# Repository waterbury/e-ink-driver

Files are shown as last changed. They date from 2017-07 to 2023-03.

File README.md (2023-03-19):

### Open-source hardware design
----------

#### Introduction

E-ink driver board based on designs by @kennethlimcp and others..

swedishhat has a bunch of these: http://wiki.ai-thinker.com/esp32-s

#### Useful writeups 

- [Bringing up a new board from scratch](/Resources/bring-up.md)
- [Checking a new PCB and populating it](/Resources/pcb-checks.md)
- [EAGLE start off and mistakes](/Resources/eagle-notes.md)

#### Resources

- [Hardware product development process](http://conceptspring.com/hardware-product-development-process/)

- [Spark Proto2Prod website](http://www.proto2prod.com/)

- [EAGLE Help](http://web.mit.edu/xavid/arch/i386_rhel4/help/index.htm)

- [Sparkfun EAGLE Settings](https://github.com/sparkfun/SparkFun_Eagle_Settings)

- [3D Board viewer](http://3dbrdviewer.cytec.bg/)

- [KiCad Software](http://www.kicad-pcb.org/)

- [Systematic PCB verification](https://engineering.purdue.edu/ece477/Resources/SystematicPCBVerification.pdf)

- [7 fatal pcb mistakes to avoid by Make](http://makezine.com/2016/08/15/7-fatal-mistakes-avoid-printed-circuit-board-pcb-design/)

- [Board Level Electromagnetic Compatibility](http://www.nxp.com/files/microcontrollers/doc/app_note/AN2321.pdf)

- [The Dropout’s Guide to PCB Trace Antenna Design](http://colinkarpfinger.com/blog/2010/the-dropouts-guide-to-antenna-design/)

- [Antenna Design and RF Layout Guidelines](http://www.cypress.com/file/136236/download)

- [Converting Seeed OPL EagleCAD library to KiCad](https://www.seeed.cc/Converting%20Seeed%20OPL%20EagleCAD%20library%20to%20KiCad-p-1990.html)

- [Wireless Protocols for IoT Devices](http://glowlabs.co/wireless-protocols/)

- [Capacitor temperature and voltage variation](https://www.maximintegrated.com/en/app-notes/index.mvp/id/5527)

- [Minimizing Buck-Boost Converter High-Frequency Switching Noise](http://www.ti.com/lit/an/slva219a/slva219a.pdf)

- [CAN-bus Common High Speed Physical Layer Problems](https://vector.com/portal/medien/cmc/application_notes/AN-ANI-1-115_HS_Physical_Layer_Problems.pdf)

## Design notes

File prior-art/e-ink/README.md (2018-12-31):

Wifi E-ink display
----------

### Introduction

The main motivation for this device comes from the regular use of 16x2 or nokia old-style LCD display. They are nice but too small for a sizeable project that requires a simple but viewable display from a distance.

This also challenges me to try out FPC connector that i have never handled before and at the same time design an entire system comprising from power to display signal driver.

The current revision of **V0.0.3** does not work as the I2C GPIO expander is unable to toggle the control pins at `us` resolution so a re-design has to be done. **V0.1.0** is a WIP to improve **V0.0.2** but is only a WIP and is not a working board as well.

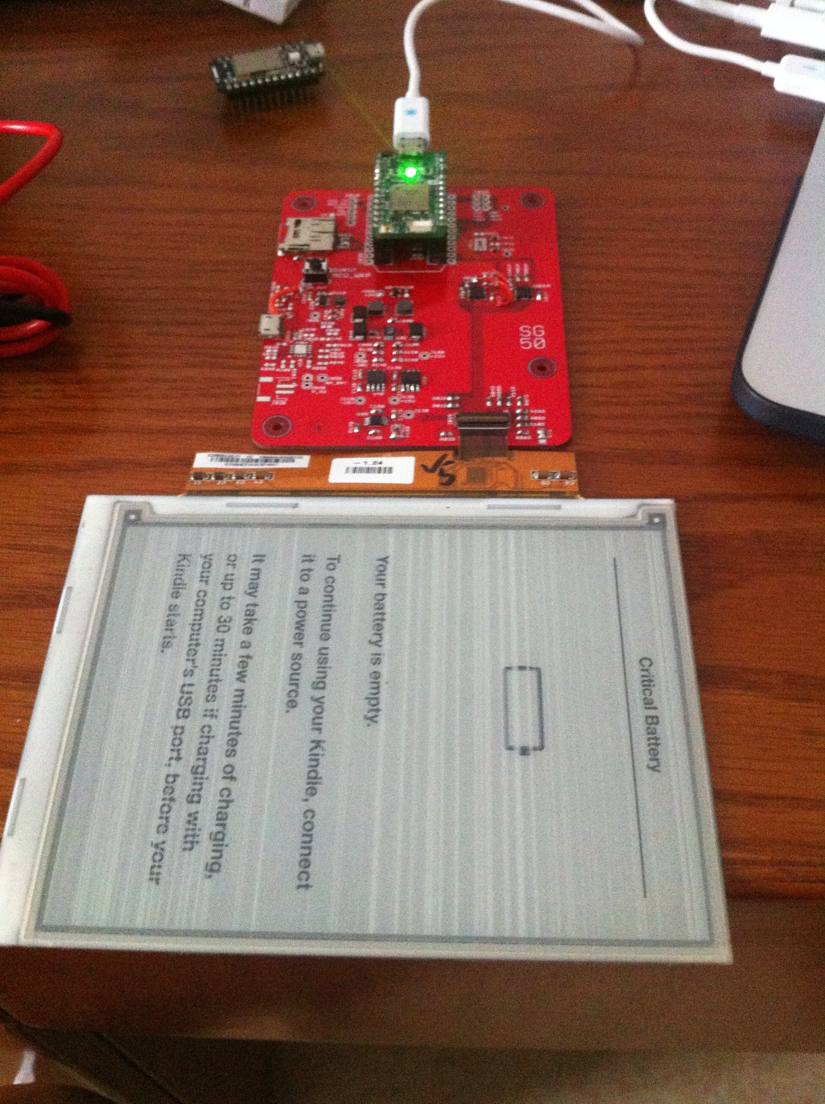
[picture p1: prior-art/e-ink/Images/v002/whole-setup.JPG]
eink-board


#### Power system

- USB +5V or single cell Li-ion
- Battery charging and simultaneous system supply
- 3V3 buck converter for primary rail

##### Input options
- microB USB
- jumper wire (+ and -)

##### E-ink supply notes

A LT1945 DC/DC converter is powered by VBAT from the 1-cell li-ion battery to provide the +22V and -20V required for the Gate supply. The next power stage comprises of a simple LDO (LM78(79)/L15) to generate +15V and -15V for the Source supply. There's a LTSPICE file available in this repository that shows the performance of the LT1945 through simulation. This design comes from the datasheet and the components have been properly sized to have beefy ratings.

There are newer ICs in the market that handles the entire power generation required to drive an e-ink display and they should be utilized in the new revision if they can be bought easily in the market. Otherwise, replacing the LDOs might be a considering to achieve better low power consumption in sleep mode.

VDD and VSS supply for the e-ink is powered using a GPIO as the current draw (according to the notes) is only 1mA and this allows up to turn off the display for power saving.

The SMPS power input is controlled using a simple P-channel MOSFET load switch technique to cut off supply when it is not required.

##### Battery power management design

After much sourcing and finding a part available in the Chinese market, I found the BQ24075 suitable for the job that provides a good mix of features. This IC allows a maximum input voltage of 28V and comes with over-voltage protection! No external inductor is required (compared to BQ24260). There's also 2 status signal that allows the MCU to know if there's an external power source connected and whether the battery is currently charging. This allows us to change the "power mode" of the device with faster go-to-sleep timing when there is not power source attached.

This addition low-cost circuit footprint is added for variety. A MCP7381T is used to charge a single cell Li-ion and the VBAT is directly fed to the system. This, however, does not allow the system to be powered up if a battery is not present.

#### Driver design notes

The e-ink display requires a fair bit of control pins and part of the reason is not fully understanding which pins are in use and necessary for driving. Therefore, to ensure a higher success rate during rev. 0.0.2, consideration is made to hook up all the exposed pins. Pins that are pulled high and low are also wired up with 0 ohm resistors for flexibility to test their purpose or change the pull voltage.

One design considered is to use 2 x 8 GPIO expander; one for the 8 bit data and another for the seldom toggled controls pins. There are 16 port GPIO expander in the market but having the data pins and control pins independent of each other during writes prevents accidental toggling of the incorrect pin that may result in a damaged display.

Another design is to use a separate MCU that connects directly to all the pins available but most of the Arduino options have low FLASH and RAM. The next notch up would result coding in C (MCU running some RTOS) which is too much to handle at this point in time.

The GPIO expander design is implemented for the initial rev to bring up the board with a Spark Core/Photon that is a beefier Arduino variant that allows us to avoid the low level path for now. Using an external MCU would definitely be a better path to take in future revisions. INT pins are not wired up as all the pins are used as OUTPUT.

#### Peripherals

These are implemented in rev 0.0.2:

- Accelerometer to determine screen orientation
- Temperature sensor, duh
- microSD card

future considerations:

- Gyrosensor (why?)
- BLE module (good for proximity control)
- light sensor for ambience detection

#### Casing

A laser cut casing would be great to house a useful demonstration set and avoid risk of damaging it from the hands of others!

#### Future expansion

- Use e-ink display driver IC
- Add in IR touch sensing technology used in latest Kindle
- Backlight will be awesome much

#### Lessons learnt

- Creating new footprints confidently (39-pin FPC connector, QFN-20)
- ULP script "bom.ulp" available to generate the BOM for a project. Makes it easier to manage the ever changing list of components
- ULP script "Unrouted" from Sparkfun will be useful instead of manually browsing through unrouted layer (but not that helpful..)
- need to turn on `STOP` for vias to be exposed without soldermasking
- Forgotten about teardrop ULP
- increase isolate for polygons to 0.012". Sparkfun says that would result in better yield instead of possible short
- it seems like we need to turn on the layers of concern during DRC or it will be missed out. Some silkscreen labels were "violating" some pads/vias and went unnoticed

**v0.0.2**

- need to add thermal vias for battery management IC
- updated battery related ICs label with additional "0" prefix (U01B, U02B, U03B, U04B, U05B)
- `SMPS_CTRL` pin for the LT1945 can only work without populating R12B as the GPIO port on the expander cannot be configured as an open drain to support the pull-up resistor. Have to set in code to use internal pull-up instead. Will need to consider adding an SOT-23 NPN transistor to control the on/off.
- BQ24072/3/4 might better with lower OUT voltage for next stage +3V3 step down
- Use 2K Ohm for R08B to set ILIM for BQ24075
- missed out "insert here" label for J02S
- SJ1 solder jumper can be smaller
- keepout for U03M needs to be included in the design consideration and GERBER generation
- changed OSHW logo to customized for it to be an exposed shiny silver logo :)
- made "SG 50" font a vector, 20% ratio
- incorrect J02M label, was flipped

- spaced out components to be more hand-solderable
- extend the USB pads to be more hand-solderable
- added slide switch
- RST for MCP23008-E needs to be externally biased
- R0xx should be wired to +3V3 instead of EINK_VDD
- some issue with +20v where voltage is present even when disabled

#### Resources

Understanding the wiring for e-ink display would not be possible with the information shared by two pro open-source gentlemen.

- [essential scrap](http://www.essentialscrap.com/eink/index.html)
- [SpriteMods](http://spritesmods.com/?art=einkdisplay)
- [Ti Dev board](http://www.ti.com/tool/TIDM-LPBP-EPAPER)
- [SSD1606 driver](http://www.lcd-module.de/fileadmin/eng/pdf/zubehoer/ssd1606_1_1.pdf)
- [OnSemi driver](http://www.onsemi.com/pub_link/Collateral/ENA2223-D.PDF)
- [Eink reseach paper](http://aoe.scnu.edu.cn/uploadfile/2014/0508/20140508112156532.pdf)
- [STM32L0 discovery board](http://www.st.com/st-web-ui/static/active/en/resource/technical/document/user_manual/DM00118944.pdf)
- [Pebble Time teardown](https://www.ifixit.com/Teardown/Pebble+Time+Teardown/42382)
- [Pebble Watch teardown](https://www.ifixit.com/Teardown/Pebble+Teardown/13319)
- [RePaper code](https://github.com/repaper/gratis)
- [Freescale i.MX50](http://cache.freescale.com/files/32bit/doc/data_sheet/IMX50CEC.pdf)
- [GDE021A1 display project](http://www.jsykora.info/2014/06/epd-display-working/)
- [Amazon Kindle source code](http://www.amazon.com/gp/help/customer/display.html?nodeId=200203720)
- [E-ink display](http://www.buy-lcd.com/index.php?route=product/category&path=2897)
- http://www.eevblog.com/forum/microcontrollers/interfacing-epd-(e-ink)-display-from-kindle-anyone-tried
- [EPSON controller module](http://www.mouser.com/catalog/specsheets/x93ac002_f01__(S4E5B001B00A00_Product_Brief_Rev_1.0)[1].pdf)
- [Epaper shield](http://epapershield.com/index.htm)

- [PVI docs](http://wenku.baidu.com/view/c54385ea6294dd88d0d26b94.html)
- [Epson ppt](http://wenku.baidu.com/view/e451453567ec102de2bd8908.html)

#### Appnote

- MOSFETS in load switch applications(AND9093D)
- Reverse current/battery protection circuit (SLVA139)
- Resistor decade table (dectable)
- [USB disconnect circuit](https://developer.mbed.org/media/uploads/chris/mbed-005.1.pdf)
- [I2C resistor calculation](http://www.ti.com/lit/an/slva689/slva689.pdf)

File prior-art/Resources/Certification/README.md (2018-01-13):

### Certification standards

#### PCB

Printed circuit boards are usually certified with Underwriters Laboratories (UL) standards.

A database is available to check a manufacturer for UL certification at: http://database.ul.com/cgi-bin/XYV/template/LISEXT/1FRAME/index.htm

The UL category code to search for:
- Printed Wiring Boards (ZPMV2)
- Flexible Printed Wiring Boards (ZPXK2)
- Laminates (QMTS2)
- Printed Wiring Boards (QMJU2)

Parameters:
- Flame class
- Maximum operating temperature (MOT)
- Direct Support Requirements (DSR)
- Comparative Tracking Index (CTI)
- Multiple Solder Limits

Tests:
- UL94 - [Standard for Tests for Flammability of Plastic Materials for Parts in Devices and Appliances
Purchase UL 94
](https://standardscatalog.ul.com/standards/en/standard_94_6)

Material:
- [UL PCB Recognition](https://www.ncabgroup.com/wp-content/uploads/2015/03/UL-Emma-Hudson-NCAB-Seminar-2015-03.pdf)

#### Specification
- [MIL-PRF-38535 United States military specification](https://en.wikipedia.org/wiki/MIL-PRF-38535)

#### Manufacturing

- [IPC-A-610 Acceptability of Electronics Assemblies Training and Certification Program](http://www.ipc.org/ContentPage.aspx?pageid=IPC-A-610)
- Solder Paste Inspection, Automated Optical Inspection and X-ray examination are all carried out during manufacture followed by PCB testing and finally burn in testing 

#### Quality
- [ISO 9001:2015](https://www.iso.org/iso-9001-quality-management.html)

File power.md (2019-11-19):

# Power for LG LB060S01-RD02 E-Ink Display

| Rail |  Min  | Nominal |  Max  |
|:----:|:-----:|:---:|:-----:|
| GVEE |  -22V | -20V |  -15V |
| GVDD |  +15V | +22V |  +23V |
| VPOS | +9V | +15V |  +17V |
| VDD  | +2.8V | +3.3V | +3.6V |
| VNEG |  -17V | -15V | -9V |
| VCOM | -2.5V | | -0.5V |

Power on sequence
1. VDD
2. VNEG, GVEE
3. VPOS
4. Input Signals, GVDD

Power off sequence
1. Input Signals
2. GVEE, VGDD, VPOS, VNEG
3. VDD

I _THINK_ the datasheet is trying to say that the timing gap between rails is >= 5ms and <= 100ms

Basically, I think we should either 
(a) assume the shit magically starts up in order
(b) don't apply _any_ power to the display unless a sufficiently long period of time has passed

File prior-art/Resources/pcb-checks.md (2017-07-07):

### Verifying and populating a new PCB

#### Things to prepare
- Schematic printout
- Parts layout/orientation printout
- Multimeter
- Clamping vise (nice to have)
- ye' old tweezer
- Solder spool(0.3mm is ideal for dealing with SMD parts)
- Solder wick-(ed) (this is going to be invaluable)
- Solder paste (if you are reflowing)
- Scrapper (to spread peanut butter..opps Solder paste)

#### Systematic verification steps

**Checking the bare PCB**
- Test for short between power lines. eg. 5V and GND
- Supply power and check that power pins are receiving the correct voltage

**Preparing to populate!**
- Lay out your parts neatly and have an idea of which part gets placed first and which goes next
- Have a spacious work area as entropy will spontaneously increase and things get disorganized
- Place your print-out somewhere within sight for easy referencing

**Populating the PCB (by hand)**
- Start off by populating the smallest and toughest package. eg. QFN before through hole
- **Remember** that **solder flux** is your best friend! Apply sparingly to the pad to be soldered before continuing
- Look out for the polarity and "pin 1" position before soldering down each part
- Solder one "leg" to hold the part in place, double-check that the orientation is correct before continuing. This will save you a ton of heartache/desoldering
- Perfection is great but a burnt component is not. As long as the component is properly in place, (i know it's hard to resist having a perfectly oriented part) move on to the next one!
- If you are not confident that the parts are properly soldered, whip out your trusty multimeter and test for connector from each leg to the respective end-point

***Special notes***
- Solder one part, check for goodness before moving on
- As you solder, visually inspect the board and make sure the part is not "tombed"
- For IC, be sure to apply some pressure to solder them firmly on the pad (not floating)

**Populating the PCB (for reflow)**
- If you are doing this process, you probably have a stencil ready to spread the Solder paste
- Grab some spare pcbs or material and stick them down on the work area to serve as a jig so that the PCB stays in place while you spread solder paste. Imagine something like a "L" shape where the pcb can be pushed against
- Align your stencil and scrap the solder paste through! Place enough solder paste and do a smooth one-time apply.
- It is not recommended to go back and forth too many times so... do it once, do it good! Practice makes perfect for this step
- Once that is done, carefully populate each component before sending the PCB for baking/reflow

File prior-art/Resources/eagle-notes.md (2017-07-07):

EAGLE tips and advice
---

### Grouping things up

If you are a beginner, switching over to the Board view with a whole bunch of components clustered together might be overwhelming. The recent project i worked on has close to 100 components and that required me to do something about it before even beginning to do routing work.

What it did was to refer to the schematic and move things that are supposed to be together...together.

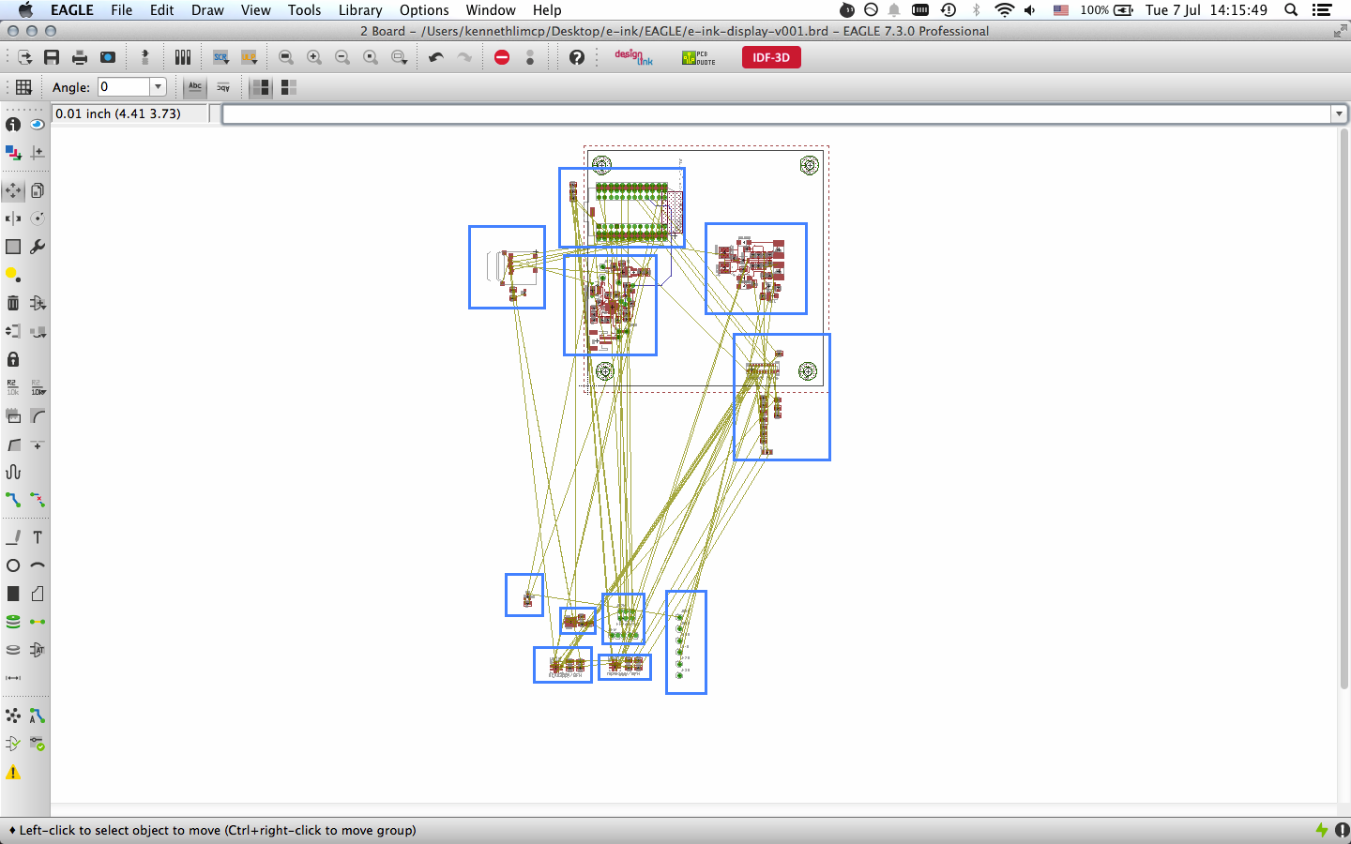
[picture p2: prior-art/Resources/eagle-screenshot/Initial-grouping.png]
group-sections


This is helpful when bypass/decoupling capacitors go to the correction section and placed at where they are designed to be.

### Running a DRC after initial routing

This is a pretty useful tool and a MUST use. Here's some examples of the errors detected by the tool recently.

**insufficient clearance between a via and trace**

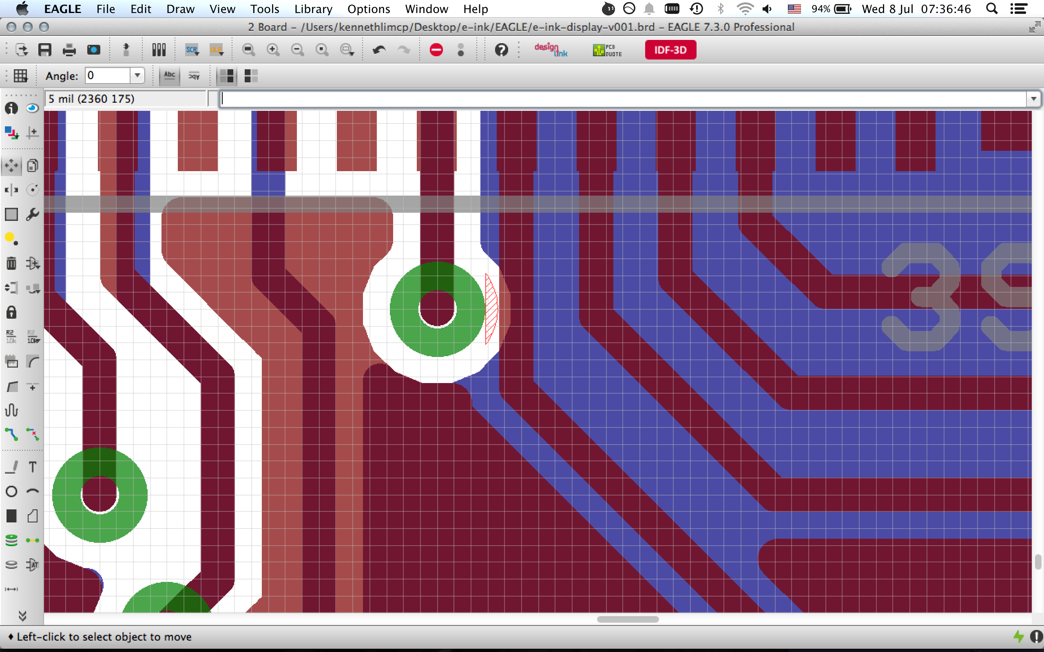
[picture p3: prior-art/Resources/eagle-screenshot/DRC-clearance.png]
DRC-clearance


**trace touching pads along the way**

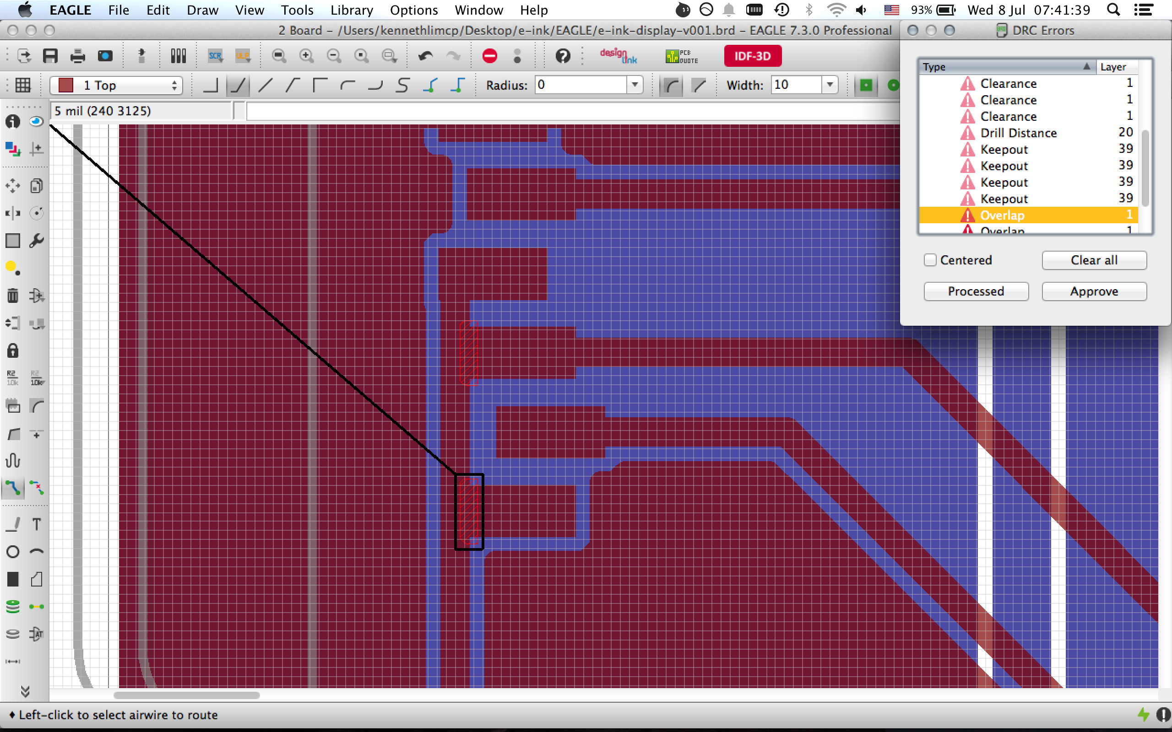
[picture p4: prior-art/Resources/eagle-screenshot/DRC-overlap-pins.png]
DRC-overlap-pins


**trace cutting acrossing another trace**

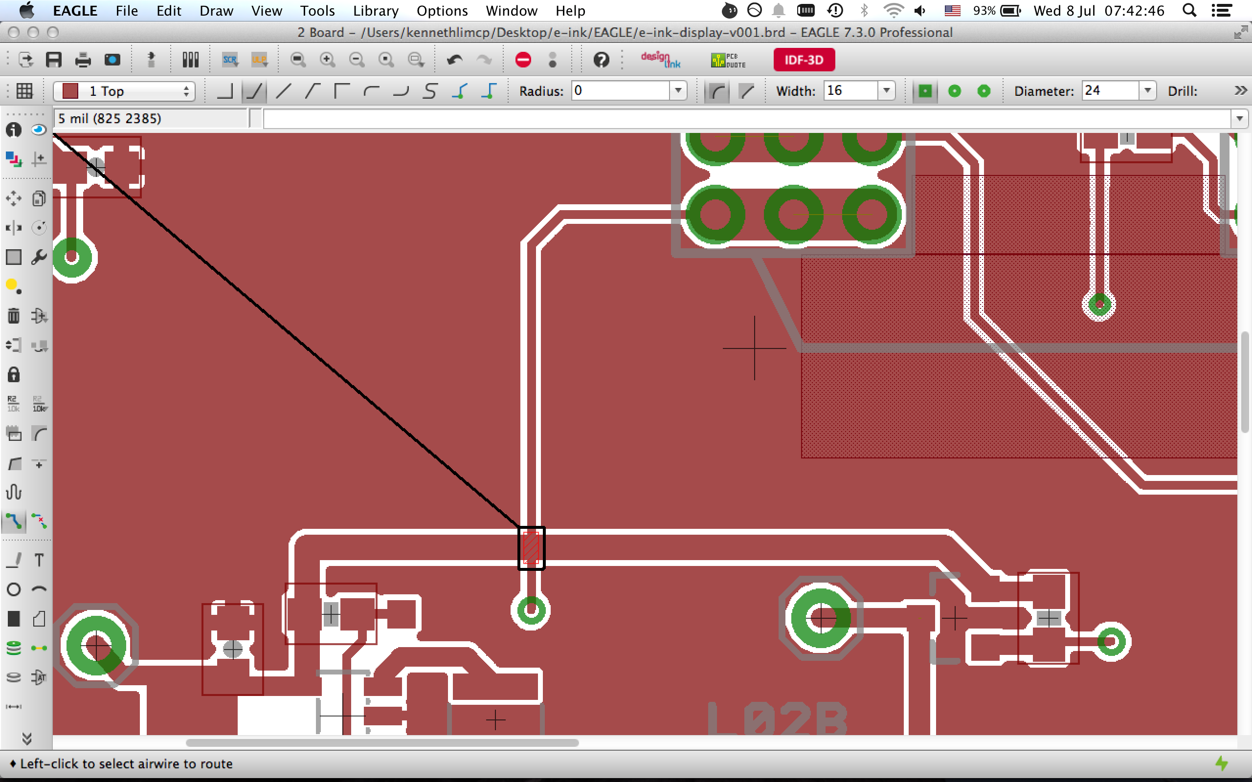
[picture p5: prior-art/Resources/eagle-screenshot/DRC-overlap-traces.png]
DRC-overlap-traces


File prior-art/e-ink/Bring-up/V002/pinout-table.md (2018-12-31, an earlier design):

Battery Management
---

####Input

- VUSB
- Header pins (with diode protection)

####Control pins
- CE (enable/disable charger)
- BM_SYSOFF (con/discon battery to system output)

####Output
- BM_OUT (battery positive voltage)
- PGOOD (external power attached)
- CHG (battery charging)
- ISET (charging current-->voltage)

3V3 Buck regulator
---

####Input
- BM_OUT
- Enable pin

####Output
- +3V3

DC/DC converter
---

####Input
- BM_OUT

####Control pins
- NEG_EN
- POS_EN
- SMPS_CTRL

####Output
- -20V
- +22V

+15V linear regulator
---

####Input
- +22V
####Output
- +15V

-15V linear regulator
---
####Input
- -20V

####Output
- -15V

LM358 Opamp
---

####Input
- +15V
- -15V

####Output
- VCOM negative voltage

e-ink display
---

####Input
- +15V
- -15V
- +22V
- -20V

####Control pins (15)
- D0-D7
- GMODE2
- U1SPV
- U1CKV
- CL
- LE
- OE
- SPH
- E_INK_VDD

####Output
- VCOM negative voltage

GPIO expander (e-ink data line)
---
####Input (ascending)
- D0-D7

####Control pins (15)
- SCL
- SDA
- INT (not using as all will be OUTPUT pins)
- RST

GPIO expander (control line)
---
####Input (ascending)
- CL
- LE
- OE
- SPH
-
-
- NEG_EN (DC/DC)
- POS_EN (DC/DC)

####Control pins (15)
- SCL
- SDA
- INT (not using as all will be OUTPUT pins)
- RST

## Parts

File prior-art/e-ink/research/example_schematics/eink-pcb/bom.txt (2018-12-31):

Order numbers are for Digikey

L1, L2: 22uH					587-2103-1-ND
IC1: LT1945						LT1945IMS#PBF-ND
IC2: MC79L15					MC79L15ABDGOS-ND
IC3: L78L15						497-7278-1-ND
IC4: TPS78230					296-24372-1-ND
IC5: LM358						LM358DGOS-ND
IC6: MCP73831					MCP73831T-2ATI/OTCT-ND
IC7, IC8: 74LV4094				568-2976-5-ND
D1-D3: SS24						SS24T3GOSCT-ND
D4: 0603 LED					
C2, C4, C5, C6, C7, C8: 2U2 >25V!	490-10486-1-ND
C3, C11, C12: 4u7 6.3V			1276-1045-1-ND
C1, C9, C10, C13, C14: 100nF	1276-1857-1-ND (per 1000 bestellen?)
C15, C16: 100uF					1276-1782-1-ND

All resistors 0603
R9: 470 ohm
R15: 1K
R10: 2K
R14: 4K7
R11, R12, R13: 10K
R2, R3: 33K
R5, R6: 39K
R8: 200K
R1: 470K
R4: 560K
R7: 47K
VR1: 100K trimmer PVZ3A473C01R00			490-2016-1-ND

CON1: FH26-39S-0.3SHW	HFQ339CT-ND
CON2: USB header (Hirose)
Q1, Q2:  IRLML6402TRPBF (SOT-23 P-chan mosFET)

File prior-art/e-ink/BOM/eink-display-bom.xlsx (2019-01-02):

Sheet: v002
PROJECT NAME |  | Wifi E-ink Display
BOM VERSION |  | v0.0.2
 | Critical to the PCB Design. Cannot be substituted without changes to PCB
 | Consigned by owner
 | Important to the design. Approved Vendor and P/N can be substituted with equivalent pinout and specifications
 | Non-critical Component. Vendor and P/N should be determined by cost and local availability
Qty | Device | Minimum Specification | Package/Case | Part Designator | MFG. | MFG. PN
1 | FAB PCB | Double Sided, 1.6mm, 1OZ, Electroless Nickel Immersion Gold, Green Solder Mask, White Silkscreen
1 | Battery management | 28V Vmax, system pass-through | QFN-16 | U01B | TI | BQ24075RGTR | 0.8 | 0.8
1 | Buck Converter, SMPS | 3.3V, 600mA | SOIC-8 | U2B | RICHTEK | RT8008-33GB
1 | DC/DC Dual output Converter | Postive and negative output | SOT-223 | U3B | LT | LT1945IMS#PBF | 0.6 | 0.6
1 | REGULATOR | 100mA,-15V, Vin min < 20V | SOIC-8 | U4B | TI | LM79L15ACM/NOPB | 0.6 | 0.6
1 | REGULATOR | 100mA,+15V, Vmax < -22V | SOIC-8 | U5B | TI | LM78L15ACMX/NOPB
1 | OPAMP |  | MSOP-8 | U6B | TI | LM358DGKR
2 | GPIO EXPANDER | I2C, 8 PORT | QFN-20 | U01M,U02M | MICROCHIP | MCP23008-E/ML
1 | PHOTON | BM-09 MODULE | - | U01M | PARTICLE
1 | ACCELEROMETER | 3-axis , 13bit, +-16g | 3 mm × 5 mm × 1 mm LGA | U01S | AD | ADXL345BCCZ
3 | SCHOTTKY DIODE, POWER | Vf 0.5V, 40V, 2A | DO-214AA | D03B,D04B,D05B | ONSEMI | SS24T3G | 0.4 | 1.2
4 | LED | RED | 603 | D01B, D01S, D02B, D06B
2 | INDUCTOR | 22uH, 0.37 DCR, 800mA | 4 x 4 mm | L02B,L03B | MURATA | LQH44PN220MP0L | 0.29 | 0.58
1 | INDUCTOR | 2.2uH, 1.5A | 3 x 3 mm | L01B | TAIYO YUDEN | NR3015T2R2M
1 | CERAMIC CAPACITOR | 4.7pF, Ceramic, 50V, 10%, C0G 0603 | 603 | C10B | MURATA | GRM1885C1H4R7CA01D | 0.01 | 0.01
4 | CERAMIC CAPACITOR | 4.7uF, Ceramic, 50V, 10%, C0G 0603 | 603 | C02B,C03B,C04B,C09B | MURATA | GRM1885C1H4R7CA01D | 0.01 | 0.04
12 | CERAMIC CAPACITOR | 0.1uf, Ceramic, 50V, 10%, X7R | 603 | C01M, C01S, C02M, C03S, C04S, C06B, C07B, C12B, C14B, C15B, C16B, C17B | YAGEO | CC0603KRX7R9BB104 | 0.01 | 0.12
1 | CERAMIC CAPACITOR | 100pf, Ceramic, 50V, 10%, X7R | 603 | C08B | YAGEO | CC0603KRX7R9BB101 | 0.01 | 0.01
3 | CERAMIC CAPACITOR | 1uf, Ceramic, 50V, 10%, 57R | 603 | C01B, C11B, C13B | MURATA | GRM188R61H105KAALD | 0.01 | 0.03
1 | CERAMIC CAPACITOR | 10uf, Ceramic, 50V, 10%, 57R | 603 | C02S | MURATA | GRM188R61H105KAALD | 0.01 | 0.02
1 | CERAMIC CAPACITOR | 22uf, Ceramic, 50V, 10%, 57R | 603 | C05B | MURATA | GRM188R61H105KAALD | 0.01 | 0.01
18 | RESISTOR | 0 Ohm, 1%, 125mW, 50V | 603 | R01D, R01M, R02D, R02M, R03B, R03D, R03M, R04D, R04M, R05D, R05M, R06D, R06M, R07D, R08D, R09D, R10D, R11D |  |  | 0.01 | 0.01
4 | RESISTOR | 1K, 1%, 125mW, 50V | 603 | R01B, R02B,R09B,R01S |  |  | 0.01 | 0.02
1 | RESISTOR | 2K, 1%, 125mW, 50V | 603 | R08B
2 | RESISTOR | 4.7K, 1%, 125mW, 50V | 603 | R08M,R09M
1 | RESISTOR | 470K, 1%, 125mW, 50V | 603 | R13B |  |  | 0.01 | 0.01
1 | RESISTOR | 560K, +-1%, 100mW, 75V | 603 | R15B
2 | RESISTOR | 33K, +-1%, 100mW, 75V | 603 | R14B,R16B
1 | RESISTOR | 200K, +-1%, 100mW, 75V | 603 | R17B |  |  |  | 4.06
2 | RESISTOR | 10K, +-1%, 100mW, 75V | 603 | R10B,R12B,
1 | RESISTOR | 100K, +-1%, 100mW, 75V | 603 | R11B
1 | RESISTOR (Variable) | 100K, +-25%, 100mW,± 250ppm/°C | - | R18B | BOURNS | TC33X-2-104E
1 | CONNECTOR - FPC | 0.3mm pitch, 39 contacts | SMD | J02S | HIROSE | FH26-39S-0.3SHW(05) | 1.6 | 1.6
1 | CONNECTOR - JST | 2PIN, 2MM PITCH, SMD | - | J03B
1 | CONNECTOR - microUSB | 5pin, SMD | - | J07B
10 | HEADER |  | 1x01, 0.1" pitch | J01B, J02B, J05B, J06B, J08B, J09B, J10B, J11B, J12B, J13B
1 | HEADER |  | 1x02, 0.1" pitch | J04B
1 | HEADER |  | 1x05, 0.1" pitch | J01M
1 | HEADER |  | 2x3, 0.1" pitch | J02M
2 | HEADER - FEMALE |  | 1x12, 0.1" pitch | U03M
1 | P-CHANNEL MOSFET | Rds 0.065, VDSS = -20V, -3.7A | SOT-23 | Q01B | IR | IRLML6402TRPbF
1 | SOCKET | micoSD, SMD | - | J01S
1 | E-INK DISPLAY | 6", 39 PIN | 6" | - | PRIMEVIEW | ED060SC4
1 | TACT SWITCH | 4 PIN | - | SW01M
1 | BATTERY HOLDER | PTH, CR2302, 20mm height |  | J03M
 |  |  |  | Parts count: | 99

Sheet: CHANGELOG
Subject: | BOM ECO
Project Name: | WIFI E-INK DISPLAY
BOM Rev.: | V0.0.3
PCB Rev.: | V0.0.1
Date | 2015-07-15
Prepared by: | Lim Chen Pin Kenneth
Project Name
Item | BOM Revision |  | Project Name | Change Details | Date | Responsible
 | Old | New
1 | 0 | 0.0.1 | WIFI E-INK DISPLAY | Initial Entry for all components (new spin up) | 2015-03-15 | KLCP
2 | 0.0.1 | 0.0.2 | WIFI E-INK DISPLAY | changed R6,R7 to C10, C11 for reguators | 2015-07-02 | KLCP
3 | 0.0.2 | 0.0.3 | WIFI E-INK DISPLAY | updated labels and components | 2015-07-06 | KLCP
4
5
6
7
8
9
10
11
12
13
14
15
16
17
18
19
20
21
22
23
24
25
26
27
28
29
30
31
32
33
34
35
36
37
38
39
40
41
42
43
44
45
46
47
48
49
50
51
52
53
54
55
56
57
58
59
60
61
62
63
64
65
66
67
68
69
70
71
72
73
74
75
76

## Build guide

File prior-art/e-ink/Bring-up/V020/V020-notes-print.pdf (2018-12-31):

### Bring-up notes

**Major components populating**

- [ ] microUSB (this was nasty in V002)
- [ ] FPC connector
- [ ] BM IC
- [ ] LT1945
- [ ] LM358

**Test sequence**

- [ ] 3V3 SMPS regulator
- [ ] jumper +5V to BM_SUPPLY
- [ ] measure the 3V# test-point
- [ ] BMIC
- [ ] battery should charge as designed upon USB insertion
- [ ] See if SUPPLY led lights up with USB presence
- [ ] CHG should light up with Batt attached
- [ ] DC/DC converter
- already proven working but nevertheless we check it
- Power up and make sure no voltage at J06B
- wire TP1 to ground to turn on Q01B
- Check that only J07B has -20V and J08B is 0V
- wire TP2 to ground and check J08B for +22V
- [ ] Linear regulators
- Nothing much here. Populate and measure
- J09B, -15V
- J10B, +15V
- [ ] VCOM Opamp
- populate and measure J11B while turning trimmer at R18B
- [ ] MCU
- [ ] Populate U01M, the STM32
- [ ] Crystals Y01M, Y02M next
- [ ] Decoupling caps, C05M to C10M
- [ ] RGB led, D02M and R01M to R03M
- [ ] Blue led, D01M and R05M
- [ ] Buttons!
- [ ] USB disconnect circuit
- we will come back to test the alt circuitry next time
- JTAG header
- [ ] MCU testing
- [ ] wire up STlinkV2 to JTAG header
- [ ] power up the board via USB as well
- [ ] attempt to flash bootloader code and pray that everything works well!
- [ ] Eink components
- [ ] just all the remaining resistors and decoupling caps to go on
- [ ] Last bit
- [ ] Accelerometer
- [ ] SD socket
- [ ] battery holder
- [ ] FTDI header
- Official tests
- [ ] make sure all the GPIOs are correctly configured
- [ ] MODE button test
- [ ] DC/DC power control tests
- [ ] Battery indicator input reading
- [ ] time to insert the Eink!

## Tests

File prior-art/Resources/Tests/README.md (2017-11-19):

#### Board level

- Solder Paste Inspection
- Automated Optical Inspection 
- X-ray examination

#### Product level

- Shock and vibration
- EMC / EMI
- UL
- Ex (ATEX Equipment Directive 2014/34/EU)
- DNV
- Burn-in
- Thermal Cycling (JESD22-A104 , IPC 9701)

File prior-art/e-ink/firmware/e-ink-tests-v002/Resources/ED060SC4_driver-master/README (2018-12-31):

1. Introduction

This is a driver for ED060SC4 800x600 e-ink display panel manufactured by
Prime View. Note that this driver uses a direct connection to the panel from
the processor; it does not use a separate controller chip between the processor
and the panel.

To use the driver, you need to be able to control the following signals from
your processor:

Gate driver: SPV, CKV, GMODE.
Source driver: CL, LE, OE, SPH, D0-D7.
Power supply: +-15V, +22V, -20V, digital Vdd

The file "example_schematics.png" shows how to connect the signals to e.g. a
STM32L151 microcontroller. It also includes an example circuit for providing
the panel supply voltages.

Note that the larger panels (such as the 800x600) consist of multiple segments
with separate gate driver signals. These can be daisy chained as shown in the
example schematic.

Please see here for more information on the panel:
http://essentialscrap.com/eink/

2. Frame buffer emulation

Because there is not enough memory to store a full frame buffer on the
processor, this driver emulates a frame buffer by storing the display data in
blocks. It will buffer up to EINK_NUMBUFFERS blocks and then write them to the
screen. The following #defines control the buffering. Larger numbers will
result in faster drawing, but also use more RAM on the processor:

#define EINK_BLOCKWIDTH 20    // Width of a single block in buffer
#define EINK_BLOCKHEIGHT 20   // Height of a single block in buffers
#define EINK_NUMBUFFERS 40    // Number of blocks to buffer

After drawing your images, you should flush the buffers using the following
command:

    #include <ed060sc4.h>
    gdispControl(GDISP_CONTROL_FLUSH, 0);

The buffers are also flushed whenever you turn the display off using:

    gdispSetPowerMode(powerOff);

3. Display clearing and writing waveforms

This driver does not know the official Prime View waveforms for driving the
display, mostly because those are trade secrets and not publicly available.
Instead, it uses reverse engineered waveforms that are mostly functional.

The following #defines control the waveforms:

#define EINK_BLINKCLEAR TRUE      // Clear to opposite color first
#define EINK_CLEARCOUNT 10        // Number of sweeps to clear the display
#define EINK_WRITECOUNT 4         // Number of sweeps when writing to display

Increasing the clearcount and writecount can improve contrast, but will also
slow down the drawing and use more power.

4. Clock speeds

Because the driver bit bangs the display, the clock frequency of the processor
is quite significant. This is controlled by EINK_CLOCKDELAY variable. Set it
so that the delay is atleast 50 nanoseconds.

5. Support for other kinds of panels

Most of the Prime View panels should work using this driver, but only ED060SC4
has been tested so far. Some points of consideration:

- Some displays may use 4 bits per pixel. The driver currently assumes 2 bits
  per pixel.
- Larger displays may require some other way of daisy chaining than shown in
  the example schematics.

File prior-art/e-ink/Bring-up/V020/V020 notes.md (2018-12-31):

### Key changes from V0.0.2
- Using a STM32F103RBT6 with direct GPIO connection
- breakout most pins
- MODE and Reset button
- JTAG, UART headers
- SPI test points
- separated ground plane for battery charging, DC/DC module and MCU

### To prepare
- [ ] Schematic print-out
- [ ] Parts
- [ ] Placement diagram
- [ ] this notes

### Bring-up notes

**Major components populating**

- [ ] microUSB (this was nasty in V002)
- [ ] FPC connector
- [ ] BM IC
- [ ] LT1945
- [ ] LM358

**Test sequence**

- [ ] 3V3 SMPS regulator
  - [ ] jumper +5V to BM_SUPPLY
  - [ ] measure the 3V# test-point

- [ ] BMIC
  - [ ] battery should charge as designed upon USB insertion
  - [ ] See if SUPPLY led lights up with USB presence
  - [ ] CHG should light up with Batt attached

- [ ] DC/DC converter
  - already proven working but nevertheless we check it
  - Power up and make sure no voltage at J06B
  - wire TP1 to ground to turn on Q01B
  - Check that only J07B has -20V and J08B is 0V
  - wire TP2 to ground and check J08B for +22V

- [ ] Linear regulators
  - Nothing much here. Populate and measure
  - J09B, -15V
  - J10B, +15V

- [ ] VCOM Opamp
  - populate and measure J11B while turning trimmer at R18B

- [ ] MCU
  - [ ]  Populate U01M, the STM32
  - [ ]  Crystals Y01M, Y02M next
  - [ ]  Decoupling caps, C05M to C10M
  - [ ]  RGB led, D02M and R01M to R03M
  - [ ]  Blue led, D01M and R05M
  - [ ]  Buttons!
  - [ ] USB disconnect circuit
  - we will come back to test the alt circuitry next time
  - JTAG header

- [ ]  MCU testing
  - [ ] wire up STlinkV2 to JTAG header
  - [ ] power up the board via USB as well
  - [ ] attempt to flash bootloader code and pray that everything works well!

- [ ] Eink components
  - [ ] just all the remaining resistors and decoupling caps to go on

- [ ] Last bit
  - [ ] Accelerometer
  - [ ] SD socket
  - [ ] battery holder
  - [ ] FTDI header

- Official tests
  - [ ] make sure all the GPIOs are correctly configured
  - [ ] MODE button test
  - [ ] DC/DC power control tests
  - [ ] Battery indicator input reading
  - [ ] time to insert the Eink!

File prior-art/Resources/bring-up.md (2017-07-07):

Steps taken
---

### Plan out the high level features

eg.

- Wifi enabled
- Wireless charging
- Battery management
- orientation detection

### Select all the key ICs

- ensure that parts are source-able
- study known designs (eg. adafruit, sparkfun, bunniestudios) and evaluate the best IC for that project
- select the best MCU for the job

### Prepare the project files

- Follow the current directory tree and create a new forked version
- start off with a `0.0.1` schematic design
- use a `FRAME-A4L` from Sparkfun for the layout
- create the global attributes (CNAME, CREVISION, DESIGNER)
- give that page a description of what it contains

### Start off laying out the power module
- This will be the best place to kick off!
- Create them and label the NET with the appropriate voltage values

### Key points

- Decoupling caps everywhere. Every time an IC is placed, a bypass/decoupling Cap should follow next.
- Think of pins where flexibility is required and use a 0604 0 Ohm resistor.
- Come out with a `pin-out table` if there are too many pins to be inter-connected.
- Save each datasheet (MANU-SHORTFORM_PART-NO) as you work so that you don't forget
- Write the `README.md` as you go or even at the beginning of the project so that key features are decided before starting work. This helps me decide which IC containing the required features is used.
- Write out a checklist on paper and tick them when you are done. Yeah i know digital is cool but pen and paper is rock solid.

### Some dimensions

- For silkscreen, mm, 1.27, 20%, Vector font works great
- Via, inches, round, Drill 0.01968504, Diameter 0.05
- Via, mm, round, Drill 0.5mm, Diameter 1.27mm
- For polygon, set **isolate** to `0.012inch/12mil"`
- For routing, mil, 12

### Labels

- IC                (Uxx/B/M/C/R), where the suffix tells which module it relates to eg B is for battery
- Resistor          (Rxx/B/M/C/R)
- Capacitor         (Cxx/B/M/C/R)
- Inductor          (Lxx/B/M/C/R)
- Diode/LED         (Dxx/B/M/C/R)
- FET/Transistor    (Qxx/B/M/C/R)
- Header/Connectors (Jxx/B/M/C/R)
- Switch            (SWxx/B/M/C/R)

### Checks after initial routing completion

- turn off layers and look for "unrouted" wires and see what's going on
- Run a DRC check
- smash all the labels and change to 1.016, 20%, vector, mm as a minimum
- Add other labels like "+" for battery, jumper labels etc.
- finalize mounting hole position by entering co-ordinates manually for accuracy
- Add in license and OSHW logo, designer name, designed in Singapore, date, revision

```text
Copyrights: CC-BY-SA 3.0
Designed in Singapore 07/15
Project name rev x.x.x
Apache License 2.0
@kennethlimcp
````

- print-out and check for silkscreen visibility
- final DRC rule cos it does not hurt
- make a copy of the `.sch` and `.brd` and run the `teardrop` ULP. That will make the vias/pads stronger with increased trace surface area
- zip up all the GERBERS!

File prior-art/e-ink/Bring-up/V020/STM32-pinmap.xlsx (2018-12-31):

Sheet: F103RBT6
Label | STM32 No | Remarks | 5 V? | ADC | TIMER | UART | SPI | JTAG | I2C | Core HW | Eink desp | Eink No
BOOT0 | 60 | BOOT0 |  |  |  |  |  |  |  |  | VNEG -15v | 1 | DIRECT
NRST | 7 |  |  |  |  |  |  |  |  |  | VPOS +15V | 2 | DIRECT
PA00 | 14 | WKUP |  | ADC12_IN0 | TIM2_CH1_ETR | USART2_CTS |  |  |  | A0 | VSS | 3 | DIRECT
PA01 | 15 |  |  | ADC12_IN1 | TIM2_CH2 | USART2_RTS |  |  |  | A1 | VDD | 4 | DIRECT
PA02 | 16 |  |  | ADC12_IN2 | TIM2_CH3 | USART2_TX |  |  |  | TX | CL | 5 | DIRECT
PA03 | 17 |  |  | ADC12_IN3 | TIM2_CH4 | USART2_RX |  |  |  | RX | LE | 6 | DIRECT
PA04 | 20 |  |  | ADC12_IN4 |  | USART2_CK | SPI1_NSS |  |  | A2 | OE | 7 | DIRECT
PA05 | 21 |  |  | ADC12_IN5 |  |  | SPI1_SCK |  |  | A3 | SHR | 8 | NC/DIRECT
PA06 | 22 |  |  | ADC12_IN6 | TIM3_CH1 |  | SPI1_MISO |  |  | A4 | CE1 | 9 | NC/GND
PA07 | 23 |  |  | ADC12_IN7 | TIM3_CH2 |  | SPI1_MOSI |  |  | A5 | CE2 | 10 | NC/3V3
PA08 | 41 | MCO | YES |  | TIM1_CH1 | USART1_CK |  |  |  | LED2 | SPH | 11 | DIRECT
PA09 | 42 |  | YES |  | TIM1_CH2 | USART1_TX |  |  |  | LED3 | D0 | 12 | DIRECT
PA10 | 43 |  | YES |  | TIM1_CH3 | USART1_RX |  |  |  | LED4 | D1 | 13 | DIRECT
PA11 | 44 | CANRX | YES |  | TIM1_CH4 | USART1_CTS |  |  |  | USBDM | D2 | 14 | DIRECT
PA12 | 45 | CANTX | YES |  | TIM1_ETR | USART1_RTS |  |  |  | USBDP | D3 | 15 | DIRECT
PA13 | 46 | JTMS | YES |  |  |  |  |  | D7 |  | D4 | 16 | DIRECT
PA14 | 49 | JTCK | YES |  |  |  |  |  | D6 |  | D5 | 17 | DIRECT
PA15 | 50 | JTDI | YES |  |  |  |  |  | D5 |  | D6 | 18 | DIRECT
PB00 | 26 |  |  | ADC12_IN8 | TIM3_CH3 |  |  |  |  | A6 | D7 | 19 | DIRECT
PB01 | 27 |  |  | ADC12_IN9 | TIM3_CH4 |  |  |  |  | A7 | NC | 20 | NC
PB02 | 28 | BOOT1 | YES |  |  |  |  |  |  | BTN | NC | 21 | NC
PB03 | 55 | JTDO | YES |  |  |  |  |  |  | D4 | VCOM | 22 | DIRECT
PB04 | 56 | JNTRST | YES |  |  |  |  |  |  | D3 | GVDD | 23 | DIRECT
PB05 | 57 |  |  |  |  |  |  |  | I2C1_SMBAl | D2 | GVEE | 24 | DIRECT
PB06 | 58 |  | YES |  | TIM4_CH1 |  |  |  | I2C1_SCL | D1 | NC | 25 | NC
PB07 | 59 |  | YES |  | TIM4_CH2 |  |  |  | I2C1_SDA | D0 | NC | 26 | NC/VEPD_G_-17V
PB10 | 29 |  | YES |  |  | USART3_TX |  |  | I2C2_SCL | USB_DISC | GMODE2 | 27 | DIRECT
PB11 | 30 |  | YES |  |  | USART3_RX |  |  | I2C2_SDA | WIFI_INT | GMODE1 | 28 | GMODE2
PB12 | 33 |  | YES |  | TIM1_BKIN | USART3_CK | SPI2_NSS |  | I2C2_SMBAl | WIFI_CS | RL | 29 | NC/DIRECT
PB13 | 34 |  | YES |  | TIM1_CH1N | USART3_CTS | SPI2_SCK |  |  | SPI_SCK | U1CE2 | 30 | 3V3
PB14 | 35 |  | YES |  | TIM1_CH2N | USART3_RTS | SPI2_MISO |  |  | SPI_MISO | U1CE1 | 31 | GND
PB15 | 36 |  | YES |  | TIM1_CH3N |  | SPI2_MOSI |  |  | SPI_MOSI | U1SPV | 32 | U2SPV
PB08 | 61 |  | YES |  | TIM4_CH3 |  |  |  |  | WIFI_EN | U1CKV | 33 | U2CKV
PB09 | 62 |  | YES |  | TIM4_CH4 |  |  |  |  | MEM_CS | VBORDER | 34 | GND/VOLTAGE
PC00 | 8 |  |  | ADC12_IN10 |  |  |  |  |  |  | U2CE2 | 35 | 3V3
PC01 | 9 |  |  | ADC12_IN11 |  |  |  |  |  |  | U2CE1 | 36 | 3V3
PC02 | 10 |  |  | ADC12_IN12 |  |  |  |  |  |  | U2SPV | 37 | U1SPV
PC03 | 11 |  |  | ADC12_IN13 |  |  |  |  |  |  | U2CKV | 38 | U1CKV
PC04 | 24 |  |  | ADC12_IN14 |  |  |  |  |  |  | NC | 39 | NC
PC05 | 25 |  |  | ADC12_IN15
PC06 | 37 |  | YES
PC07 | 38 |  | YES |  |  |  |  |  |  |  | SMPS_EN |  | Open-drain
PC08 | 39 |  | YES |  |  |  |  |  |  |  | POS_EN |  | Active high
PC09 | 40 |  | YES |  |  |  |  |  |  |  | NEG_EN |  | Active high
PC10 | 51 |  | YES
PC11 | 52 |  | YES
PC12 | 53 |  | YES
PC13 | 2 | Tamper-RTC
PC14 | 3 | OSC32_IN
PC15 | 4 | OSC32_OUT
PD00 | 5 | OSC_IN | YES
PD01 | 6 | OSC_OUT | YES
PD02 | 54 |  | YES |  | TIM3_ETR
VBAT | 1
VDD_1 | 32
VDD_2 | 48
VDD_3 | 64
VDD_4 | 19
VDDA | 13
VSS_1 | 31
VSS_2 | 47
VSS_3 | 63
VSS_4 | 18
VSSA | 12

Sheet: Pin Map
Label | STM32 No |  | DIRECTION
BOOT0 | 60 | NIL
NRST | 7
PA00 | 14 | D0 | O
PA01 | 15 | D1 | O
PA02 | 16 | D2 | O
PA03 | 17 | D3 | O
PA04 | 20 | D4 | O
PA05 | 21 | D5 | O
PA06 | 22 | D6 | O
PA07 | 23 | D7 | O
PA08 | 41 | RGB_BLUE | O
PA09 | 42 | RGB_RED | O | EINK
PA10 | 43 | RGB_GREEN | O | JTAG
PA11 | 44 | MCU_USBM | - | SPI/I2C/USB
PA12 | 45 | MCU_USBP | - | NC
PA13 | 46 | JTMS | I | DC/DC
PA14 | 49 | JTCK | I
PA15 | 50 | JTDI | I | BMIC
PB00 | 26 | BM_PGOOD | I
PB01 | 27 | BM_CHG | I
PB02 | 28 | NC
PB03 | 55 | JTDO | I
PB04 | 56 | TNTRST | I
PB05 | 57 | USB DISC | Open-drain
PB06 | 58 | MCU_SCL_1 | Open-drain
PB07 | 59 | MCU_SDA_1 | Open-drain
PB08 | 61 | MODE BUTTON | I
PB09 | 62 | EINK_VDD | O
PB10 | 29 | MCU_TX_3 | -
PB11 | 30 | MCU_RX_3 | -
PB12 | 33 | SD_CS | O
PB13 | 34 | SPI_SCK | -
PB14 | 35 | SPI_MISO | -
PB15 | 36 | SPI_MOSI | -
PC00 | 8 | CL | O
PC01 | 9 | LE | O
PC02 | 10 | OE | O
PC03 | 11 | SHR | O
PC04 | 24 | SPH | O
PC05 | 25 | GMODE2 | O
PC06 | 37 | RL | O
PC07 | 38 | SPV | O
PC08 | 39 | VBORDER | O
PC09 | 40 | CKV | O
PC10 | 51 | SMPS_CTRL | Open-drain
PC11 | 52 | POS_EN | O
PC12 | 53 | NEG_EN | O
PC13 | 2 | POS_CTRL | Open-drain
PC14 | 3 | OSC32_IN | -
PC15 | 4 | OSC32_OUT | -
PD00 | 5 | OSC_IN | -
PD01 | 6 | OSC_OUT | -
PD02 | 54 | NC
VBAT | 1 | BATT | -
VDD_1 | 32 | 3V3 | -
VDD_2 | 48 | 3V3 | -
VDD_3 | 64 | 3V3 | -
VDD_4 | 19 | 3V3 | -
VDDA | 13 | 3V3 | -
VSS_1 | 31 | GND | -
VSS_2 | 47 | GND | -
VSS_3 | 63 | GND | -
VSS_4 | 18 | GND | -
VSSA | 12 | GND | -

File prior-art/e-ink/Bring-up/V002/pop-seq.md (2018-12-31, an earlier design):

###Bring up sequence and testing steps

####Battery management module

Getting the BQ24075 to work first will be the first priority as all the other subsystems require this primary rail to be up and running.

- R05B to be populated with a 0 Ohm resistor to enable charging
- Measure Battery voltage at J05B
- 2-pin jumper needed at J04B as a physical switch to join Li-ion to system
- Measure BM_OUT at J02B
- Plug in microUSB at J07B and measure +5V at J01B
- Check that D01B lights up when microUSB power source is present
- Check that D02B lights up to indicate battery charging

####3.3V buck regulator

Pretty straight forward to bring this up. Measure at J06B for +3.3V

####DC/DC converter module

- Do not populate R12B due to control issues not able to do open-drain output
- Measure at J08B to have no voltage since Q01B load switch is disabled by default
- Need to pull down SMPS_CTRL pin but that will require the GPIO Expander. Jumper to ground for testing
- Measure J09B for -20V
- Measure J10B for +22V

####Linear regulators

- Populate the LM7815 first and measure J12B for +15V
- Populate the LM7915 and measure -15V at J11B

####OpAmp module

- Populate U6B and vary Trimpot R18B while measuring voltage at J13B

####GPIO Expander

- Hard to test without the MCU
- Probably monitor current and note for any spike?
- Run a series of GPIO output toggling tests and do a pull-up test as well

####MCU - Photon

- Check that the 3.3V and GND are properly routed and no input on the VIN or other pins
- Check for continuity for I2C lines
- Check for BM_PGOOD (A6), GMODE2 (D2), U1CKV (D5), U1SPB (D4). EINK_VDD(A2), BM_CHG (A0)

####microSD

- Check that LED flickers during read/write

####Accelerometer

- run a read test and rotate the PCB around to test changes

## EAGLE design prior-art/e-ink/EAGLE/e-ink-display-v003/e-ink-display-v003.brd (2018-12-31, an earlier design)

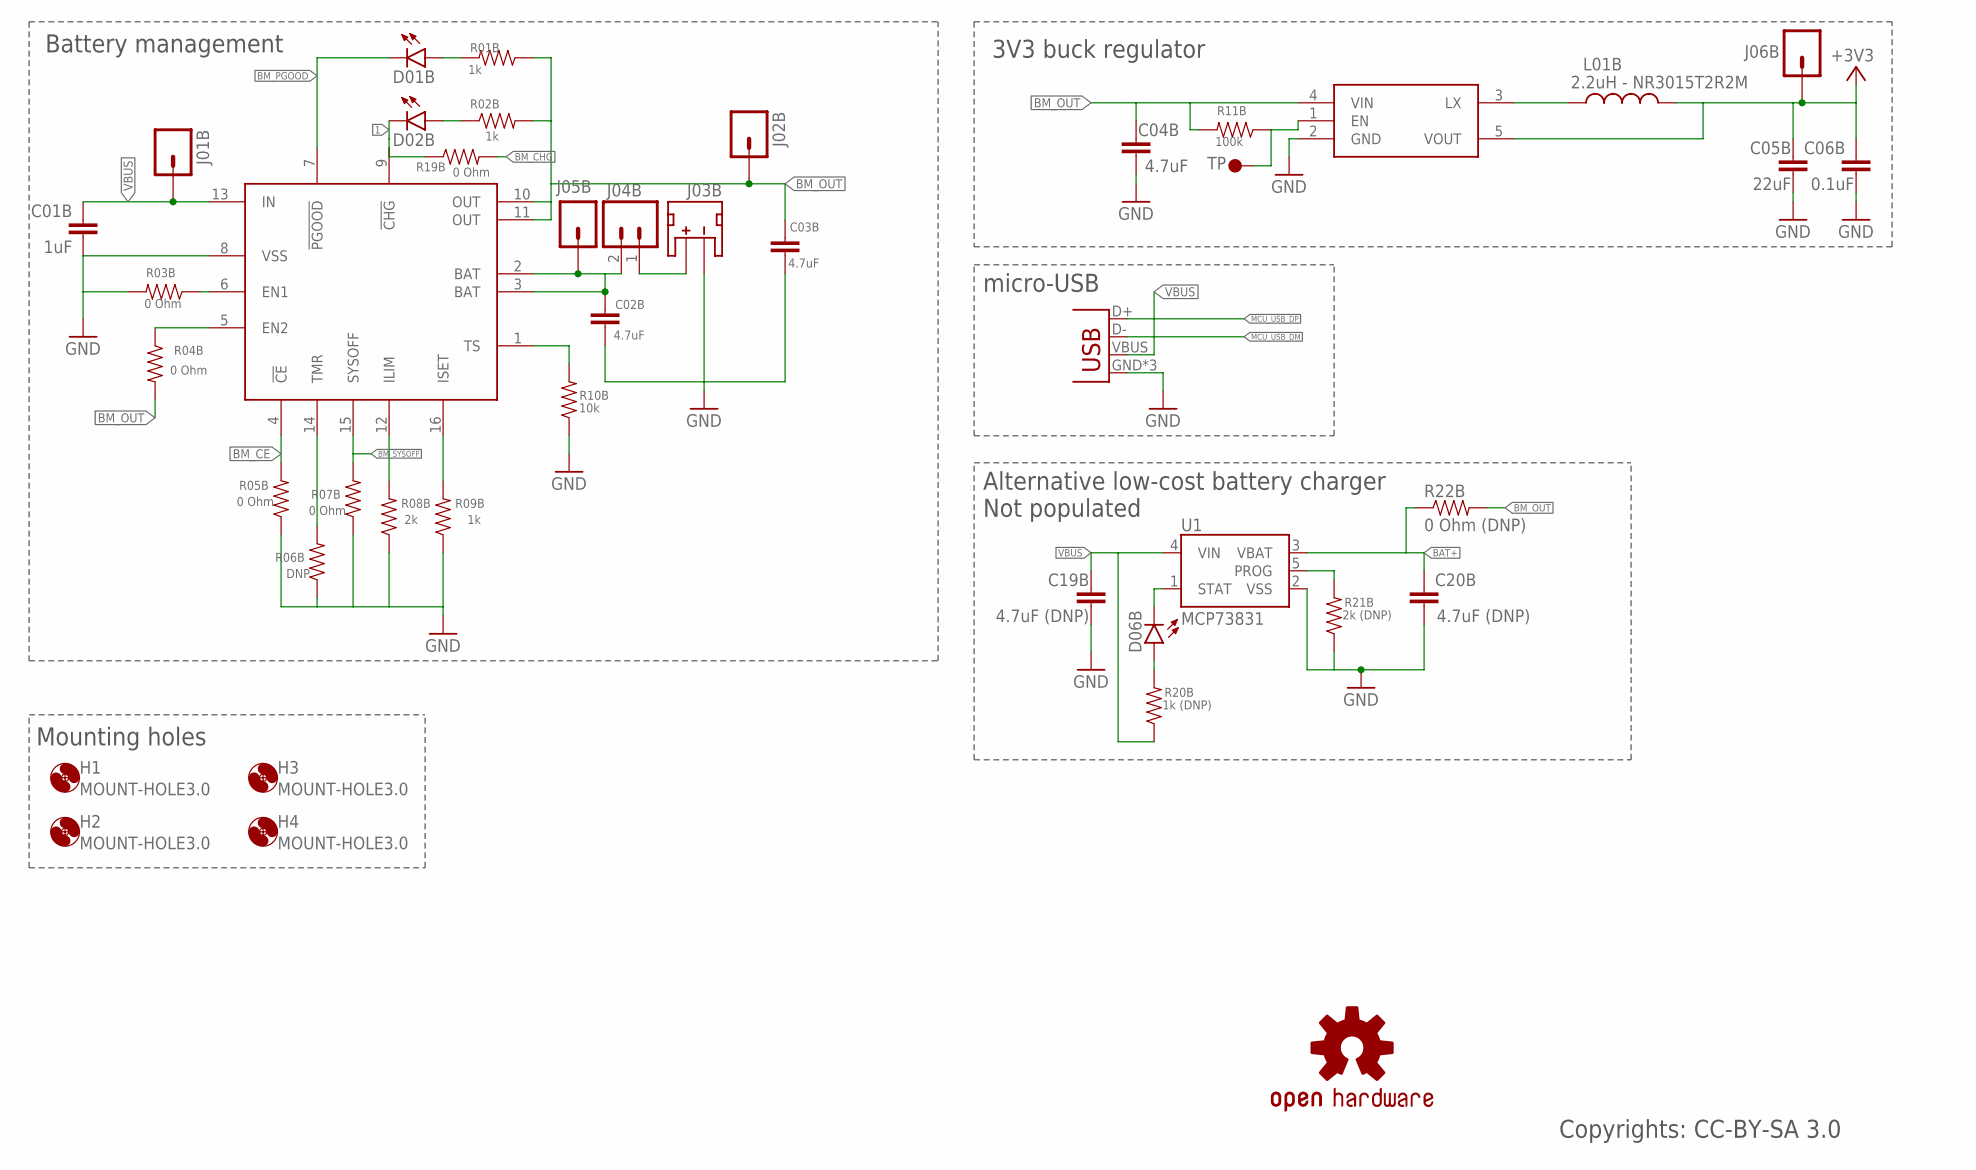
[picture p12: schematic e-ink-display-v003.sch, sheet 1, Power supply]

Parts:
C01B: 1uF; 0603-CAP
C02B, C03B, C04B: 4.7uF; 0603-CAP
C05B: 22uF; 0603-CAP
C06B: 0.1uF; 0603-CAP
C19B, C20B: 4.7uF (DNP); 0603-CAP
D01B, D02B, D06B: LED0603; LED-0603
H1, H2, H3, H4: MOUNT-HOLE3.0; 3,0
J01B, J02B, J05B, J06B: M01PTH; 1X01
J03B: JST_2MM_MALE; JST-2-SMD
J04B: M02PTH; 1X02
J07B: USBUSB-MICROB-SLOT-HOLE; USB-MICROB-SLOT-HOLE
L01B: 2.2uH - NR3015T2R2M; INDUCTOR-NR3015
LOGO1: OSHW-LOGOPAD; OSHW-LOGO-M-PAD
R01B, R02B, R09B: 1k; 0603-RES
R03B, R04B, R05B, R07B, R19B: 0 Ohm; 0603-RES
R06B: DNP; 0603-RES
R08B: 2k; 0603-RES
R10B: 10k; 0603-RES
R11B: 100k; 0603-RES
R20B: 1k (DNP); 0603-RES
R21B: 2k (DNP); 0603-RES
R22B: 0 Ohm (DNP); 1206
TP01B: TP1; TP35_BOT
U1: MCP73831; SOT23-5
U01B: BQ24075; QFN-16
U02B: R8008-33; SOT23-5

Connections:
1: D02B.C, R19B.1, U01B.9 (!CHG)
+3V3: C05B.2, C06B.2, J06B.1, L01B.2, U02B.5 (VOUT); also elsewhere on the board
BAT+: C20B.2, J03B.2 (+), J04B.1, R22B.1, U1.3 (VBAT)
BM_BAT: C02B.2, J04B.2, J05B.1, U01B.2 (BAT), U01B.3 (BAT)
BM_CE: R05B.2, U01B.4 (!CE)
BM_CHG: R19B.2; also elsewhere on the board
BM_OUT: C03B.2, C04B.2, J02B.1, R01B.1, R02B.2, R04B.2, R11B.2, R22B.2, U01B.10 (OUT), U01B.11 (OUT), U02B.4 (VIN); also elsewhere on the board
BM_PGOOD: D01B.C, U01B.7 (!PGOOD); also elsewhere on the board
BM_SYSOFF: R07B.2, U01B.15 (SYSOFF)
GND: C01B.1, C02B.1, C03B.1, C04B.1, C05B.1, C06B.1, C19B.1, C20B.1, J03B.1 (-), J07B.GND, J07B.MT1 (GND), J07B.MT2 (GND), R03B.2, R05B.1, R06B.1, R07B.1, R08B.1, R09B.1, R10B.1, R21B.1, U1.2 (VSS), U01B.8 (VSS), U02B.2 (GND); also elsewhere on the board
MCU_USB_DM: J07B.D-
MCU_USB_DP: J07B.D+
unnamed: R08B.2, U01B.12 (ILIM)
unnamed: R09B.2, U01B.16 (ISET)
unnamed: R04B.1, U01B.5 (EN2)
unnamed: R03B.1, U01B.6 (EN1)
unnamed: R06B.2, U01B.14 (TMR)
unnamed: R10B.2, U01B.1 (TS)
unnamed: D02B.A, R02B.1
unnamed: D01B.A, R01B.2
unnamed: R21B.2, U1.5 (PROG)
unnamed: R11B.1, TP01B.P$1, U02B.1 (EN)
unnamed: L01B.1, U02B.3 (LX)
unnamed: D06B.C, U1.1 (STAT)
unnamed: D06B.A, R20B.2
VBUS: C01B.2, C19B.2, J01B.1, J07B.VBUS, R20B.1, U1.4 (VIN), U01B.13 (IN)

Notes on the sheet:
Battery management
3V3 buck regulator
micro-USB
Mounting holes
Alternative low-cost battery charger Not populated
Copyrights: CC-BY-SA 3.0

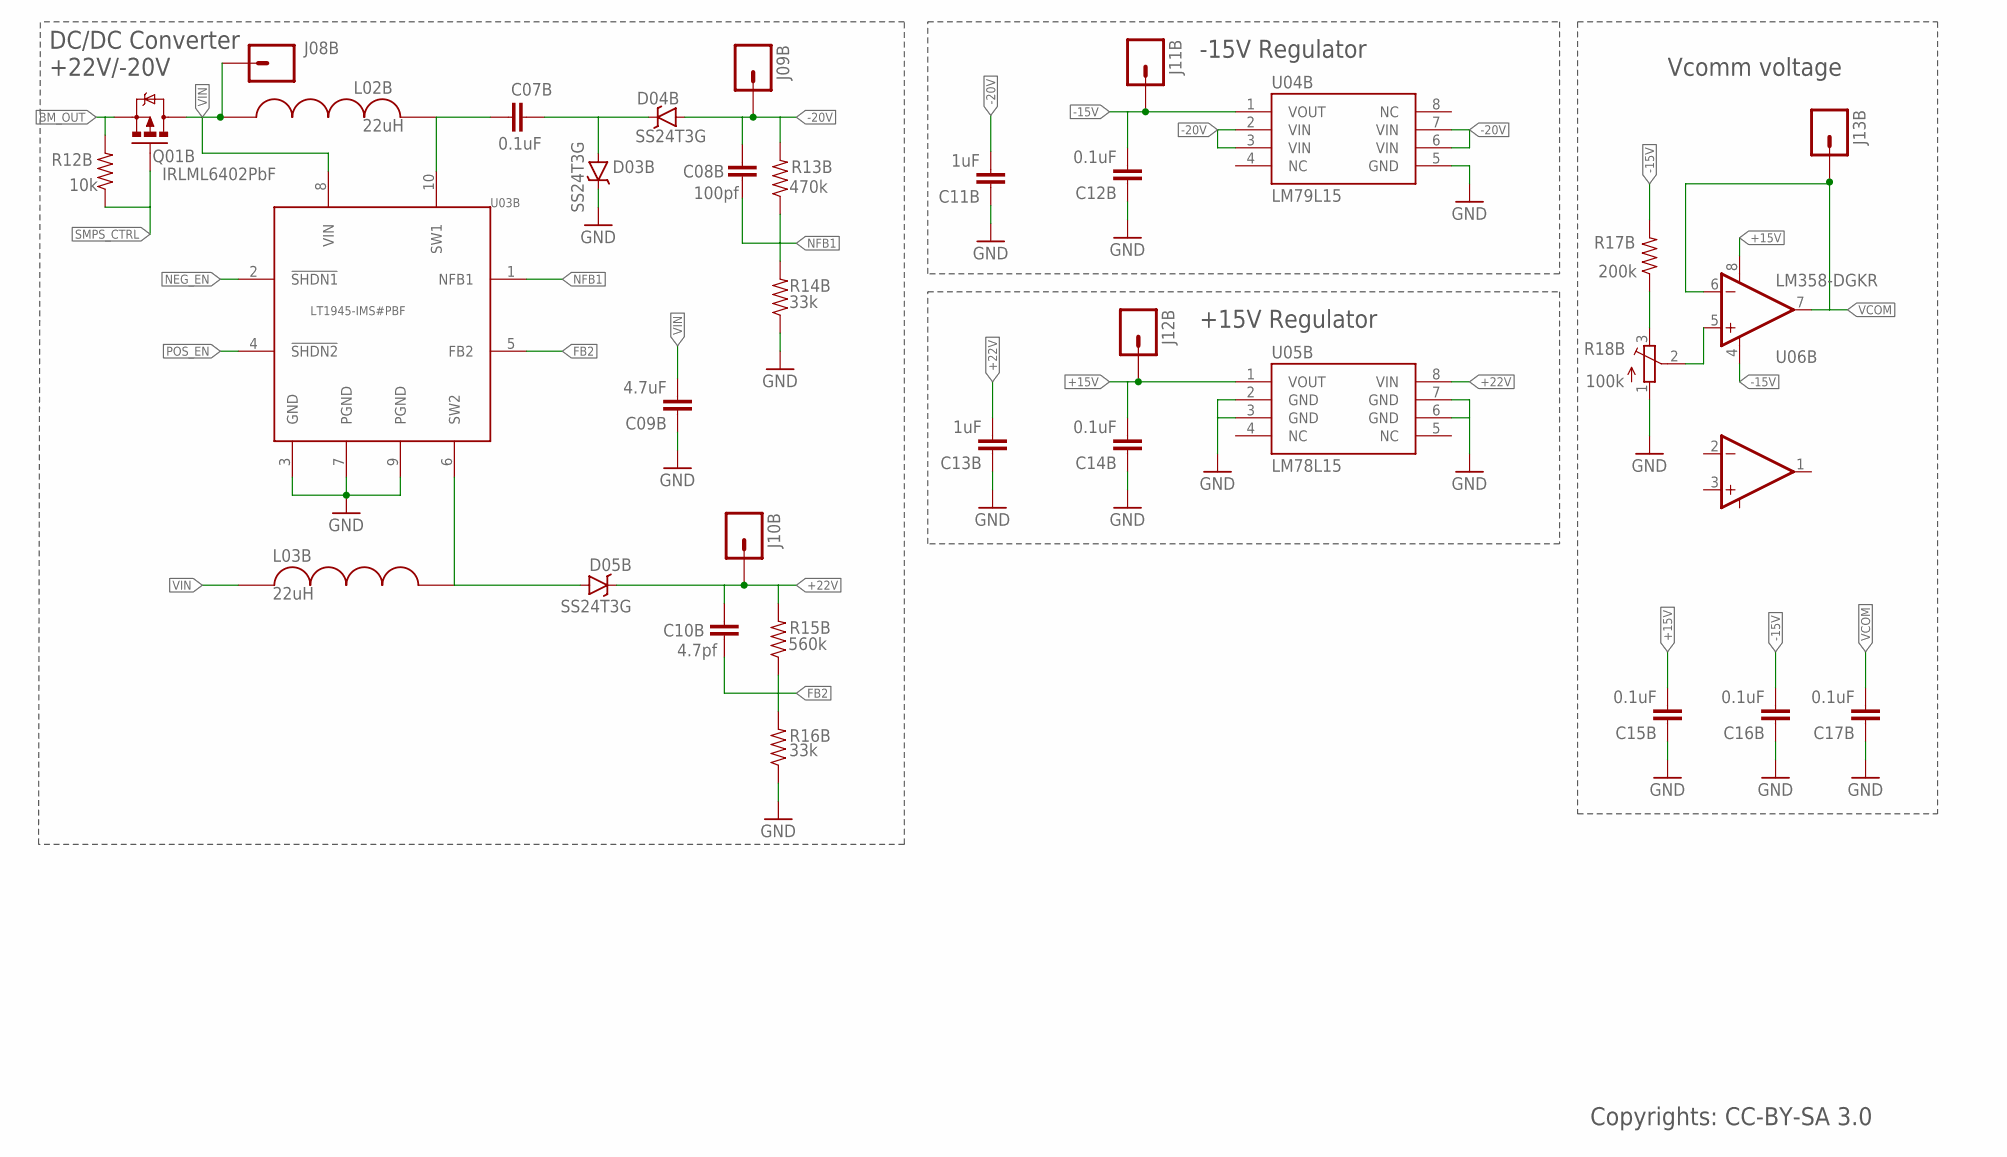
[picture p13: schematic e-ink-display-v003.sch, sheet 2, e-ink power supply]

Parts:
C07B, C12B, C14B, C15B, C16B, C17B: 0.1uF; 0603-CAP
C08B: 100pf; 0603-CAP
C09B: 4.7uF; 0603-CAP
C10B: 4.7pf; 0603-CAP
C11B, C13B: 1uF; 0603-CAP
D03B, D04B, D05B: SS24T3G; SMA-DIODE
J08B, J09B, J10B, J11B, J12B, J13B: M01PTH; 1X01
L02B, L03B: 22uH; 4040(1515)
Q01B: IRLML6402PbF; SOT23-3
R12B: 10k; 0603-RES
R13B: 470k; 0603-RES
R14B, R16B: 33k; 0603-RES
R15B: 560k; 0603-RES
R17B: 200k; 0603-RES
R18B: 100k; TC33X
U03B: LT1945-IMS#PBF; MSOP-10
U04B: LM79L15; SO08
U05B: LM78L15; SO08
U06B: LM358-DGKR; MSOP-8

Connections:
+15V: C14B.2, C15B.2, J12B.1, U05B.1 (VOUT), U06B.8 (V+); also elsewhere on the board
+22V: C10B.2, C13B.2, D05B.C, J10B.1, R15B.2, U05B.8 (VIN); also elsewhere on the board
-15V: C12B.2, C16B.2, J11B.1, R17B.2, U04B.1 (VOUT), U06B.4 (V-); also elsewhere on the board
-20V: C08B.2, C11B.2, D04B.A, J09B.1, R13B.2, U04B.2 (VIN), U04B.3 (VIN), U04B.6 (VIN), U04B.7 (VIN); also elsewhere on the board
BM_OUT: Q01B.2 (S), R12B.2; also elsewhere on the board
FB2: C10B.1, R15B.1, R16B.2, U03B.5 (FB2)
GND: C09B.1, C11B.1, C12B.1, C13B.1, C14B.1, C15B.1, C16B.1, C17B.1, D03B.C, R14B.1, R16B.1, R18B.1 (A), U03B.3 (GND), U03B.7 (PGND), U03B.9 (PGND), U04B.5 (GND), U05B.2 (GND), U05B.3 (GND), U05B.6 (GND), U05B.7 (GND); also elsewhere on the board
unnamed: C07B.1, L02B.P$2, U03B.10 (SW1)
unnamed: C07B.2, D03B.A, D04B.C
unnamed: R18B.2 (S), U06B.5 (+IN2)
unnamed: R17B.1, R18B.3 (E)
unnamed: D05B.A, L03B.P$2, U03B.6 (SW2)
NEG_EN: U03B.2 (!SHDN1); also elsewhere on the board
NFB1: C08B.1, R13B.1, R14B.2, U03B.1 (NFB1)
POS_EN: U03B.4 (!SHDN2); also elsewhere on the board
SMPS_CTRL: Q01B.1 (G), R12B.1; also elsewhere on the board
VCOM: C17B.2, J13B.1, U06B.6 (-IN2), U06B.7 (OUT2); also elsewhere on the board
VIN: C09B.2, J08B.1, L02B.P$1, L03B.P$1, Q01B.3 (D), U03B.8 (VIN)

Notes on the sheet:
-15V Regulator
+15V Regulator
Vcomm voltage
DC/DC Converter +22V/-20V
Copyrights: CC-BY-SA 3.0

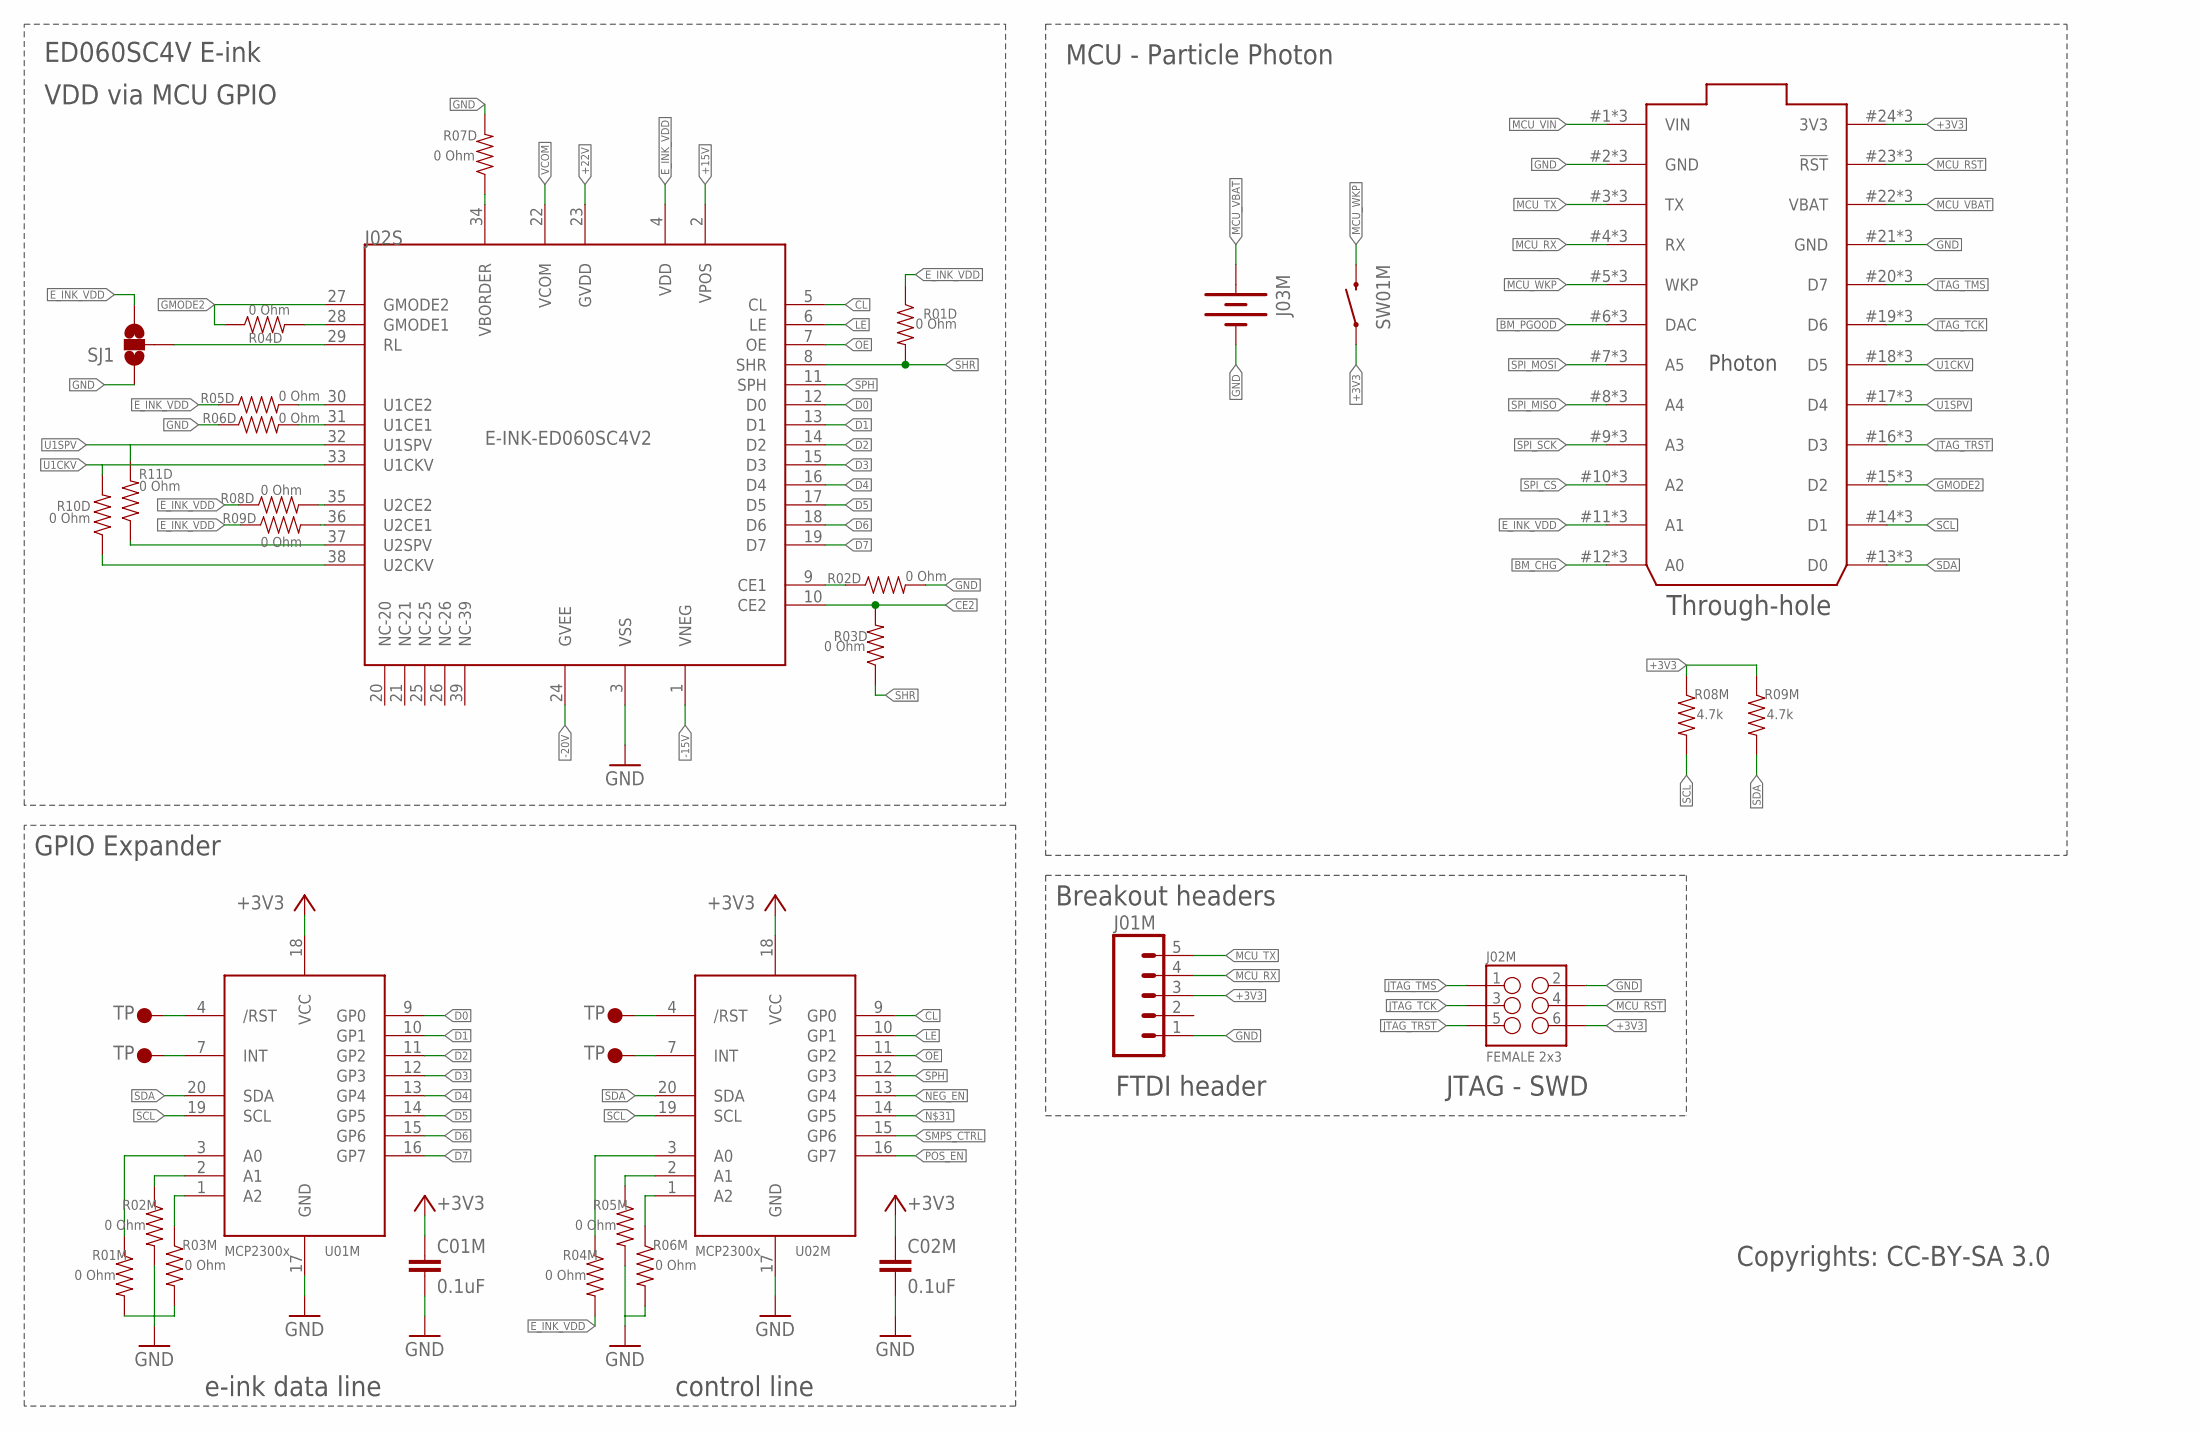
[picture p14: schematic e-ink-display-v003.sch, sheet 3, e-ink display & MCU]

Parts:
C01M, C02M: 0.1uF; 0603-CAP
J01M: M05PTH; 1X05
J02M: FEMALE 2x3; 2X3
J02S: E-INK-ED060SC4V2; FPC-0.3-39
J03M: BATTERY20PTH; BATTCOM_20MM_PTH
R01D, R01M, R02D, R02M, R03D, R03M, R04D, R04M, R05D, R05M, R06D, R06M, R07D, R08D, R09D, R10D, R11D: 0 Ohm; 0603-RES
R08M, R09M: 4.7k; 0603-RES
SJ1: SOLDERJUMPER_2WAYT; SJ_2
SW01M: SWITCH-MOMENTARY-2PTH; TACTILE-PTH
U01M, U02M: MCP2300X/QFN; QFN-20(4X4)
U03M: PHOTON_WITH_STACKABLE_HEADERS; PHOTON_STACKABLE
U$1, U$2, U$3, U$4: TP1; TP35_BOT

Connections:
+3V3: C01M.1, C02M.1, J01M.3, J02M.6, R08M.1, R09M.1, SW01M.1, U01M.18 (VCC), U02M.18 (VCC), U03M.24 (3V3), U03M.#24 (3V3), U03M.@24 (3V3); also elsewhere on the board
+15V: J02S.2 (VPOS); also elsewhere on the board
+22V: J02S.23 (GVDD); also elsewhere on the board
-15V: J02S.1 (VNEG); also elsewhere on the board
-20V: J02S.24 (GVEE); also elsewhere on the board
BM_CHG: U03M.12 (A0), U03M.#12 (A0), U03M.@12 (A0); also elsewhere on the board
BM_PGOOD: U03M.6 (DAC), U03M.#6 (DAC), U03M.@6 (DAC); also elsewhere on the board
CE2: J02S.10 (CE2), R03D.2
CL: J02S.5 (CL), U02M.9 (GP0)
D0: J02S.12 (D0), U01M.9 (GP0)
D1: J02S.13 (D1), U01M.10 (GP1)
D2: J02S.14 (D2), U01M.11 (GP2)
D3: J02S.15 (D3), U01M.12 (GP3)
D4: J02S.16 (D4), U01M.13 (GP4)
D5: J02S.17 (D5), U01M.14 (GP5)
D6: J02S.18 (D6), U01M.15 (GP6)
D7: J02S.19 (D7), U01M.16 (GP7)
E_INK_VDD: J02S.4 (VDD), R01D.1, R04M.2, R05D.1, R08D.1, R09D.1, SJ1.3, U03M.11 (A1), U03M.#11 (A1), U03M.@11 (A1)
GMODE2: J02S.27 (GMODE2), R04D.1, U03M.15 (D2), U03M.#15 (D2), U03M.@15 (D2)
GND: C01M.2, C02M.2, J01M.1, J02M.2, J02S.3 (VSS), J03M.2 (-), R01M.2, R02D.2, R02M.2, R03M.2, R05M.2, R06D.1, R06M.2, R07D.2, SJ1.1, U01M.17 (GND), U02M.17 (GND), U03M.2 (GND), U03M.21 (GND), U03M.#2 (GND), U03M.#21 (GND), U03M.@2 (GND), U03M.@21 (GND); also elsewhere on the board
JTAG_TCK: J02M.3, U03M.19 (D6), U03M.#19 (D6), U03M.@19 (D6)
JTAG_TMS: J02M.1, U03M.20 (D7), U03M.#20 (D7), U03M.@20 (D7)
JTAG_TRST: J02M.5, U03M.16 (D3), U03M.#16 (D3), U03M.@16 (D3); also elsewhere on the board
LE: J02S.6 (LE), U02M.10 (GP1)
MCU_RST: J02M.4, U03M.23 (!RST), U03M.#23 (!RST), U03M.@23 (!RST)
MCU_RX: J01M.4, U03M.4 (RX), U03M.#4 (RX), U03M.@4 (RX)
MCU_TX: J01M.5, U03M.3 (TX), U03M.#3 (TX), U03M.@3 (TX)
MCU_VBAT: J03M.1 (+), U03M.22 (VBAT), U03M.#22 (VBAT), U03M.@22 (VBAT)
MCU_VIN: U03M.1 (VIN), U03M.#1 (VIN), U03M.@1 (VIN)
MCU_WKP: SW01M.3 (2), U03M.5 (WKP), U03M.#5 (WKP), U03M.@5 (WKP)
unnamed: J02S.28 (GMODE1), R04D.2
unnamed: J02S.31 (U1CE1), R06D.2
unnamed: U01M.4 (/RST), U$1.P$1
unnamed: U01M.7 (INT), U$2.P$1
unnamed: U02M.4 (/RST), U$3.P$1
unnamed: U02M.7 (INT), U$4.P$1
unnamed: R03M.1, U01M.1 (A2)
unnamed: R01M.1, U01M.3 (A0)
unnamed: J02S.35 (U2CE2), R08D.2
unnamed: J02S.36 (U2CE1), R09D.2
unnamed: J02S.9 (CE1), R02D.1
unnamed: J02S.34 (VBORDER), R07D.1
unnamed: R06M.1, U02M.1 (A2)
unnamed: R05M.1, U02M.2 (A1)
unnamed: R04M.1, U02M.3 (A0)
unnamed: R02M.1, U01M.2 (A1)
NEG_EN: U02M.13 (GP4); also elsewhere on the board
OE: J02S.7 (OE), U02M.11 (GP2)
POS_EN: U02M.16 (GP7); also elsewhere on the board
RL: J02S.29 (RL), SJ1.2
SCL: R08M.2, U01M.19 (SCL), U02M.19 (SCL), U03M.14 (D1), U03M.#14 (D1), U03M.@14 (D1); also elsewhere on the board
SDA: R09M.2, U01M.20 (SDA), U02M.20 (SDA), U03M.13 (D0), U03M.#13 (D0), U03M.@13 (D0); also elsewhere on the board
SHR: J02S.8 (SHR), R01D.2, R03D.1
SMPS_CTRL: U02M.15 (GP6); also elsewhere on the board
SPH: J02S.11 (SPH), U02M.12 (GP3)
SPI_CS: U03M.10 (A2), U03M.#10 (A2), U03M.@10 (A2); also elsewhere on the board
SPI_MISO: U03M.8 (A4), U03M.#8 (A4), U03M.@8 (A4); also elsewhere on the board
SPI_MOSI: U03M.7 (A5), U03M.#7 (A5), U03M.@7 (A5); also elsewhere on the board
SPI_SCK: U03M.9 (A3), U03M.#9 (A3), U03M.@9 (A3); also elsewhere on the board
U1CE2: J02S.30 (U1CE2), R05D.2
U1CKV: J02S.33 (U1CKV), R10D.2, U03M.18 (D5), U03M.#18 (D5), U03M.@18 (D5)
U1SPV: J02S.32 (U1SPV), R11D.2, U03M.17 (D4), U03M.#17 (D4), U03M.@17 (D4)
U2CKV: J02S.38 (U2CKV), R10D.1
U2SPV: J02S.37 (U2SPV), R11D.1
VCOM: J02S.22 (VCOM); also elsewhere on the board

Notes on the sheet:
ED060SC4V E-ink VDD via MCU GPIO
Through-hole
MCU - Particle Photon
Breakout headers
GPIO Expander
e-ink data line
control line
FTDI header
JTAG - SWD
Copyrights: CC-BY-SA 3.0

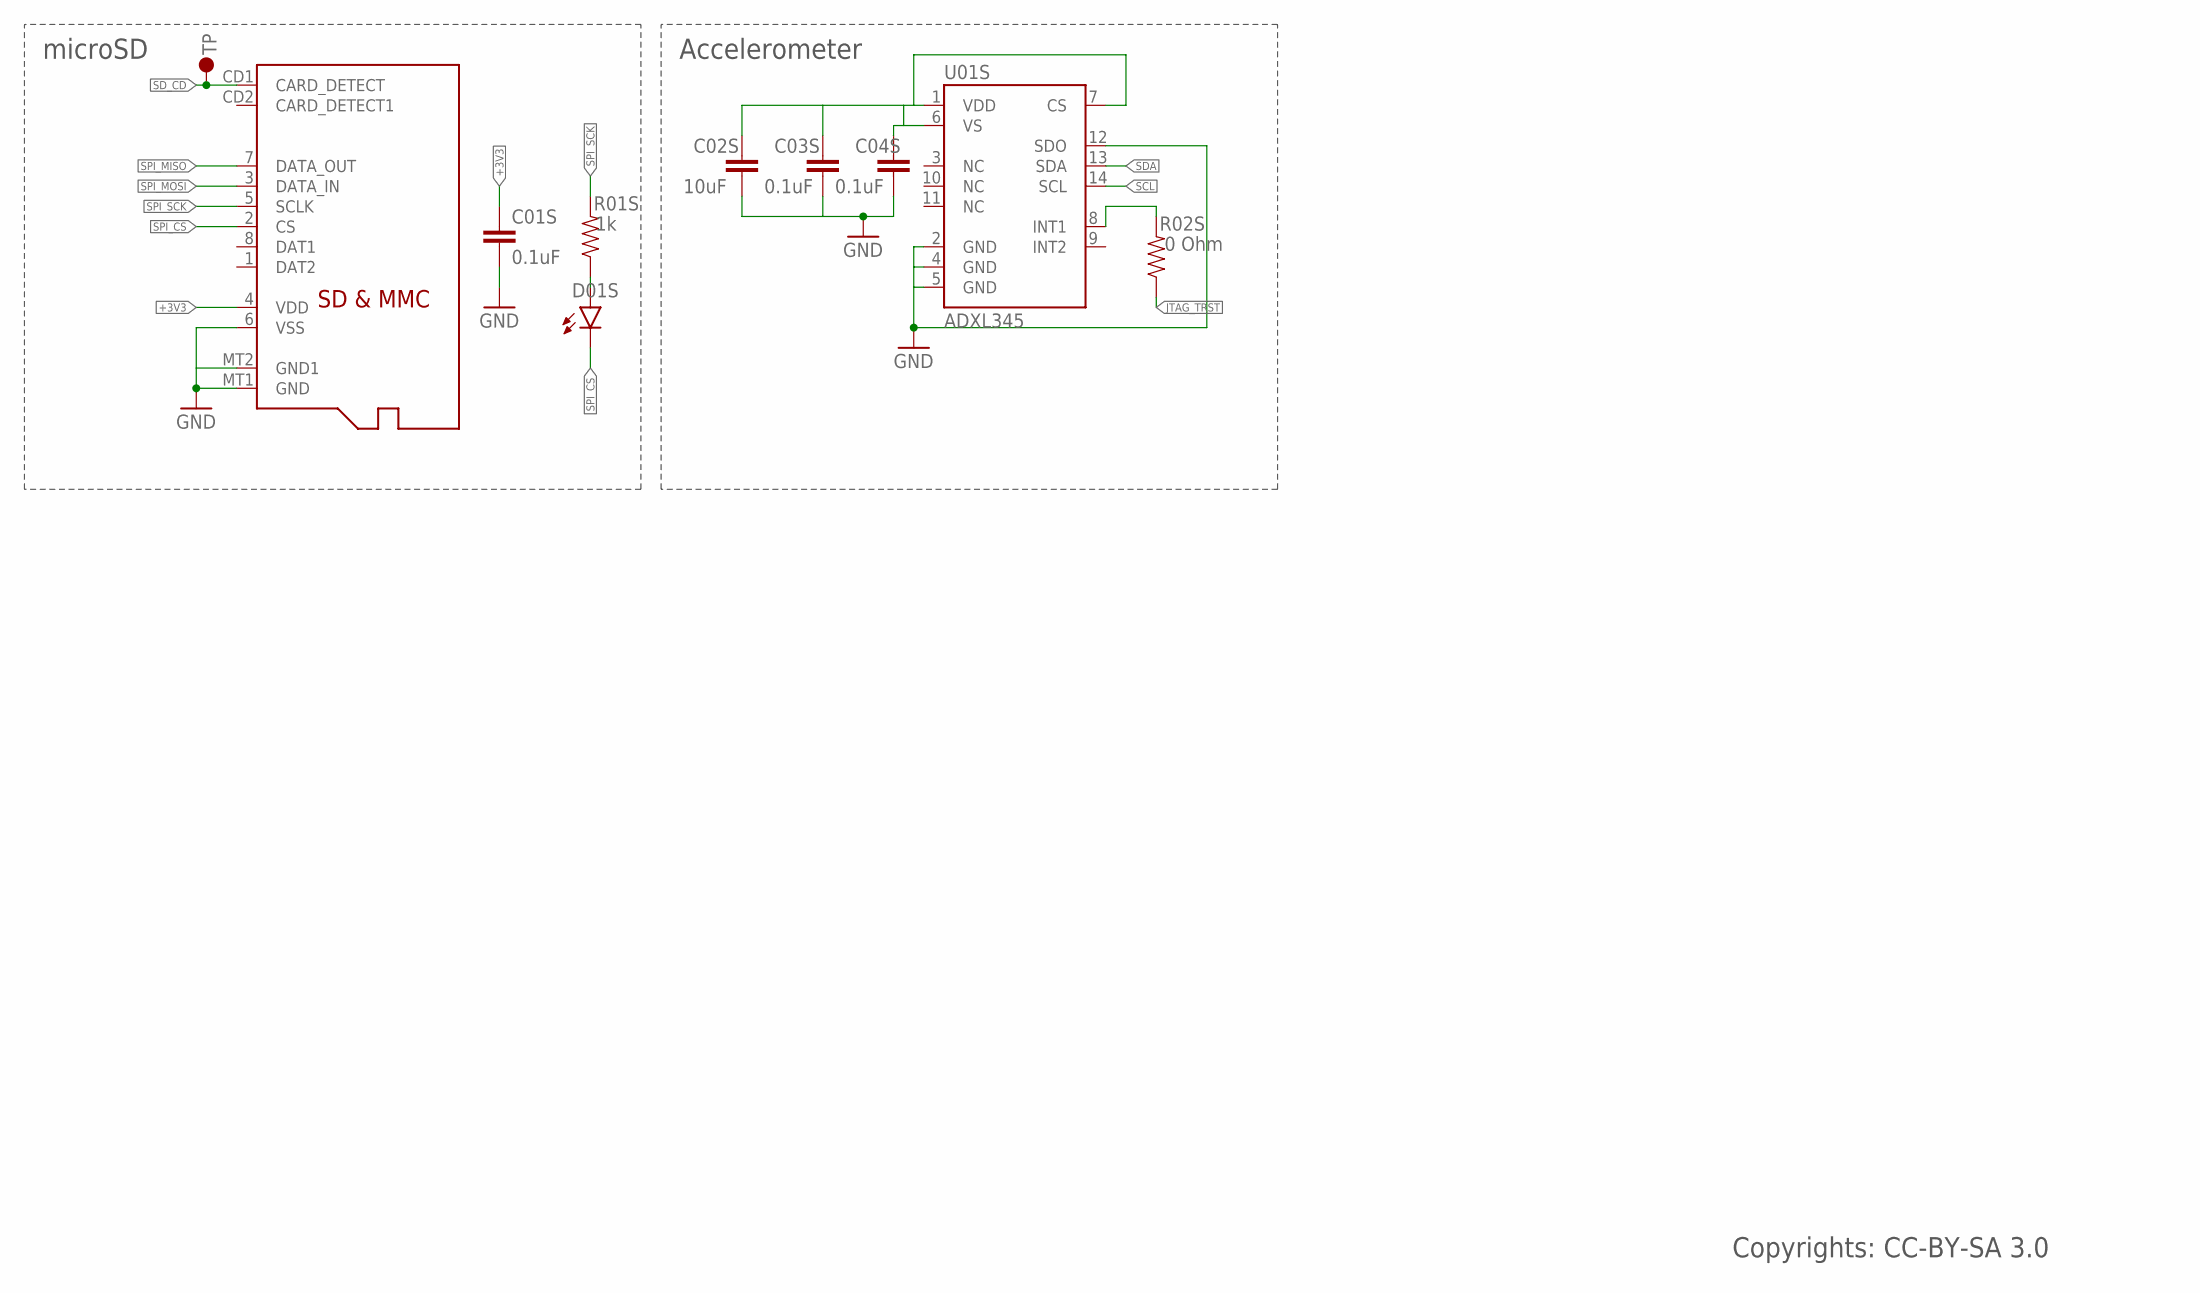
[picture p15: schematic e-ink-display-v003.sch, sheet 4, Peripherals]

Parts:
C01S, C03S, C04S: 0.1uF; 0603-CAP
C02S: 10uF; 0603-CAP
D01S: LED0603; LED-0603
J01S: MICROSD
R01S: 1k; 0603-RES
R02S: 0 Ohm; 0603-RES
U01S: ADXL345; LGA14
U$5: TP3; TP60_BOT

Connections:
+3V3: C01S.1, J01S.4 (VDD); also elsewhere on the board
GND: C01S.2, C02S.2, C03S.2, C04S.2, J01S.6 (VSS), J01S.MT1 (GND), J01S.MT2 (GND1), U01S.2 (GND), U01S.4 (GND), U01S.5 (GND), U01S.12 (SDO); also elsewhere on the board
JTAG_TRST: R02S.1; also elsewhere on the board
unnamed: R02S.2, U01S.8 (INT1)
unnamed: C02S.1, C03S.1, C04S.1, U01S.1 (VDD), U01S.6 (VS), U01S.7 (CS)
R01S: D01S.A, R01S.1
SCL: U01S.14 (SCL); also elsewhere on the board
SDA: U01S.13 (SDA); also elsewhere on the board
SD_CD: J01S.CD1 (CARD_DETECT), U$5.P$1
SPI_CS: D01S.C, J01S.2 (CS); also elsewhere on the board
SPI_MISO: J01S.7 (DATA_OUT); also elsewhere on the board
SPI_MOSI: J01S.3 (DATA_IN); also elsewhere on the board
SPI_SCK: J01S.5 (SCLK), R01S.2; also elsewhere on the board

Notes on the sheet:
microSD
Accelerometer
Copyrights: CC-BY-SA 3.0

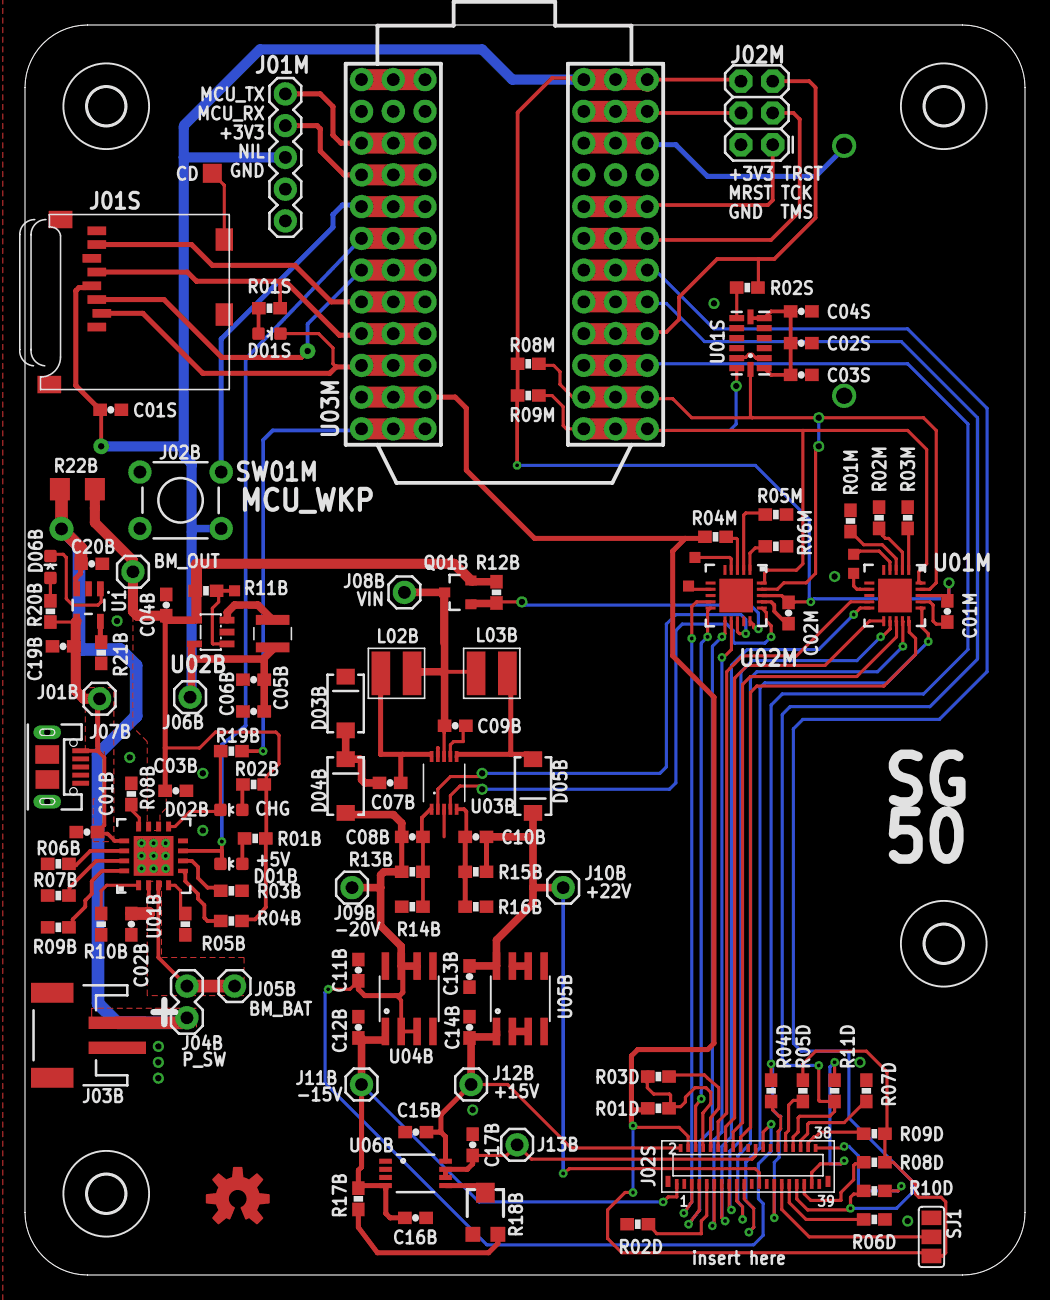
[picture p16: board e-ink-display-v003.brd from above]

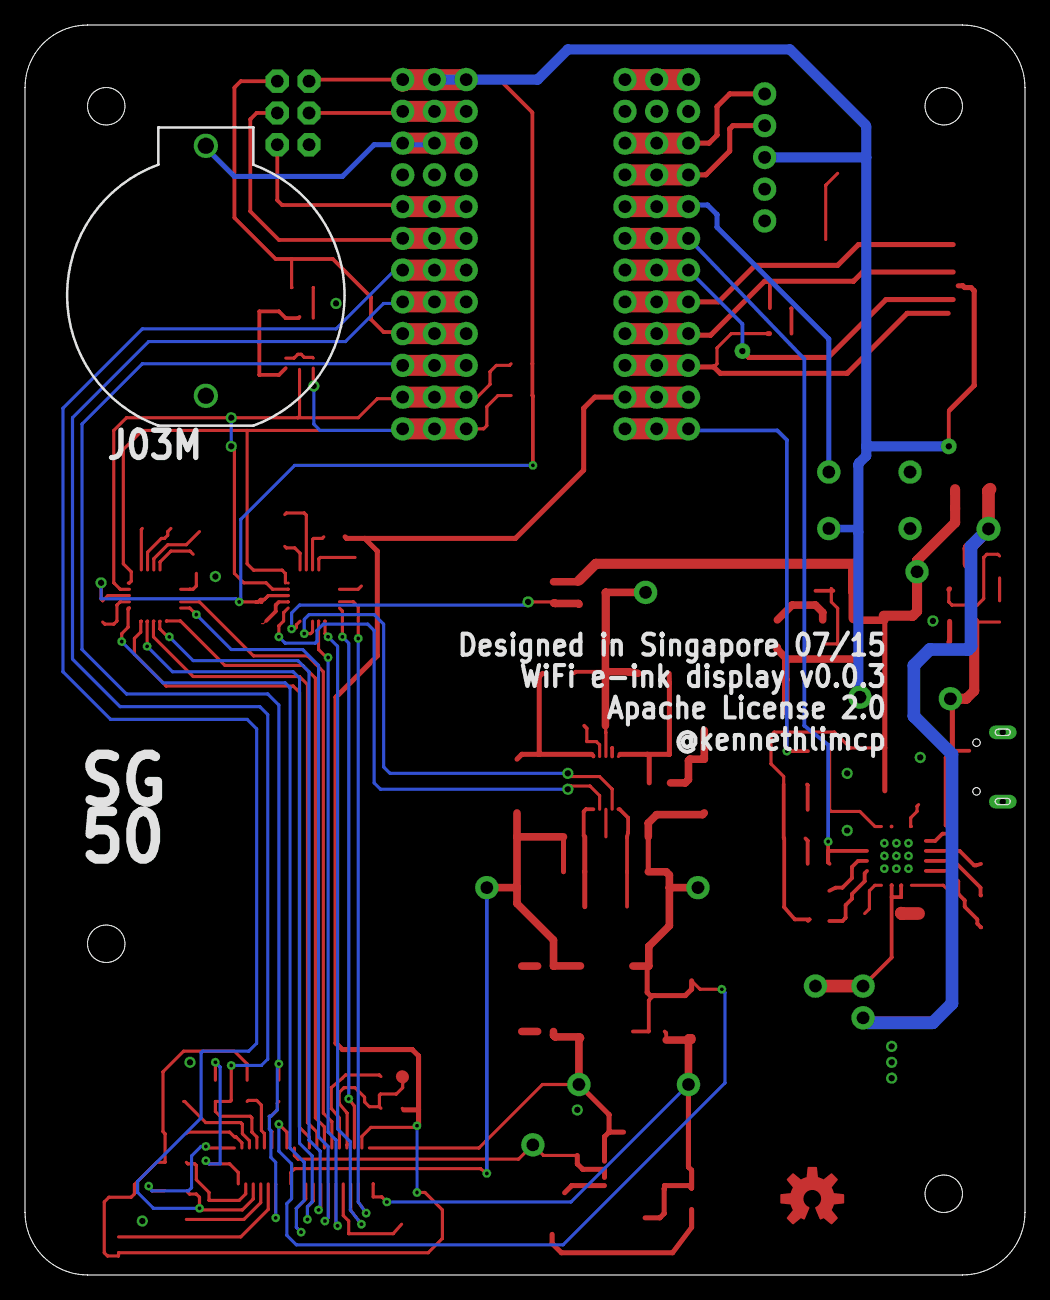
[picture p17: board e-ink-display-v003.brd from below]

Board: 4 copper layers, 80.0 x 100.0 mm, 121 parts (7 on the bottom side), 97 nets.

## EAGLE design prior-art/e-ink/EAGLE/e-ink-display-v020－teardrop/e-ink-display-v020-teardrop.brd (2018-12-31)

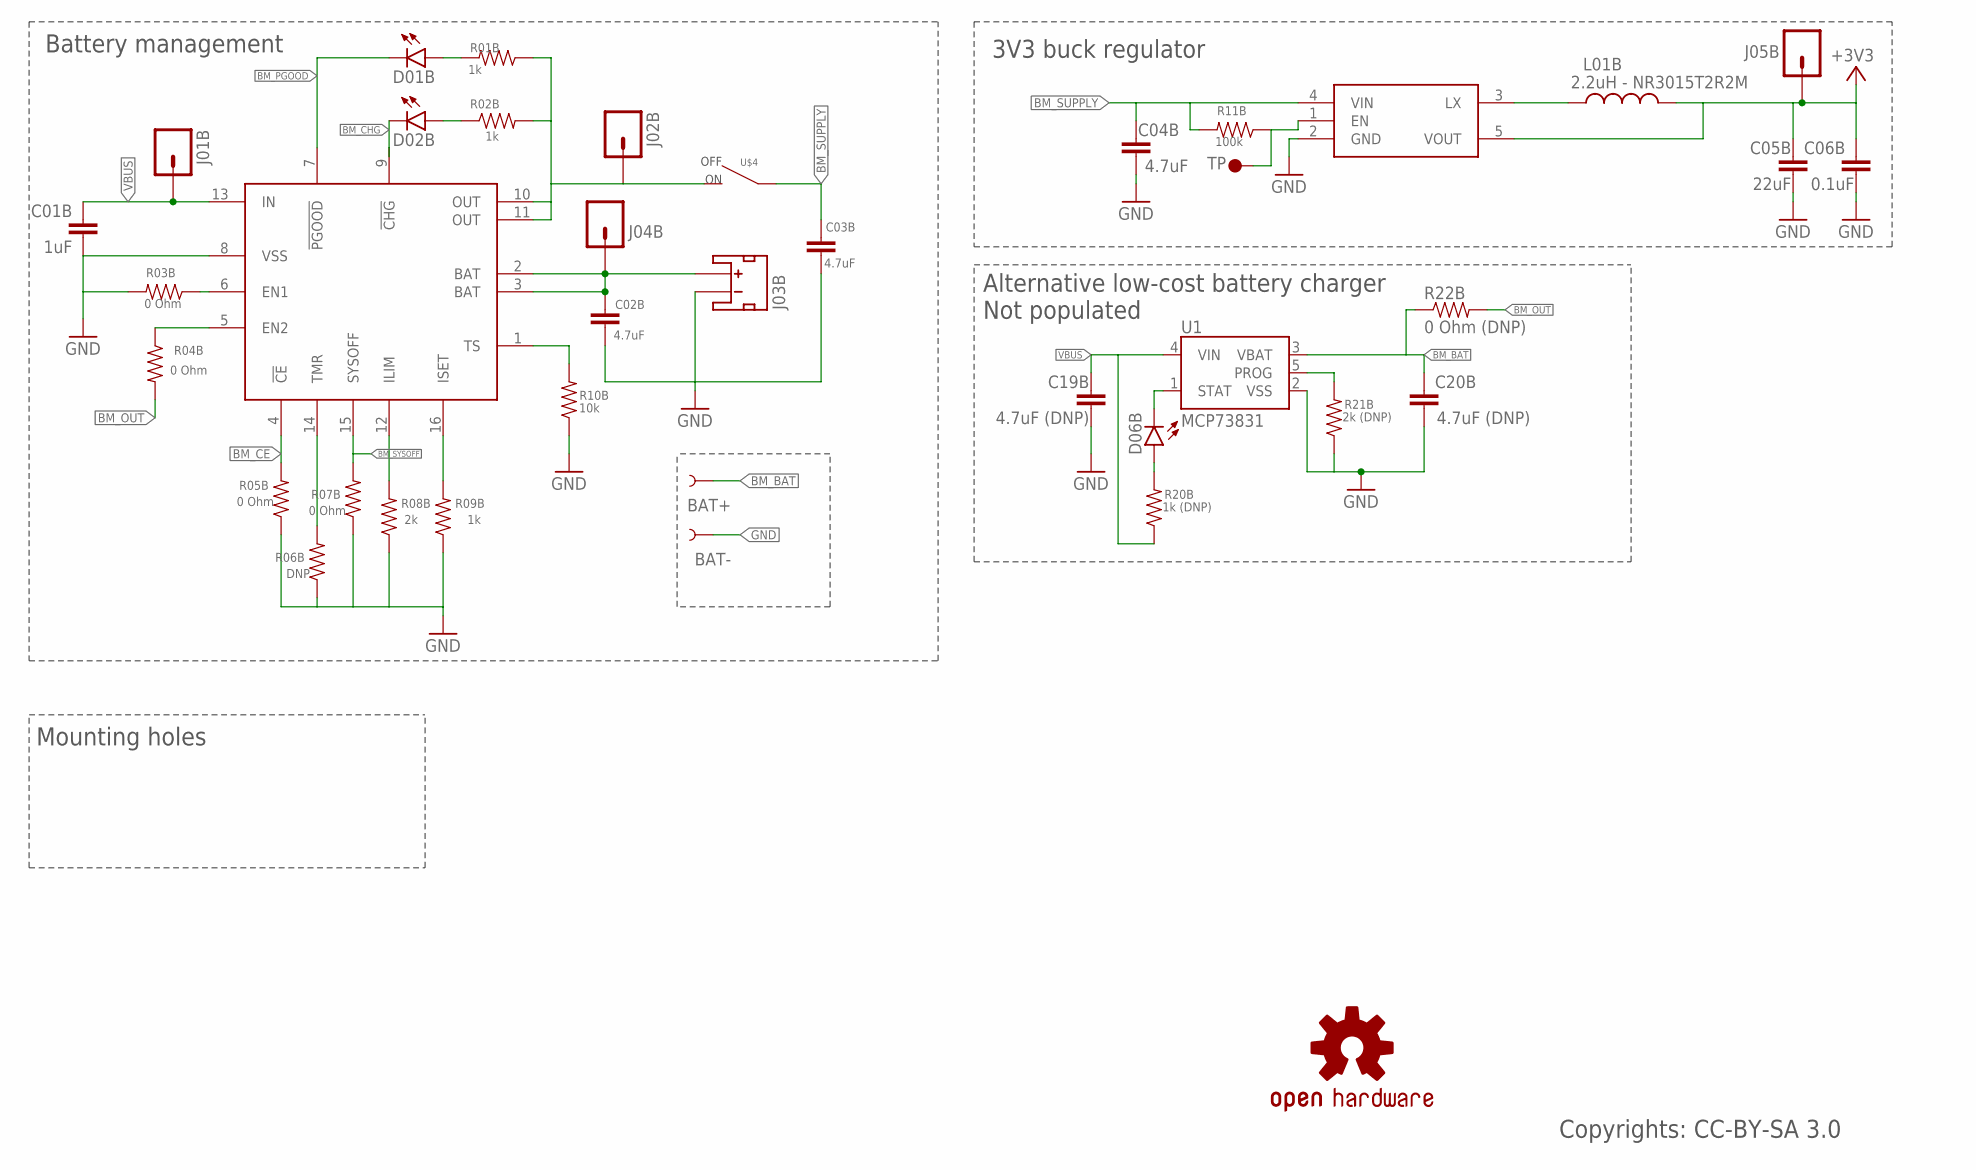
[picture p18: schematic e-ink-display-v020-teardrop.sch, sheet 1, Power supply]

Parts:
BAT+: TEST-POINTBOTH_SQ; TP_15_BOTH-SQ
BAT-: TEST-POINTBOTHBOTH; TP_15_BOTH
C01B: 1uF; 0603-CAP
C02B, C03B, C04B: 4.7uF; 0603-CAP
C05B: 22uF; 0603-CAP
C06B: 0.1uF; 0603-CAP
C19B, C20B: 4.7uF (DNP); 0603-CAP
D01B, D02B, D06B: LED0603; LED-0603
J01B, J02B, J04B, J05B: M01PTH; 1X01
J03B: JST_2MM_MALE; JST-2-SMD
L01B: 2.2uH - NR3015T2R2M; INDUCTOR-NR3015
LOGO1: OSHW-LOGOPAD; OSHW-LOGO-M-PAD
R01B, R02B, R09B: 1k; 0603-RES
R03B, R04B, R05B, R07B: 0 Ohm; 0603-RES
R06B: DNP; 0603-RES
R08B: 2k; 0603-RES
R10B: 10k; 0603-RES
R11B: 100k; 0603-RES
R20B: 1k (DNP); 0603-RES
R21B: 2k (DNP); 0603-RES
R22B: 0 Ohm (DNP); 1206
TP01B: TP1; TP35_BOT
U1: MCP73831; SOT23-5
U01B: BQ24075; PVQFN-16
U02B: R8008-33; SOT23-5
U$4: SWITCHSLIDE; CHANGE_OVER_SLIDE

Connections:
+3V3: C05B.2, C06B.2, J05B.1, L01B.2, U02B.5 (VOUT); also elsewhere on the board
BM_BAT: BAT+.P$1, C02B.2, C20B.2, J03B.2 (+), J04B.1, R22B.1, U1.3 (VBAT), U01B.2 (BAT), U01B.3 (BAT)
BM_CE: R05B.2, U01B.4 (!CE)
BM_CHG: D02B.C, U01B.9 (!CHG); also elsewhere on the board
BM_OUT: J02B.1, R01B.1, R02B.2, R04B.2, R22B.2, U01B.10 (OUT), U01B.11 (OUT), U$4.2
BM_PGOOD: D01B.C, U01B.7 (!PGOOD); also elsewhere on the board
BM_SUPPLY: C03B.2, C04B.2, R11B.2, U02B.4 (VIN), U$4.1; also elsewhere on the board
BM_SYSOFF: R07B.2, U01B.15 (SYSOFF)
GND: BAT-.P$1, C01B.1, C02B.1, C03B.1, C04B.1, C05B.1, C06B.1, C19B.1, C20B.1, J03B.1 (-), R03B.2, R05B.1, R06B.1, R07B.1, R08B.1, R09B.1, R10B.1, R21B.1, U1.2 (VSS), U01B.8 (VSS), U02B.2 (GND); also elsewhere on the board
unnamed: R08B.2, U01B.12 (ILIM)
unnamed: R09B.2, U01B.16 (ISET)
unnamed: R04B.1, U01B.5 (EN2)
unnamed: R03B.1, U01B.6 (EN1)
unnamed: R06B.2, U01B.14 (TMR)
unnamed: R10B.2, U01B.1 (TS)
unnamed: D02B.A, R02B.1
unnamed: D01B.A, R01B.2
unnamed: R21B.2, U1.5 (PROG)
unnamed: R11B.1, TP01B.P$1, U02B.1 (EN)
unnamed: L01B.1, U02B.3 (LX)
unnamed: D06B.C, U1.1 (STAT)
unnamed: D06B.A, R20B.2
VBUS: C01B.2, C19B.2, J01B.1, R20B.1, U1.4 (VIN), U01B.13 (IN); also elsewhere on the board

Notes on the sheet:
Battery management
3V3 buck regulator
Mounting holes
Alternative low-cost battery charger Not populated
Copyrights: CC-BY-SA 3.0

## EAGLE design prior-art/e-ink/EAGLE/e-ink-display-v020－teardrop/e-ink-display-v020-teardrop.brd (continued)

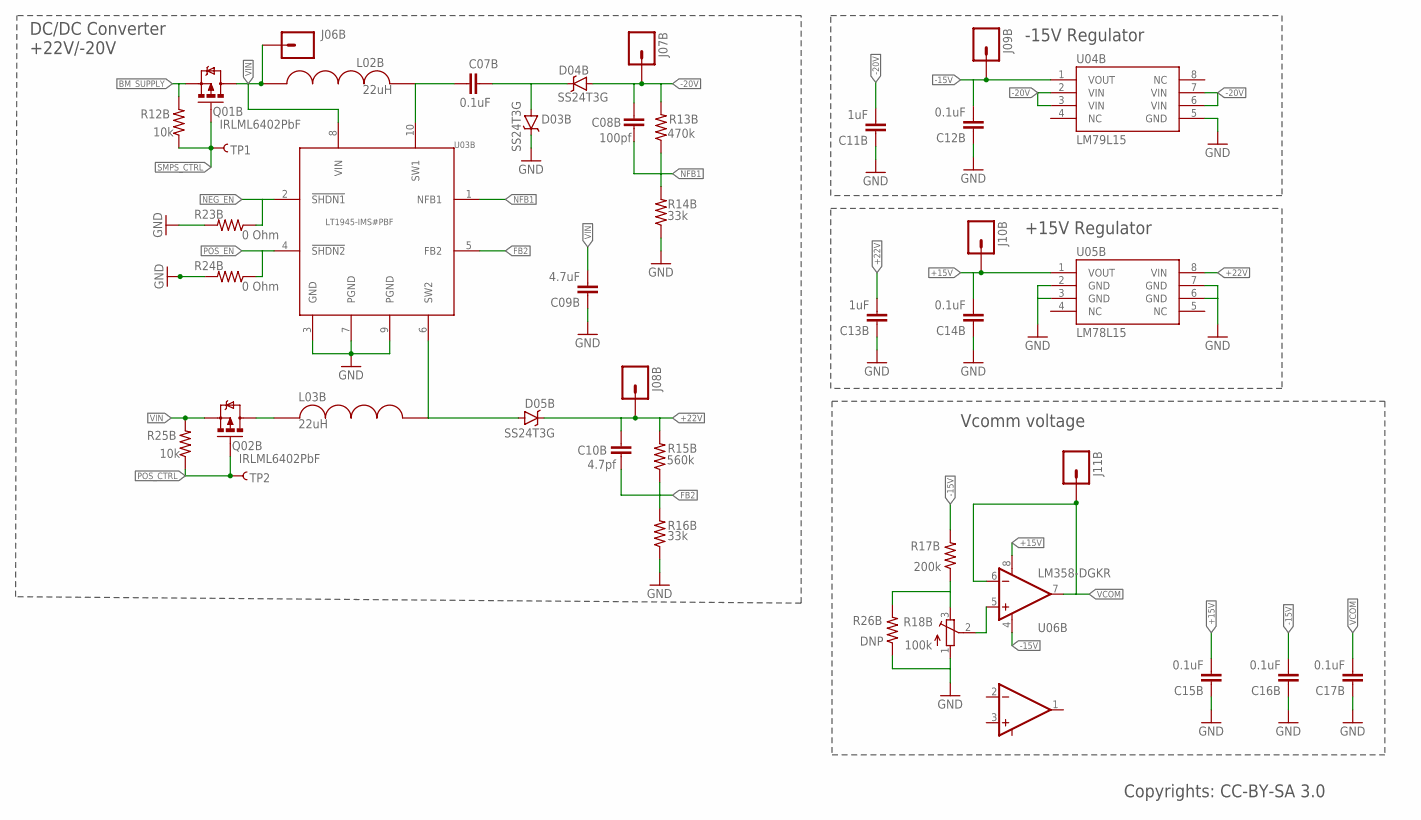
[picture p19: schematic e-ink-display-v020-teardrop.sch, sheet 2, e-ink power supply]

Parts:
C07B, C12B, C14B, C15B, C16B, C17B: 0.1uF; 0603-CAP
C08B: 100pf; 0603-CAP
C09B: 4.7uF; 0603-CAP
C10B: 4.7pf; 0603-CAP
C11B, C13B: 1uF; 0603-CAP
D03B, D04B, D05B: SS24T3G; SMA-DIODE
J06B, J07B, J08B, J09B, J10B, J11B: M01PTH; 1X01
L02B, L03B: 22uH; 4040(1515)
Q01B, Q02B: IRLML6402PbF; SOT23-3
R12B, R25B: 10k; 0603-RES
R13B: 470k; 0603-RES
R14B, R16B: 33k; 0603-RES
R15B: 560k; 0603-RES
R17B: 200k; 0603-RES
R18B: 100k; TC33X
R23B, R24B: 0 Ohm; 0603-RES
R26B: DNP; 0603-RES
TP1, TP2: TEST-POINTBOTHBOTH; TP_15_BOTH
U03B: LT1945-IMS#PBF; MSOP-10
U04B: LM79L15; SO08
U05B: LM78L15; SO08
U06B: LM358-DGKR; MSOP-8

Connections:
+15V: C14B.2, C15B.2, J10B.1, U05B.1 (VOUT), U06B.8 (V+); also elsewhere on the board
+22V: C10B.2, C13B.2, D05B.C, J08B.1, R15B.2, U05B.8 (VIN); also elsewhere on the board
-15V: C12B.2, C16B.2, J09B.1, R17B.2, U04B.1 (VOUT), U06B.4 (V-); also elsewhere on the board
-20V: C08B.2, C11B.2, D04B.A, J07B.1, R13B.2, U04B.2 (VIN), U04B.3 (VIN), U04B.6 (VIN), U04B.7 (VIN); also elsewhere on the board
BM_SUPPLY: Q01B.2 (S), R12B.2; also elsewhere on the board
FB2: C10B.1, R15B.1, R16B.2, U03B.5 (FB2)
GND: C09B.1, C11B.1, C12B.1, C13B.1, C14B.1, C15B.1, C16B.1, C17B.1, D03B.C, R14B.1, R16B.1, R18B.1 (A), R23B.2, R24B.2, R26B.1, U03B.3 (GND), U03B.7 (PGND), U03B.9 (PGND), U04B.5 (GND), U05B.2 (GND), U05B.3 (GND), U05B.6 (GND), U05B.7 (GND); also elsewhere on the board
unnamed: C07B.1, L02B.P$2, U03B.10 (SW1)
unnamed: C07B.2, D03B.A, D04B.C
unnamed: R18B.2 (S), U06B.5 (+IN2)
unnamed: D05B.A, L03B.P$2, U03B.6 (SW2)
unnamed: L03B.P$1, Q02B.3 (D)
unnamed: R17B.1, R18B.3 (E), R26B.2
NEG_EN: R23B.1, U03B.2 (!SHDN1); also elsewhere on the board
NFB1: C08B.1, R13B.1, R14B.2, U03B.1 (NFB1)
POS_CTRL: Q02B.1 (G), R25B.1, TP2.P$1; also elsewhere on the board
POS_EN: R24B.1, U03B.4 (!SHDN2); also elsewhere on the board
SMPS_CTRL: Q01B.1 (G), R12B.1, TP1.P$1; also elsewhere on the board
VCOM: C17B.2, J11B.1, U06B.6 (-IN2), U06B.7 (OUT2); also elsewhere on the board
VIN: C09B.2, J06B.1, L02B.P$1, Q01B.3 (D), Q02B.2 (S), R25B.2, U03B.8 (VIN)

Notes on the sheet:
-15V Regulator
+15V Regulator
Vcomm voltage
DC/DC Converter +22V/-20V
Copyrights: CC-BY-SA 3.0

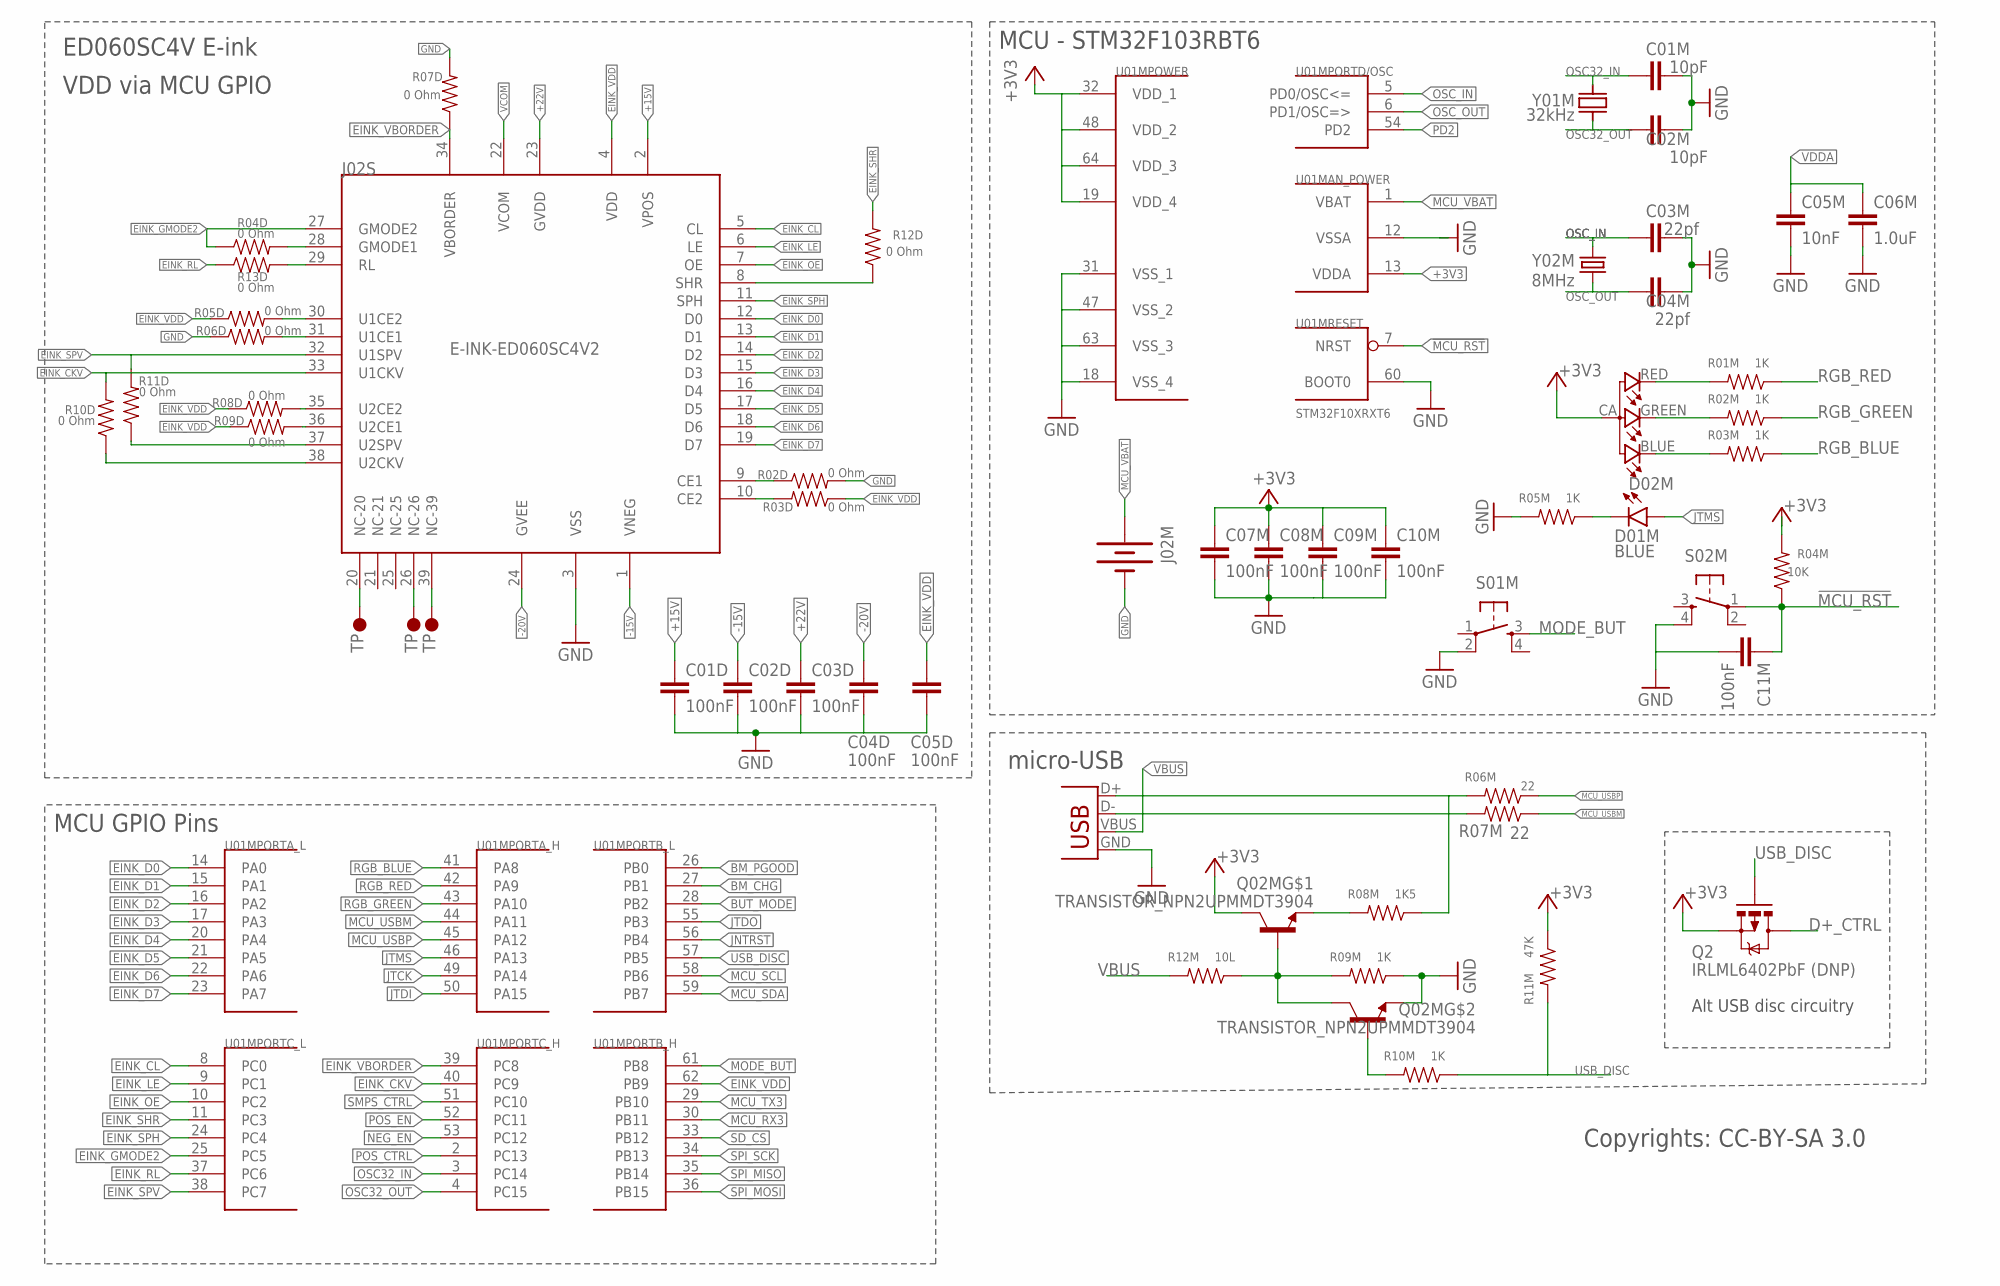
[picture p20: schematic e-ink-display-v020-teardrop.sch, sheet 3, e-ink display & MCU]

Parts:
C01D, C02D, C03D, C04D, C05D, C07M, C08M, C09M, C10M, C11M: 100nF; 0603-CAP
C01M, C02M: 10pF; 0603-CAP
C03M, C04M: 22pf; 0603-CAP
C05M: 10nF; 0603-CAP
C06M: 1.0uF; 0603-CAP
D01M: BLUE; LED-0603
D02M: RGB-LED-CLMVB-FKARGB; PLCC4-2MM-RGB
J01M: USBUSB-MICROB-PAD-EXTEND; USB-MICROB-SLOT-HOLE-EXTEND
J02M: BATTERY20PTH; BATTCOM_20MM_PTH
J02S: E-INK-ED060SC4V2; FPC-0.3-39
Q2: IRLML6402PbF (DNP); SOT23-3
Q02M: TRANSISTOR_NPN2UPMMDT3904; SOT363
R01M, R02M, R03M, R05M, R09M, R10M: 1K; 0603-RES
R02D, R03D, R04D, R05D, R06D, R07D, R08D, R09D, R10D, R11D, R12D, R13D: 0 Ohm; 0603-RES
R04M: 10K; 0603-RES
R06M, R07M: 22; 0603-RES
R08M: 1K5; 0603-RES
R11M: 47K; 0603-RES
R12M: 10L; 0603-RES
S01M, S02M: TAC_SWITCHSMD; TACTILE_SWITCH_SMD
U01M: STM32F10XRXT6; TQFP64
U$1, U$8, U$9: TP1; TP35_BOT
Y01M: 32kHz; FC135
Y02M: 8MHz; CRYSTAL-SMD-5X3

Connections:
!MCU_RST: C11M.1, R04M.1, S02M.1, U01M.7 (NRST); also elsewhere on the board
+3V3: C07M.1, C08M.1, C09M.1, C10M.1, D02M.CA (1), Q2.2 (S), Q02M.6 (C), R04M.2, R11M.1, U01M.13 (VDDA), U01M.19 (VDD_4), U01M.32 (VDD_1), U01M.48 (VDD_2), U01M.64 (VDD_3); also elsewhere on the board
+15V: C01D.1, J02S.2 (VPOS); also elsewhere on the board
+22V: C03D.1, J02S.23 (GVDD); also elsewhere on the board
-15V: C02D.1, J02S.1 (VNEG); also elsewhere on the board
-20V: C04D.1, J02S.24 (GVEE); also elsewhere on the board
BM_CHG: U01M.27 (PB1); also elsewhere on the board
BM_PGOOD: U01M.26 (PB0); also elsewhere on the board
BUT_MODE: U01M.28 (PB2)
CE2: J02S.10 (CE2), R03D.2
D+_CTRL: Q2.3 (D), Q02M.1 (E), R08M.2
EINK_CKV: J02S.33 (U1CKV), R10D.2, U01M.40 (PC9); also elsewhere on the board
EINK_CL: J02S.5 (CL), U01M.8 (PC0); also elsewhere on the board
EINK_D0: J02S.12 (D0), U01M.14 (PA0); also elsewhere on the board
EINK_D1: J02S.13 (D1), U01M.15 (PA1); also elsewhere on the board
EINK_D2: J02S.14 (D2), U01M.16 (PA2); also elsewhere on the board
EINK_D3: J02S.15 (D3), U01M.17 (PA3); also elsewhere on the board
EINK_D4: J02S.16 (D4), U01M.20 (PA4); also elsewhere on the board
EINK_D5: J02S.17 (D5), U01M.21 (PA5); also elsewhere on the board
EINK_D6: J02S.18 (D6), U01M.22 (PA6); also elsewhere on the board
EINK_D7: J02S.19 (D7), U01M.23 (PA7); also elsewhere on the board
EINK_GMODE2: J02S.27 (GMODE2), R04D.1, U01M.25 (PC5); also elsewhere on the board
EINK_LE: J02S.6 (LE), U01M.9 (PC1); also elsewhere on the board
EINK_OE: J02S.7 (OE), U01M.10 (PC2); also elsewhere on the board
EINK_RL: R13D.1, U01M.37 (PC6); also elsewhere on the board
EINK_SHR: R12D.2, U01M.11 (PC3); also elsewhere on the board
EINK_SPH: J02S.11 (SPH), U01M.24 (PC4); also elsewhere on the board
EINK_SPV: J02S.32 (U1SPV), R11D.2, U01M.38 (PC7); also elsewhere on the board
EINK_VBORDER: J02S.34 (VBORDER), R07D.1, U01M.39 (PC8); also elsewhere on the board
EINK_VDD: C05D.1, J02S.4 (VDD), R03D.1, R05D.1, R08D.1, R09D.1, U01M.62 (PB9); also elsewhere on the board
GND: C01D.2, C01M.2, C02D.2, C02M.2, C03D.2, C03M.2, C04D.2, C04M.2, C05D.2, C05M.2, C06M.2, C07M.2, C08M.2, C09M.2, C10M.2, C11M.2, J01M.GND, J02M.2 (-), J02S.3 (VSS), Q02M.4 (E), R02D.2, R05M.2, R06D.1, R07D.2, R09M.1, S01M.2, S02M.4, U01M.12 (VSSA), U01M.18 (VSS_4), U01M.31 (VSS_1), U01M.47 (VSS_2), U01M.60 (BOOT0), U01M.63 (VSS_3); also elsewhere on the board
JNTRST: U01M.56 (PB4); also elsewhere on the board
JTCK: U01M.49 (PA14); also elsewhere on the board
JTDI: U01M.50 (PA15); also elsewhere on the board
JTDO: U01M.55 (PB3); also elsewhere on the board
JTMS: D01M.A, U01M.46 (PA13); also elsewhere on the board
MCU_RX3: U01M.30 (PB11); also elsewhere on the board
MCU_SCL: U01M.58 (PB6); also elsewhere on the board
MCU_SDA: U01M.59 (PB7); also elsewhere on the board
MCU_TX3: U01M.29 (PB10); also elsewhere on the board
MCU_USBM: R07M.1, U01M.44 (PA11)
MCU_USBP: R06M.1, U01M.45 (PA12)
MCU_VBAT: J02M.1 (+), U01M.1 (VBAT)
MODE_BUT: S01M.3, U01M.61 (PB8)
N$: J01M.D+, R06M.2, R08M.1
unnamed: J02S.28 (GMODE1), R04D.2
unnamed: J02S.31 (U1CE1), R06D.2
unnamed: D02M.RED (4), R01M.2
unnamed: Q02M.2 (B), Q02M.3 (C), R09M.2, R12M.1
unnamed: J02S.29 (RL), R13D.2
unnamed: J02S.35 (U2CE2), R08D.2
unnamed: J02S.36 (U2CE1), R09D.2
unnamed: J02S.9 (CE1), R02D.1
unnamed: J02S.20 (NC-20), U$1.P$1
unnamed: J02S.26 (NC-26), U$8.P$1
unnamed: J02S.8 (SHR), R12D.1
unnamed: J02S.39 (NC-39), U$9.P$1
unnamed: Q02M.5 (B), R10M.2
unnamed: D01M.C, R05M.1
unnamed: J01M.D-, R07M.2
NEG_EN: U01M.53 (PC12); also elsewhere on the board
OSC32_IN: C01M.1, U01M.3 (PC14), Y01M.X2 (2)
OSC32_OUT: C02M.1, U01M.4 (PC15), Y01M.X1 (1)
OSC_IN: C03M.1, U01M.5 (PD0/OSC<=), Y02M.3 (2)
OSC_OUT: C04M.1, U01M.6 (PD1/OSC=>), Y02M.1
PD2: U01M.54 (PD2)
POS_CTRL: U01M.2 (PC13); also elsewhere on the board
POS_EN: U01M.52 (PC11); also elsewhere on the board
R02M: D02M.GREEN (3), R02M.2
R03M: D02M.BLUE (2), R03M.2
RGB_BLUE: R03M.1, U01M.41 (PA8)
RGB_GREEN: R02M.1, U01M.43 (PA10)
RGB_RED: R01M.1, U01M.42 (PA9)
SD_CS: U01M.33 (PB12); also elsewhere on the board
SMPS_CTRL: U01M.51 (PC10); also elsewhere on the board
SPI_MISO: U01M.35 (PB14); also elsewhere on the board
SPI_MOSI: U01M.36 (PB15); also elsewhere on the board
SPI_SCK: U01M.34 (PB13); also elsewhere on the board
U1CE2: J02S.30 (U1CE2), R05D.2
U2CKV: J02S.38 (U2CKV), R10D.1
U2SPV: J02S.37 (U2SPV), R11D.1
USB_DISC: Q2.1 (G), R10M.1, R11M.2, U01M.57 (PB5); also elsewhere on the board
VBUS: J01M.VBUS, R12M.2; also elsewhere on the board
VCOM: J02S.22 (VCOM); also elsewhere on the board
VDDA: C05M.1, C06M.1

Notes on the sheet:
ED060SC4V E-ink VDD via MCU GPIO
MCU - STM32F103RBT6
Copyrights: CC-BY-SA 3.0
micro-USB
MCU GPIO Pins
Alt USB disc circuitry

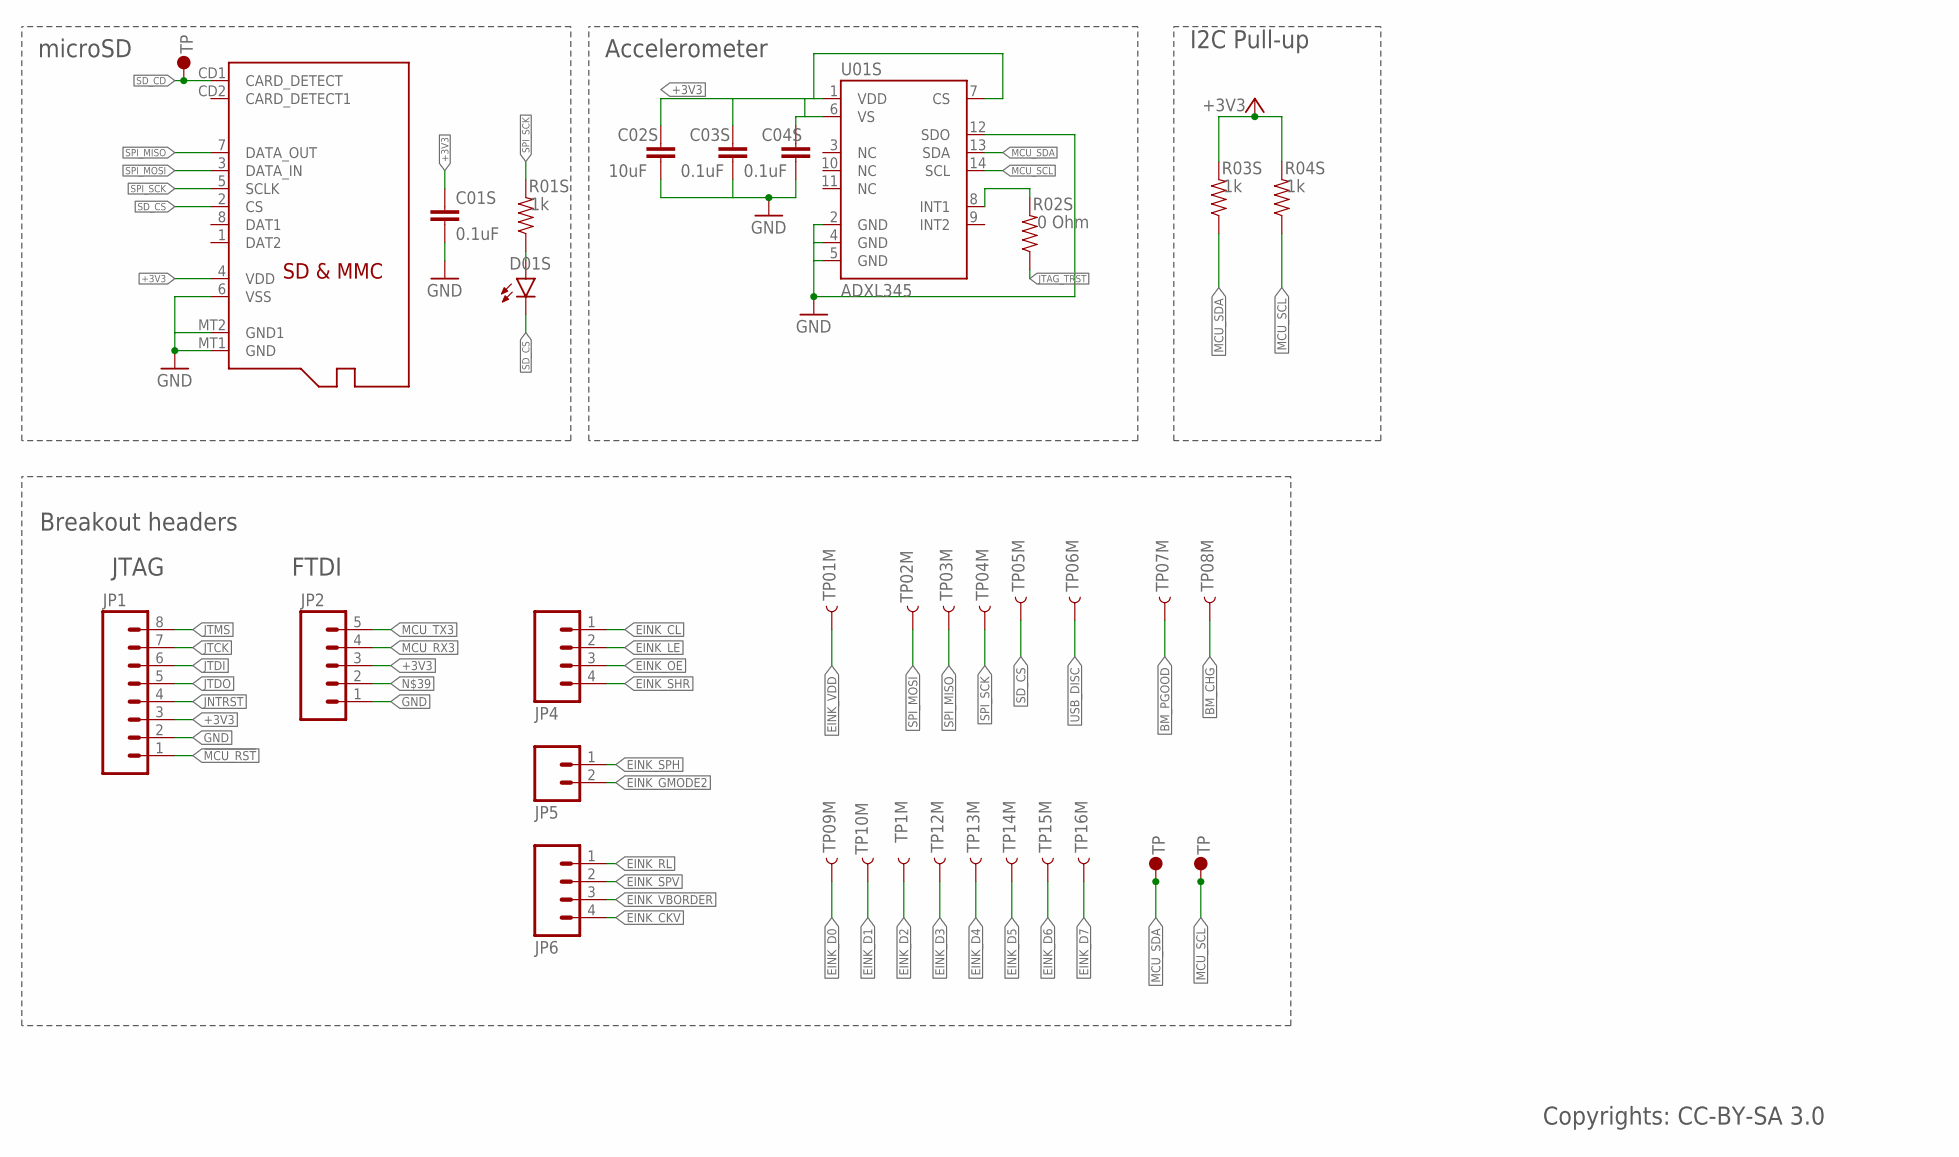
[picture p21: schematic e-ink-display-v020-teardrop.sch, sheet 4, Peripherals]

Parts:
C01S, C03S, C04S: 0.1uF; 0603-CAP
C02S: 10uF; 0603-CAP
D01S: LED0603; LED-0603
J01S: MICROSD
JP1: M08; 1X08_ROUND
JP2: M05PTH; 1X05
JP4, JP6: M04PTH; 1X04
JP5: M02PTH; 1X02
R01S, R03S, R04S: 1k; 0603-RES
R02S: 0 Ohm; 0603-RES
TP01M, TP1M, TP02M, TP04M, TP05M, TP06M, TP07M, TP08M, TP09M, TP10M, TP12M, TP13M, TP14M, TP15M, TP16M: TEST-POINTBOTHBOTH; TP_15_BOTH
TP03M: TEST-POINTTP_15TH_THRU; TP_15TH
TP17M, TP18M: TP1; TP35_BOT
U01S: ADXL345; LGA14
U$5: TP3; TP60_BOT

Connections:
!MCU_RST: JP1.1; also elsewhere on the board
+3V3: C01S.1, C02S.1, C03S.1, C04S.1, J01S.4 (VDD), JP1.3, JP2.3, R03S.2, R04S.2, U01S.1 (VDD), U01S.6 (VS), U01S.7 (CS); also elsewhere on the board
BM_CHG: TP08M.P$1; also elsewhere on the board
BM_PGOOD: TP07M.P$1; also elsewhere on the board
EINK_CKV: JP6.4; also elsewhere on the board
EINK_CL: JP4.1; also elsewhere on the board
EINK_D0: TP09M.P$1; also elsewhere on the board
EINK_D1: TP10M.P$1; also elsewhere on the board
EINK_D2: TP1M.P$1; also elsewhere on the board
EINK_D3: TP12M.P$1; also elsewhere on the board
EINK_D4: TP13M.P$1; also elsewhere on the board
EINK_D5: TP14M.P$1; also elsewhere on the board
EINK_D6: TP15M.P$1; also elsewhere on the board
EINK_D7: TP16M.P$1; also elsewhere on the board
EINK_GMODE2: JP5.2; also elsewhere on the board
EINK_LE: JP4.2; also elsewhere on the board
EINK_OE: JP4.3; also elsewhere on the board
EINK_RL: JP6.1; also elsewhere on the board
EINK_SHR: JP4.4; also elsewhere on the board
EINK_SPH: JP5.1; also elsewhere on the board
EINK_SPV: JP6.2; also elsewhere on the board
EINK_VBORDER: JP6.3; also elsewhere on the board
EINK_VDD: TP01M.P$1; also elsewhere on the board
GND: C01S.2, C02S.2, C03S.2, C04S.2, J01S.6 (VSS), J01S.MT1 (GND), J01S.MT2 (GND1), JP1.2, JP2.1, U01S.2 (GND), U01S.4 (GND), U01S.5 (GND), U01S.12 (SDO); also elsewhere on the board
JNTRST: JP1.4; also elsewhere on the board
JTAG_TRST: R02S.1
JTCK: JP1.7; also elsewhere on the board
JTDI: JP1.6; also elsewhere on the board
JTDO: JP1.5; also elsewhere on the board
JTMS: JP1.8; also elsewhere on the board
MCU_RX3: JP2.4; also elsewhere on the board
MCU_SCL: R04S.1, TP18M.P$1, U01S.14 (SCL); also elsewhere on the board
MCU_SDA: R03S.1, TP17M.P$1, U01S.13 (SDA); also elsewhere on the board
MCU_TX3: JP2.5; also elsewhere on the board
unnamed: R02S.2, U01S.8 (INT1)
R01S: D01S.A, R01S.1
SD_CD: J01S.CD1 (CARD_DETECT), U$5.P$1
SD_CS: D01S.C, J01S.2 (CS), TP05M.P$1; also elsewhere on the board
SPI_MISO: J01S.7 (DATA_OUT), TP03M.P$1; also elsewhere on the board
SPI_MOSI: J01S.3 (DATA_IN), TP02M.P$1; also elsewhere on the board
SPI_SCK: J01S.5 (SCLK), R01S.2, TP04M.P$1; also elsewhere on the board
USB_DISC: TP06M.P$1; also elsewhere on the board

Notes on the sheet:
microSD
Accelerometer
Copyrights: CC-BY-SA 3.0
I2C Pull-up
JTAG
FTDI
Breakout headers

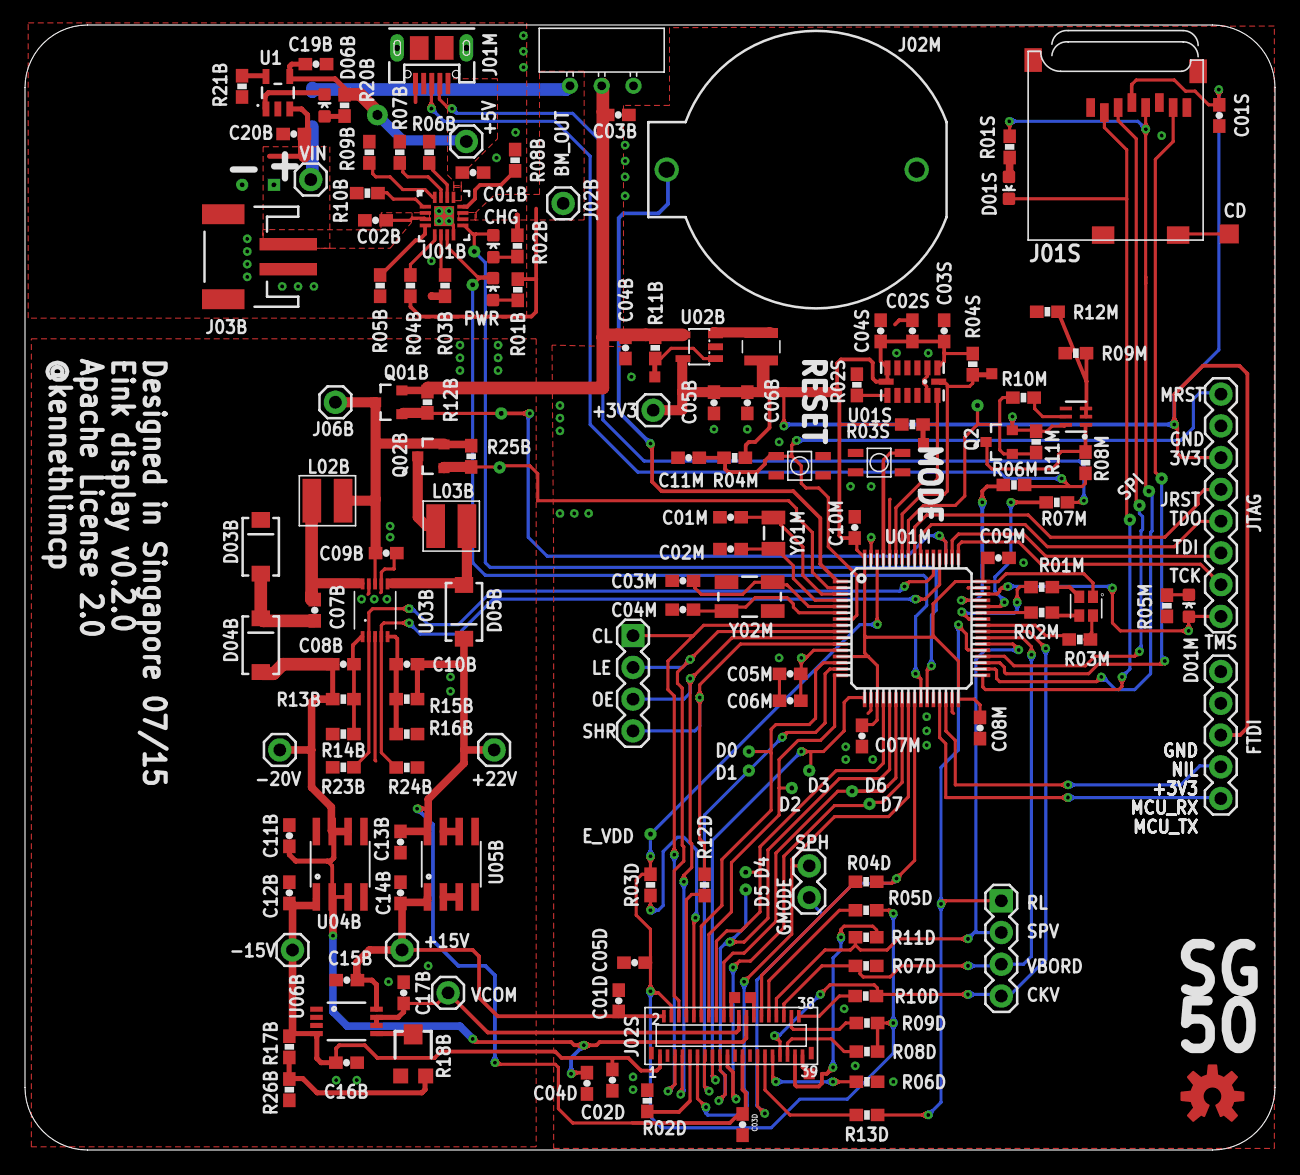
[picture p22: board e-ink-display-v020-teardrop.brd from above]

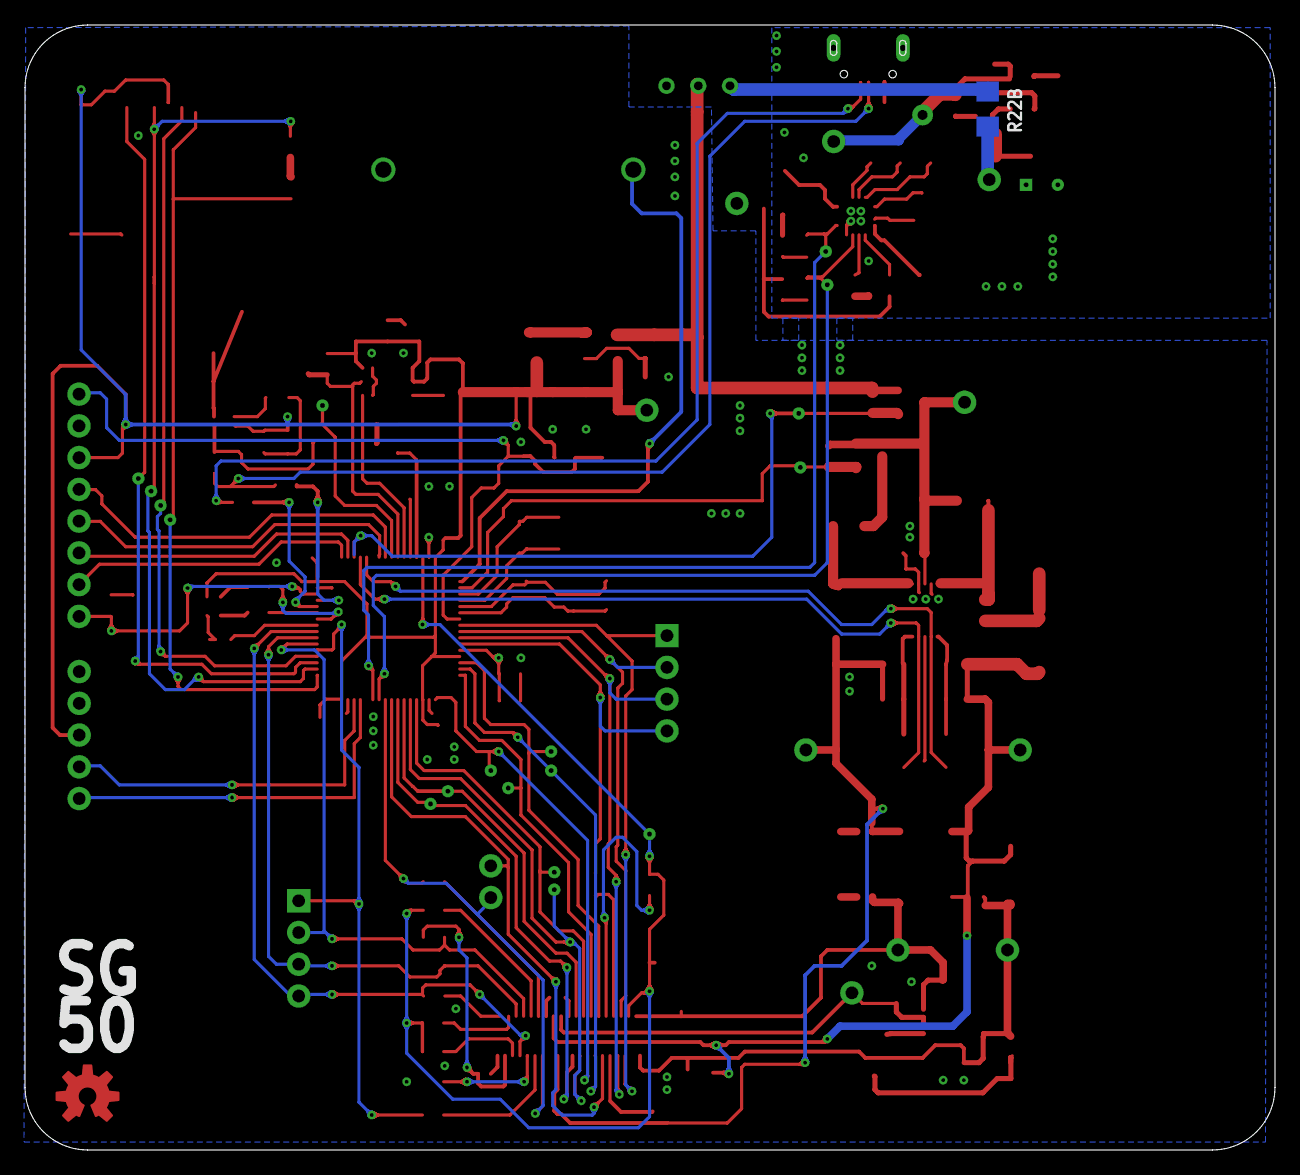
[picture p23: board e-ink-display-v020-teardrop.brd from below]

Board: 4 copper layers, 100.0 x 90.0 mm, 170 parts (8 on the bottom side), 113 nets.

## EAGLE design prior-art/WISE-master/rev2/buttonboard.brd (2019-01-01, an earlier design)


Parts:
R1, R4: 10k; R0805
R2: 1K; R0805
R3: 2k; R0805
R5: 12k; R0805
R6: 39k; R0805
S1, S2, S3, S4, S5: 10-XX; B3F-10XX
U$1: EDGE_CON; EDGE_CON_2

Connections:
+3V3: R2.2, R3.2, R4.2, R5.2, R6.2
DPAD: R1.1, S1.3, S1.4 (P1), S2.3, S2.4 (P1), S3.3, S3.4 (P1), S4.3, S4.4 (P1), S5.3, S5.4 (P1), U$1.1 (2)
GND: R1.2
unnamed: R2.1, S1.1 (S), S1.2 (S1)
unnamed: R3.1, S2.1 (S), S2.2 (S1)
unnamed: R4.1, S3.1 (S), S3.2 (S1)
unnamed: R5.1, S4.1 (S), S4.2 (S1)
unnamed: R6.1, S5.1 (S), S5.2 (S1)


Board: 2 copper layers, 27.4 x 27.4 mm, 12 parts (0 on the bottom side), 7 nets.

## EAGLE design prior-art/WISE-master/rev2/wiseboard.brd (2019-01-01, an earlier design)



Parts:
22: 587-2103-1-ND
BOOT: LED1; CHIP-LED0805
C1, C2, C3, C6: 1uF; C0805
C4, C5, C8, C10: 10uF; C0805
CHRG/LBO: LED3; CHIP-LED0805
D1: MBR120VLSFT1G; SOD-123
D2: MBR120; SOD-123
D3: 1n4148; SOD-123
D4, D5, D6: SS24; DO214AA
DONE: LED4; CHIP-LED0805
IC1: LT1945; SOP50P490X110-10N
IC2: LM358; SO08
IC3: L79L15; SO8
IC4: L78L15; SO8
IC5: W25Q; SO8
IC8: IC6; SOT95P280X145-5N
IC9: BQ24210DQCT; DQC10_P84X2P4
J1: BAT_CON; EDGE_CON_2
J2: SOL_CON; EDGE_CON_2
J3: PROG_HEADER; EDGE_CON_4
J4: BUT_CON; EDGE_CON_2
POWERGOOD: LED2; CHIP-LED0805
Q1: IRLM; SOT23
R1, R15, R17, R18, R21, R22: 10K; R0805
R2, R37: 10k; R0805
R3: 470k; R0805
R4, R5, R7, R8: 39k; R0805
R6: 560k; R0805
R9: 200k; R0805
R10, R13, R14, R23: 1K; R0805
R36: 790; R0805
R38: 7.6k; R0805
SW1, SW2: SPST_TACT-KMR2; KMR2
U3: ESP-WROOM-03
U$4: FH26W-39S; HFQ339CT-ND
U$5: 587-2103-1-ND
VR1: TC33X-104ECT-ND; TRIM_TC33X-2-103E

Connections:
+3V3: BOOT.A, IC5.3 (WP), IC5.8 (VCC), IC8.5 (VOUT), R21.2, U3.2 (3V3), U$4.P$4 (VDD), U$4.P$8 (SHR), U$4.P$10 (CE2), U$4.P$29 (RL), U$4.P$30 (U1CE2), U$4.P$35 (U2CE2), U$4.P$36 (U2CE1)
+5V: D2.C, IC8.1 (VIN), J3.3, R22.1
+15V: C6.1, IC4.1 (VOUT), R8.2, U$4.P$2 (VPOS)
+22V: C5.1, D6.C, IC4.8 (VIN), R6.2, U$4.P$23 (GVDD)
-15V: C1.1, IC3.1 (VOUT), R5.1, R9.1, U$4.P$1 (VNEG)
-20V: C4.1, D5.A, IC3.2 (VIN), IC3.3 (VIN), IC3.6 (VIN), IC3.7 (VIN), R3.2, U$4.P$24 (GVEE)
BAT_SENS: R1.1, R15.2, U3.4 (SENSOR_VP)
BUT_CON: J4.1 (2), U3.8 (IO32)
CKV: U3.37 (IO23), U$4.P$33 (U1CKV), U$4.P$38 (U2CKV)
CL: U3.23 (IO15), U$4.P$5 (CL)
CLK: IC5.6 (CLK), U3.20 (SCK)
D0: U3.26 (IO4), U$4.P$12 (DO)
D1: U3.27 (IO16), U$4.P$13 (D1)
D2: U3.13 (IO14), U$4.P$14 (D2)
D3: U3.28 (IO17), U$4.P$15 (D3)
D4: U3.12 (IO27), U$4.P$16 (D4)
D5: U3.29 (IO5), U$4.P$17 (D5)
D6: U3.30 (IO18), U$4.P$18 (D6)
D7: U3.31 (IO19), U$4.P$19 (D7)
ESP_DI: IC5.2 (DO), U3.22 (SDI)
ESP_DO: IC5.5 (DI), U3.21 (SDO)
FB2: C5.2, IC1.5 (FB2), R6.1, R7.2
GMODE: U$4.P$27 (GMDE2), U$4.P$28 (GMDE1)
GND: C1.2, C2.2, C6.2, C8.1, C10.1, D4.C, DONE.C, IC1.3 (GND), IC1.7 (PGND), IC1.9 (PGND_2), IC3.5 (GND), IC4.2 (GND), IC4.3 (GND), IC4.6 (GND), IC4.7 (GND), IC5.4 (GND), IC8.2 (GND), IC9.3 (VSS), IC9.7 (!EN), IC9.11 (EPAD), J1.2 (1), J2.2 (1), J3.4, J4.2 (1), R4.1, R5.2, R7.1, R8.1, R15.1, R18.1, R36.1, R37.1, SW1.1, SW1.3 (P1), SW2.1, SW2.3 (P1), U3.1 (GND), U3.15 (GND), U3.38 (GND), U3.GND, U$4.GND@1 (GND), U$4.GND@2 (GND), U$4.P$3 (VSS), U$4.P$9 (CE1), U$4.P$31 (U1CE1), U$4.P$34 (VBRDR), VR1.3
GPIO0: R23.1, SW1.2 (S), SW1.4 (S1), U3.25 (IO0)
IC5: IC5.1 (CS), U3.19 (SCS)
LE: U3.16 (IO13), U$4.P$6 (LE)
unnamed: IC2.3 (+IN), VR1.2
unnamed: 22.P$2 (2), C3.1, IC1.10 (SW1)
unnamed: C8.2, D1.C, IC9.1 (VBUS)
unnamed: 22.P$1 (1), C2.1, IC1.8 (VIN), Q1.3 (D), U$5.P$2 (2)
unnamed: D6.A, IC1.6 (SW2), U$5.P$1 (1)
unnamed: C3.2, D4.A, D5.C
unnamed: R9.2, VR1.1
unnamed: IC9.6 (!PG), R10.2
unnamed: CHRG/LBO.C, R14.1
unnamed: POWERGOOD.C, R10.1
unnamed: DONE.A, R13.1
unnamed: IC9.8 (!CHG), R13.2, R14.2
unnamed: IC9.2 (ISET), R36.2
unnamed: BOOT.C, R23.2
unnamed: IC8.3 (EN), R22.2
unnamed: IC9.5 (TS), R37.2, R38.1
unnamed: IC9.4 (VTSB), R38.2
NEGEN: IC1.2 (~SHDN1), U3.9 (IO33)
NFB1: C4.2, IC1.1 (NFB1), R3.1, R4.2
OE: U3.24 (IO2), U$4.P$7 (OE)
PANEL: D1.A, J2.1 (2), R17.2
PANEL_SENS: R17.1, R18.2, U3.5 (SENSOR_VN)
POSEN: IC1.4 (~SHDN2), U3.10 (IO25)
RESET: R21.1, SW2.2 (S), SW2.4 (S1), U3.3 (EN)
RXD: D3.A, U3.34 (RXD)
RXD_5V: D3.C, J3.2
SPH: U3.33 (IO21), U$4.P$11 (SPH)
SPV: U3.36 (IO22), U$4.P$32 (U1SPV), U$4.P$37 (U2SPV)
SUP_CTRL: Q1.1 (G), R2.2, U3.11 (IO26)
TXD: J3.1, U3.35 (TXD)
V+: IC2.8 (V+)
V-: IC2.4 (V-)
VBAT: C10.2, CHRG/LBO.A, D2.A, IC9.10 (BAT), J1.1 (2), POWERGOOD.A, Q1.2 (S), R1.2, R2.1
VCOMMON: IC2.1 (OUT), IC2.2 (-IN), U$4.P$22 (VCOM)

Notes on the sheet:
V-Common Generator
Programming Utilities
Programing Header
Voltage Generation
Charge Circuitry
ESP32
Voltage Regulator
Screen Connector
Note: A write enable instruction must be issued before a anything else happens. The device starts in a write-disabled state
WP pulled high to disable hardware write-protection
Flash Memory Chip

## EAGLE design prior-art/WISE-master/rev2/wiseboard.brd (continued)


Board: 2 copper layers, 42.0 x 42.0 mm, 58 parts (0 on the bottom side), 59 nets.

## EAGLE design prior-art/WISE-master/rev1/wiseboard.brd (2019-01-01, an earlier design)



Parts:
22: 587-2103-1-ND
BAT_CON: JST_2PIN-SMT-RA; JST-PH-2-SMT-RA
BAT_PIN: PINHD-1X2; 1X02
BOOT: GREEN; CHIP-LED0805
C1, C3, C6, C7, C11, C12: 100nF; C1206
C2, C9, C16: 2u2F; C1206
C4: 100pF; C1206
C5: 4.7pF; C1206
C8: 10uF; C1206
CHRG/LBO: ORANGE; CHIP-LED0805
D1: MBR120VLSFT1G; SOD-123
D2: MBR120; SOD-123
D3: 1n4148; SOD-123
DONE: GREEN; CHIP-LED0805
ESPDEBUG_1, ESPDEBUG_2: PINHD-1X8; 1X08
IC2: LM358MX; SO08
INPUTBUTTONHEADER: PINHD-1X2; 1X02
JP1: PROG_HEADER; 1X04
JP3, JP4: JUMPER; SMT-JUMPER_2_NC_PASTE_NO-SILK
POWERGOOD: BLUE; CHIP-LED0805
Q1, Q2: IRLML6402TRPBF; SOT23
R1, R33: 12k; M1206
R2: 47k; M1206
R3: 470k; M1206
R4, R29, R34: 33k; M1206
R5, R8: 39k; R1206
R6: 560k; R1206
R7: 33k; R1206
R9: 200k; M1206
R10, R13, R14, R30: 1K; M1206
R20, R21, R22, R24, R25: 10K; R1206
R23: 1K; R1206
R28, R32: 10k; M1206
R31: 2k; M1206
R35: 100k; M1206
R36: 790; R1206
R37: 10k; R1206
R38: 7.6k; R1206
S1, S2, S3, S4, S5, S6, S7: 10-XX; B3F-10XX
SOLAR: 455-1749-1-ND; JST-PH-2-SMT-RA
SOLARPIN: PINHD-1X2; 1X02
U1: LT1945EMSPBF; SOP50P490X110-10N
U2: BQ24210DQCT; DQC10_P84X2P4
U$2: 497-7278-1-ND; SO8
U$3: 497-7303-1-ND; SO8
U$4: HFQ339CT-ND
U$5: 587-2103-1-ND
U$6, U$7, U$8: SS24; DO214AA
U$11, U$12: 1727-3473-ND; SO16
U$13: FSA3157; SC70-6L
U$14: AP2112K-3.3TRG1DICT-ND; SOT95P280X145-5N
U$23: W25Q32JVSSIQ; SO8
VR1: TC33X-104ECT-ND; TRIM_TC33X-2-103E
X1: 1528-1438-ND; ESP-12

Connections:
+3V3: BOOT.A, C16.1, ESPDEBUG_1.8, INPUTBUTTONHEADER.1, Q2.2 (S), R20.2, R21.2, R24.2, R30.2, R31.2, R32.2, R33.2, R34.2, U$13.5 (VCC), U$14.5 (VOUT), U$23.3 (WP), U$23.8 (VCC), X1.8 (VCC)
+15V: C6.1, IC2.8 (V+), R8.2, U$2.1 (VOUT), U$4.P$2 (VPOS)
+22V: C5.1, R6.2, U$2.8 (VIN), U$4.P$23 (GVDD), U$8.C
-15V: C1.1, IC2.4 (V-), R5.1, R9.1, U$3.1 (VOUT), U$4.P$1 (VNEG)
-20V: C4.1, R3.2, U$3.2 (VIN), U$4.P$24 (GVEE), U$7.A
ADC: ESPDEBUG_1.2, R28.1, R29.2, X1.2 (ADC)
BOOSTENA: ESPDEBUG_2.6, Q2.1 (G), R2.1, R24.1, X1.11 (GPIO2)
CHARGE_EN: JP4.2, U2.7 (!EN)
CH_PD: ESPDEBUG_1.3, R20.1, X1.3 (CH_PD)
CL: ESPDEBUG_2.4, U$4.P$5 (CL), X1.13 (GPIO5)
FB2: C5.2, R6.1, R7.2, U1.5 (FB2)
GND: BAT_CON.2 (1), BAT_PIN.2, C1.2, C2.2, C6.2, C7.2, C8.2, C9.2, C11.2, C12.2, C16.2, DONE.C, ESPDEBUG_2.8, JP1.4, JP4.1, R4.1, R5.2, R7.1, R8.1, R25.1, R29.1, R35.2, R36.1, R37.1, S1.3, S1.4 (P1), S2.3, S2.4 (P1), SOLAR.2 (1), SOLARPIN.1, U1.3 (GND), U1.7 (PGND), U1.9 (PGND_2), U2.3 (VSS), U2.11 (EPAD), U$2.2 (GND), U$2.3 (GND), U$2.6 (GND), U$2.7 (GND), U$3.5 (GND), U$4.GND@1 (GND), U$4.GND@2 (GND), U$4.P$3 (VSS), U$4.P$9 (NC), U$4.P$31 (U1CE1), U$4.P$34 (VBRDR), U$6.C, U$11.8 (GND), U$12.8 (GND), U$13.2 (GND), U$14.2 (GND), U$23.4 (GND), VR1.3, X1.9 (GND)
GPIO0: ESPDEBUG_2.5, R23.1, S1.1 (S), S1.2 (S1), X1.12 (GPIO0)
GPIO12: ESPDEBUG_1.6, U$12.1 (STR), U$23.2 (MISO), X1.6 (GPIO12)
GPIO13: ESPDEBUG_1.7, U$11.2 (D), U$12.2 (D), U$23.5 (MOSI), X1.7 (GPIO13)
GPIO14: ESPDEBUG_1.5, U$11.3 (CP), U$12.3 (CP), U$23.6 (CLK), X1.5 (GPIO14)
GPIO15: ESPDEBUG_2.7, R25.2, U$23.1 (CS), X1.10 (GPIO15)
GPIO16: ESPDEBUG_1.4, JP3.2, X1.4 (GPIO16)
LE: U$4.P$6 (LE), U$12.14 (QP4)
unnamed: IC2.3 (+IN), VR1.2
unnamed: 22.P$2 (2), C3.1, U1.10 (SW1)
unnamed: Q1.1 (G), R1.2, R2.2
unnamed: 22.P$1 (1), C2.1, Q1.3 (D), U1.8 (VIN), U$5.P$2 (2)
unnamed: U1.6 (SW2), U$5.P$1 (1), U$8.A
unnamed: C3.2, U$6.A, U$7.C
unnamed: D1.A, SOLAR.1 (2), SOLARPIN.2
unnamed: R9.2, VR1.1
unnamed: R10.2, U2.6 (!PG)
unnamed: CHRG/LBO.C, R14.1
unnamed: POWERGOOD.C, R10.1
unnamed: R28.2, U$13.4 (A)
unnamed: C9.1, D1.C, U2.1 (VBUS)
unnamed: DONE.A, R13.1
unnamed: R13.2, R14.2, U2.8 (!CHG)
unnamed: R36.2, U2.2 (ISET)
unnamed: BOOT.C, R23.2
unnamed: R22.2, U$14.3 (EN)
unnamed: INPUTBUTTONHEADER.2, R35.1, S3.3, S3.4 (P1), S4.3, S4.4 (P1), S5.3, S5.4 (P1), S6.3, S6.4 (P1), S7.3, S7.4 (P1), U$13.1 (B1)
unnamed: R30.1, S3.1 (S), S3.2 (S1)
unnamed: R37.2, R38.1, U2.5 (TS)
unnamed: R31.1, S4.1 (S), S4.2 (S1)
unnamed: R38.2, U2.4 (VTSB)
unnamed: R32.1, S5.1 (S), S5.2 (S1)
unnamed: R33.1, S6.1 (S), S6.2 (S1)
unnamed: R34.1, S7.1 (S), S7.2 (S1)
NEGEN: U1.2 (~SHDN1), U$12.5 (QP1)
NFB1: C4.2, R3.1, R4.2, U1.1 (NFB1)
OE: ESPDEBUG_2.3, U$4.P$7 (OE), X1.14 (GPIO4)
POSEN: U1.4 (~SHDN2), U$12.4 (QP0)
QP0: U$4.P$12 (DO), U$11.4 (QP0)
QP1: U$4.P$13 (D1), U$11.5 (QP1)
QP2: U$4.P$14 (D2), U$11.6 (QP2)
QP2@2: U$4.P$32 (U1SPV), U$4.P$37 (U2SPV), U$12.6 (QP2)
QP3: U$4.P$15 (D3), U$11.7 (QP3)
QP4: U$4.P$16 (D4), U$11.14 (QP4)
QP5: U$4.P$17 (D5), U$11.13 (QP5)
QP6: U$4.P$18 (D6), U$11.12 (QP6)
QP6@2: U$4.P$27 (GMDE2), U$4.P$28 (GMDE1), U$12.12 (QP6)
QP7: U$4.P$19 (D7), U$11.11 (QP7)
QP7@2: U$4.P$33 (U1CKV), U$4.P$38 (U2CKV), U$12.11 (QP7)
RESET: ESPDEBUG_1.1, JP3.1, R21.1, S2.1 (S), S2.2 (S1), X1.1 (RESET)
RXD: D3.A, ESPDEBUG_2.2, U$13.6 (S), X1.15 (RXD)
RXD_5V: D3.C, JP1.2
SPH: U$4.P$11 (SPH), U$12.13 (QP5)
TXD: ESPDEBUG_2.1, JP1.1, X1.16 (TXD)
VBAT: BAT_CON.1 (2), BAT_PIN.1, C8.1, CHRG/LBO.A, D2.A, POWERGOOD.A, Q1.2 (S), R1.1, U2.10 (BAT), U$13.3 (B0)
VCC: D2.C, JP1.3, R22.1, U$14.1 (VIN)
VCOMMON: C7.1, IC2.1 (OUT), IC2.2 (-IN), U$4.P$22 (VCOM)
VDD: C11.1, C12.1, Q2.3 (D), U$4.P$4 (VDD), U$4.P$8 (SHR), U$4.P$10 (NC), U$4.P$29 (RL), U$4.P$30 (U1CE2), U$4.P$35 (U2CE2), U$4.P$36 (U2CE1), U$11.1 (STR), U$11.15 (OE), U$11.16 (VCC), U$12.15 (OE), U$12.16 (VCC)

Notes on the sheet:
Button Array and Battery Monitor
V-Common Generator
Programming Utilities
Programing Header
Voltage Generation
Charge Circuitry
ESP8266
Voltage Regulator
Shift Registers and Screen Connector
ESP DEBUG HEADER
Note: GPIO15 is used to detect bootmode and is also connected to CS of flash chip - may cause issues
Note: A write enable instruction must be issued before a anything else happens. The device starts in a write-disabled state
WP pulled high to disable hardware write-protection
Flash Memory Chip



Board: 2 copper layers, 87.0 x 67.0 mm, 85 parts (2 on the bottom side), 69 nets.

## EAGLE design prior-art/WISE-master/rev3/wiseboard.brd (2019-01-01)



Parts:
3V3, 5V, 5V1: TPSTP20R; TP20R
+15V, +22V: TPSTP20R; TP20R
-15V, -20V: TPSTP20R; TP20R
BOOT: LED1; CHIP-LED0805
C1, C6: 1uF > 15V; C0805
C2: 4.7uF; C0805
C3, C8, C10: 1uF; C0805
C4: 100pF; C0805
C5: 4.7pF > 22V; C0805
CHRG/LBO: LED3; CHIP-LED0805
D1: MBR120; SOD-123
D2: 1n4148; SOD-123
D3, D4, D5: SS24; DO214AA
DONE: LED4; CHIP-LED0805
GND, GND17, GND23: TPSTP20SQ; TP20SQ
IC1: LT1945; SOP50P490X110-10N
IC2: LM358; SO08
IC3: L79L15; SO8
IC4: L78L15; SO8
IC5: W25Q; SO8
IC6: AP2112; SOT95P280X145-5N
IC7: ESP-WROOM-03
IC9: BQ24210DQCT; DQC10_P84X2P4
IO0, IO1: TPSTP20R; TP20R
J1: BAT_CON; EDGE_CON_2
J2: SOL_CON; EDGE_CON_2
J3: PROG_HEADER; EDGE_CON_4
J4: BUT_CON; EDGE_CON_2
L1, L2: NR6028T220M
POWERGOOD: LED2; CHIP-LED0805
Q2: IRLML6402TRPBF; SOT23
R1, R15, R17, R18, R21, R22: 10K; R0805
R2, R37: 10k; R0805
R3: 560k > 20V; R0805
R4: 39k > 20V; R0805
R5, R7, R8: 39k; R0805
R6: 560k; R0805
R9: 200k; R0805
R10, R13, R14, R23: 1K; R0805
R36: 790; R0805
R38: 7.6k; R0805
RST, RST1: TPSTP20R; TP20R
RXD, RXD1: TPSTP20R; TP20R
SW1, SW2: SPST_TACT-KMR2; KMR2
TXD, TXD1: TPSTP20R; TP20R
U$4: FH26W-39S; HFQ339CT-ND
VR1: TC33X-104ECT-ND; TRIM_TC33X-2-103E

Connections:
+3V3: 3V3.TP, BOOT.A, IC5.3 (WP), IC5.8 (VCC), IC6.5 (VOUT), IC7.2 (3V3), R21.2, U$4.P$4 (VDD), U$4.P$8 (SHR), U$4.P$10 (CE2), U$4.P$29 (RL), U$4.P$30 (U1CE2), U$4.P$35 (U2CE2), U$4.P$36 (U2CE1)
+5V: 5V.TP, 5V1.TP, D1.C, IC6.1 (VIN), J3.3, R22.1
+15V: +15V.TP, C6.1, IC2.8 (V+), IC4.1 (VOUT), R8.2, U$4.P$2 (VPOS)
+22V: +22V.TP, C5.1, D5.C, IC4.8 (VIN), R6.2, U$4.P$23 (GVDD)
-15V: -15V.TP, C1.1, IC2.4 (V-), IC3.1 (VOUT), R5.1, R9.1, U$4.P$1 (VNEG)
-20V: -20V.TP, C4.1, D3.A, IC3.2 (VIN), IC3.3 (VIN), IC3.6 (VIN), IC3.7 (VIN), R3.2, U$4.P$24 (GVEE)
BAT_SENS: IC7.4 (SENSOR_VP), R1.1, R15.2
BUT_CON: IC7.8 (IO32), J4.1 (2)
CKV: IC7.37 (IO23), U$4.P$33 (U1CKV), U$4.P$38 (U2CKV)
CL: IC7.23 (IO15), U$4.P$5 (CL)
CLK: IC5.6 (CLK), IC7.20 (SCK)
CS: IC5.1 (CS), IC7.19 (SCS)
D0: IC7.26 (IO4), U$4.P$12 (DO)
D1: IC7.27 (IO16), U$4.P$13 (D1)
D2: IC7.13 (IO14), U$4.P$14 (D2)
D3: IC7.28 (IO17), U$4.P$15 (D3)
D4: IC7.12 (IO27), U$4.P$16 (D4)
D5: IC7.29 (IO5), U$4.P$17 (D5)
D6: IC7.30 (IO18), U$4.P$18 (D6)
D7: IC7.31 (IO19), U$4.P$19 (D7)
ESP_DI: IC5.2 (DO), IC7.22 (SDI)
ESP_DO: IC5.5 (DI), IC7.21 (SDO)
FB2: C5.2, IC1.5 (FB2), R6.1, R7.2
GMODE: IC7.6 (IO34), U$4.P$27 (GMDE2), U$4.P$28 (GMDE1)
GND: C1.2, C2.2, C6.2, C8.1, C10.1, D4.C, DONE.C, GND.TP, GND17.TP, GND23.TP, IC1.3 (GND), IC1.7 (PGND), IC1.9 (PGND_2), IC3.5 (GND), IC4.2 (GND), IC4.3 (GND), IC5.4 (GND), IC6.2 (GND), IC7.1 (GND), IC7.15 (GND), IC7.38 (GND), IC7.GND, IC9.3 (VSS), IC9.7 (!EN), IC9.9 (VDPM), IC9.11 (EPAD), J1.2 (1), J2.2 (1), J3.4, J4.2 (1), R4.1, R5.2, R7.1, R8.1, R15.1, R18.1, R36.1, R37.1, SW1.1, SW1.3 (P1), SW2.1, SW2.3 (P1), U$4.GND@1 (GND), U$4.GND@2 (GND), U$4.P$3 (VSS), U$4.P$9 (CE1), U$4.P$31 (U1CE1), U$4.P$34 (VBRDR), VR1.3
GPIO0: IC7.25 (IO0), IO0.TP, IO1.TP, R23.1, SW1.2 (S), SW1.4 (S1)
LE: IC7.16 (IO13), U$4.P$6 (LE)
unnamed: IC2.3 (+IN), VR1.2
unnamed: C3.1, IC1.10 (SW1), L2.P$2 (2)
unnamed: C2.1, IC1.8 (VIN), L1.P$1 (1), L2.P$1 (1), Q2.3 (D)
unnamed: D5.A, IC1.6 (SW2), L1.P$2 (2)
unnamed: C3.2, D3.C, D4.A
unnamed: R9.2, VR1.1
unnamed: IC9.6 (!PG), R10.2
unnamed: CHRG/LBO.C, R14.1
unnamed: POWERGOOD.C, R10.1
unnamed: DONE.A, R13.1
unnamed: IC9.8 (!CHG), R13.2, R14.2
unnamed: IC9.2 (ISET), R36.2
unnamed: BOOT.C, R23.2
unnamed: IC6.3 (EN), R22.2
unnamed: IC9.5 (TS), R37.2, R38.1
unnamed: IC9.4 (VTSB), R38.2
NEGEN: IC1.2 (~SHDN1), IC7.9 (IO33)
NFB1: C4.2, IC1.1 (NFB1), R3.1, R4.2
OE: IC7.24 (IO2), U$4.P$7 (OE)
PANEL: C8.2, IC9.1 (VBUS), J2.1 (2), R17.2
PANEL_SENS: IC7.5 (SENSOR_VN), R17.1, R18.2
POSEN: IC1.4 (~SHDN2), IC7.10 (IO25)
RESET: IC7.3 (EN), R21.1, RST.TP, RST1.TP, SW2.2 (S), SW2.4 (S1)
RXD: D2.A, IC7.34 (RXD), RXD.TP, RXD1.TP
RXD_5V: D2.C, J3.2
SPH: IC7.33 (IO21), U$4.P$11 (SPH)
SPV: IC7.36 (IO22), U$4.P$32 (U1SPV), U$4.P$37 (U2SPV)
SUP_CTRL: IC7.11 (IO26), Q2.1 (G), R2.2
TXD: IC7.35 (TXD), J3.1, TXD.TP, TXD1.TP
VBAT: C10.2, CHRG/LBO.A, D1.A, IC9.10 (BAT), J1.1 (2), POWERGOOD.A, Q2.2 (S), R1.2, R2.1
VCOMMON: IC2.1 (OUT), IC2.2 (-IN), U$4.P$22 (VCOM)

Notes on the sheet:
V-Common Generator
Programming Utilities
Programing Header
Voltage Generation
Charge Circuitry
ESP32
Voltage Regulator
Screen Connector
Note: A write enable instruction must be issued before a anything else happens. The device starts in a write-disabled state
WP pulled high to disable hardware write-protection
Flash Memory Chip
some caps should be rated for >25v
GMODe is on pin 34



Board: 2 copper layers, 58.0 x 34.5 mm, 75 parts (6 on the bottom side), 58 nets.

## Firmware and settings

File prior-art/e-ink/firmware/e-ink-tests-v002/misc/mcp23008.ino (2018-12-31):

#include "Adafruit_MCP23008.h"

/*
2 x MCP23008 on the e-ink display
For e-ink data control D0-D7, the address is 0x20
For other pins control, the address is 0x21

The available commands are:

d - Pull-down
h - help info
i - set all to INPUT
o - set all to OUTPUT
p - enter DFU mode
r - read the GPIO pin status
u - Pull-up
*/

Adafruit_MCP23008 mcp1;
Adafruit_MCP23008 mcp2;

SYSTEM_MODE(MANUAL);

void setup() {
  mcp1.begin();       // use default address 0
  mcp2.begin(1);      // use address 1

  //start safe and set all the pins to be an input
  for (uint8_t i=0;i<7;i++){
    mcp1.pinMode(i, INPUT);
    mcp2.pinMode(i, INPUT);
  }

  //Make use of RGB led
  RGB.control(true);
  RGB.color(0, 255, 0); //start off with green status

  //Using USB serial to perform tests
  Serial.begin(9600);
  while(!Serial.available()) Spark.process();
  Serial.flush();
  Serial.println("\ne-ink board testing v001");
  Serial.println("MCP23008 test");
}


void loop() {
  char input;

  if(Serial.available()){
    input = Serial.read();

    switch(input){

      case 'p':
        System.bootloader();
        break;

      case 'i':
        Serial.println("\nSetting all pins to input.");
        Serial.print("hit e char to confirm: ");
        while(!Serial.available());
        if(Serial.read() == 'e'){
          RGB.color(0, 0, 255); //blue
          for (uint8_t i=0;i<7;i++){
            mcp1.pinMode(i, INPUT);
            mcp2.pinMode(i, INPUT);
          }
          Serial.println("set to INPUT!");
        }
        else
          Serial.println("nothing");
        break;

      case 'o':
        Serial.println("\nSetting all pins to output.");
        Serial.print("hit e char to confirm: ");
        while(!Serial.available());
        if(Serial.read() == 'e'){
          RGB.color(0, 0, 255); //blue
          for (uint8_t i=0;i<7;i++){
            mcp1.pinMode(i, OUTPUT);
            mcp2.pinMode(i, OUTPUT);
          }
          Serial.println("set to OUTPUT!");
        }
        else
          Serial.println("nothing");
        break;

      case 'r':
        RGB.color(0, 0, 255); //blue
        Serial.print("\nMCP 01 pin status: ");
        Serial.println(mcp1.readGPIO());
        Serial.print("\nMCP 02 pin status: ");
        Serial.println(mcp2.readGPIO());
        Serial.println("pin status read!");
        break;

      case 'u':
        RGB.color(0, 0, 255); //blue
        Serial.println("\nSetting all pins to Pull-up.");
        Serial.print("hit e char to confirm: ");
        while(!Serial.available());
        if(Serial.read() == 'e'){
          RGB.color(0, 0, 255); //blue
          for (uint8_t i=0;i<7;i++){
            mcp1.pullUp(i, HIGH);
            mcp2.pullUp(i, HIGH);
          }
          Serial.println("set to Pull-up!");
        }
        else
          Serial.println("nothing");
        break;

      case 'd':
        RGB.color(0, 0, 255); //blue
        Serial.println("\nSetting all pins to Pull-down.");
        Serial.print("hit e char to confirm: ");
        while(!Serial.available());
        if(Serial.read() == 'e'){
          RGB.color(0, 0, 255); //blue
          for (uint8_t i=0;i<7;i++){
            mcp1.pullUp(i, LOW);
            mcp2.pullUp(i, LOW);
          }
          Serial.println("set to Pull-down!");
        }
        else
          Serial.println("nothing");
        break;

      case 'h':
      default:
        Serial.print("\ncommands available: ");
        Serial.print("d");
        Serial.print(", ");
        Serial.print("i");
        Serial.print(", ");
        Serial.print("o");
        Serial.print(", ");
        Serial.print("p");
        Serial.print(", ");
        Serial.print("r");
        Serial.print(", ");
        Serial.print("u");
        Serial.print(", ");
        break;
    }

  while(Serial.available()) Serial.read();
  RGB.color(0, 255, 0); //green
  }
}

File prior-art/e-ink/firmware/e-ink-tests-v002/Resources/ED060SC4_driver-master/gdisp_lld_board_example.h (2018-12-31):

/*
 * 2013 Petteri Aimonen <jpa@gfx.mail.kapsi.fi>
 * This file is released to the public domain.
 *
 */

/* Board interface definitions for ED060SC4 PrimeView E-ink panel.
 *
 * This file corresponds to the connections shown in example_schematics.png,
 * and is designed to interface with ChibiOS/RT.
 *
 * Please note that this file has never been tested in exactly this pin
 * configuration, because the actual boards I have are slightly different.
 */

#ifndef _GDISP_LLD_BOARD_H
#define _GDISP_LLD_BOARD_H

#include <hal.h>

/*
 * IO pins assignments.
 */
#define GPIOB_EINK_VDD      0
#define GPIOB_EINK_GMODE    1
#define GPIOB_EINK_SPV      2
#define GPIOB_EINK_CKV      3
#define GPIOB_EINK_CL       4
#define GPIOB_EINK_LE       5
#define GPIOB_EINK_OE       6
#define GPIOB_EINK_SPH      7
#define GPIOB_EINK_D0       8
#define GPIOB_EINK_D1       9
#define GPIOB_EINK_D2       10
#define GPIOB_EINK_D3       11
#define GPIOB_EINK_D4       12
#define GPIOB_EINK_D5       13
#define GPIOB_EINK_D6       14
#define GPIOB_EINK_D7       15

#define GPIOC_SMPS_CTRL     13
#define GPIOC_VPOS_CTRL     14
#define GPIOC_VNEG_CTRL     15


/* Set up IO pins for the panel connection. */
static inline void init_board(void) {
    /* Main SMPS power control, active low
     * (open collector so that MOSFET gate can be pulled up to Vbat) */
    palWritePad(GPIOC, GPIOC_SMPS_CTRL, true);
    palSetPadMode(GPIOC, GPIOC_SMPS_CTRL, PAL_MODE_OUTPUT_OPENDRAIN);

    /* Power control for the positive & negative side */
    palWritePad(GPIOC, GPIOC_VPOS_CTRL, false);
    palSetPadMode(GPIOC, GPIOC_VPOS_CTRL, PAL_MODE_OUTPUT_PUSHPULL);
    palWritePad(GPIOC, GPIOC_VNEG_CTRL, false);
    palSetPadMode(GPIOC, GPIOC_VNEG_CTRL, PAL_MODE_OUTPUT_PUSHPULL);

    /* Main data bus */
    palWritePort(GPIOB, 0);
    palSetGroupMode(GPIOB, 0xFFFF, 0, PAL_MODE_OUTPUT_PUSHPULL);
}

/* Delay for display waveforms. Should be an accurate microsecond delay. */
static void eink_delay(int us)
{
    halPolledDelay(US2RTT(us));
}

/* Turn the E-ink panel Vdd supply (+3.3V) on or off. */
static inline void setpower_vdd(bool_t on) {
    palWritePad(GPIOB, GPIOB_SMPS_CTRL, !on);
    palWritePad(GPIOA, GPIOA_EINK_VDD, on);
}

/* Turn the E-ink panel negative supplies (-15V, -20V) on or off. */
static inline void setpower_vneg(bool_t on) {
    palWritePad(GPIOA, GPIOA_VNEG_CTRL, on);
}

/* Turn the E-ink panel positive supplies (-15V, -20V) on or off. */
static inline void setpower_vpos(bool_t on) {
    palWritePad(GPIOA, GPIOA_VPOS_CTRL, on);
}

/* Set the state of the LE (source driver Latch Enable) pin. */
static inline void setpin_le(bool_t on) {
    palWritePad(GPIOB, GPIOB_EINK_LE, on);
}

/* Set the state of the OE (source driver Output Enable) pin. */
static inline void setpin_oe(bool_t on) {
    palWritePad(GPIOB, GPIOB_EINK_OE, on);
}

/* Set the state of the CL (source driver Clock) pin. */
static inline void setpin_cl(bool_t on) {
    palWritePad(GPIOB, GPIOB_EINK_CL, on);
}

/* Set the state of the SPH (source driver Start Pulse Horizontal) pin. */
static inline void setpin_sph(bool_t on) {
    palWritePad(GPIOB, GPIOB_EINK_SPH, on);
}

/* Set the state of the D0-D7 (source driver Data) pins. */
static inline void setpins_data(uint8_t value) {
    palWriteGroup(GPIOB, 0xFF, GPIOB_EINK_D0, value);
}

/* Set the state of the CKV (gate driver Clock Vertical) pin. */
static inline void setpin_ckv(bool_t on) {
    palWritePad(GPIOB, GPIOB_EINK_CKV, on);
}

/* Set the state of the GMODE (gate driver Gate Mode) pin. */
static inline void setpin_gmode(bool_t on) {
    palWritePad(GPIOC, GPIOC_EINK_GMODE, on);
}

/* Set the state of the SPV (gate driver Start Pulse Vertical) pin. */
static inline void setpin_spv(bool_t on) {
    palWritePad(GPIOB, GPIOB_EINK_SPV, on);
}

#endif

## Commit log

2017-04-23 add: Converting Seeed OPL EagleCAD library to KiCad
2017-05-17 add: Wireless Protocols for IoT Devices
2017-06-01 add: Article on capacitor temp and V rating
2017-06-16 Add: Minimizing Converter High-Frequency Switching Noise
2017-08-14 add: pdf for eink schematic
2017-09-11 add: CAN bus resource
2018-12-31 added in Teds stuff from dropbox
    [STM32-pinmap.xlsx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]
2019-01-01 Added ESP / WISE e-ink driver
    [buttonboard.brd, buttonboard.sch, wiseboard.brd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]
2019-01-02 removed extraneous files, reorganized dirs, removed license, updated readme
    [STM32-pinmap.xlsx, SenseSing-prog-adaptor-v0.1.brd, SenseSing-prog-adaptor-v0.1.sch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]
2019-01-06 added power sequencing doc
2019-01-06 added note about ESP32 modules
2019-01-06 added power rail table
2019-01-14 adding the kicad stuff. just the +20V/-22V supply for now
    [e-ink.kicad_pcb, e-ink.sch]
2019-01-14 added my kicad library
2019-01-20 added VCOM conditioner
    [e-ink.sch]
2019-01-20 added 3.3v buck and annotations. PSUs done
    [e-ink.sch]
2019-02-04 reorganized schems and added a note about buffer
    [e-ink.sch, interface.sch, power.sch]
2019-02-25 added 74LCX16244
    [interface.sch]
2019-11-19 I think the schematic is done. ugly but feature-complete
    [e-ink.sch, eink.sch]
2019-11-20 added additional SMPS control transistor circuit
    [eink.sch]
2019-11-20 added not about passive size
    [eink.sch]
2019-12-03 recovered from an unplanned poweroff, and removed backup files
    [e-ink.sch, eink.sch, interface.sch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]

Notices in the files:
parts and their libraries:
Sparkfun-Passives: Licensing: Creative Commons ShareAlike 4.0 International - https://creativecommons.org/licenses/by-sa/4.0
